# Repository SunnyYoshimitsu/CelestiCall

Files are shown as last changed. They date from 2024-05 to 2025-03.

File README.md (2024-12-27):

# CelestiCall
 An attempt at making a somewhat modern smartphone with many functions. 

CelestiCall is a phone with a somewhat outdated concept that I've come up with for the Summer of 2024. The purpose of the phone? to allow me to learn and get experience on many computer subjects all at once. 
And what are those "experience" and "subjects" I'm talking about? They're power system design, FPGA design, 3D printing, communication, Linux, web design and many more.

Let me tell about what I see this phone will have as I want this to be unique and with quite a large amount of personal touch up. 
1) This phone will be running on an FPGA, specifically Zynq FPGAs. This is because I want to learn about how to create a whole SoC from scratch (with a hardcore A9 of course), as this will teach me about the SoC design and more. 
2) It will serve as both a phone and as a portable small Linux computer with HDMI. This is one reason why I said the concept is a little outdated as many modern phone can just screen share to TV and call it a day. However since my phone won't be in any of the TV's ecosystem, I will "cheat" and have it "screen-share" via HDMI. My inspiration is the ChromeBit and the Motorola Atrix HD.
3) I also will have a web "program" very much similar to what ChromeOS offer but obviously way more bootleg as it will be made by one person. This is a way that I will be able to artificially extend the power of the little device by having many computing heavy problems or storage be on the cloud. 

Here I'll go into a personal requirement for what I think the smartphone should be and have. I'll describe the software and the hardware along with the type of apps I would like to have running on it.

Requirement: 
* Interaction : All modern smartphone have touchscreens and really that's one of the reason that started the smartphone trend. I might add some physical buttons but that's up for considerations.
* 
* Communication : A phone is not a phone if one can't call from it. I'll make the phone being able to use 4G and possibly 5G as 3G and below at least in the US is defunct. Also this hopefully will allow the phone to access the internet.
* 
* Usage Time : The target is the battery lasting up to a whole day on a single charge on heavy use. I will go into what "heavy use" entails later.
* 
* Operating System : Linux is a must and also more like an existing distro. If possible and if the system is powerful enough I might use Android(possibly 2.0) since I don't have the manpower to make my own softwares.
There wil be this much requirement for now, it might be changed later.

Hardware: 
Physical dimesion: Similar to that of Iphone I or the various Window phones. 
                   Small and comact as to be able to reach from bottom of the screen to the top. 
                   
Computer Hardware: Runs off dual Cortex A9 on an FPGA and hopefully give up to 2GB of RAM. 
                   ARM A9 is a relative strong chips that could run many lightweight Linux distro without much problem. 

Software: 
Onboard-based: Android 2.0 would be preferrable
               It's a widely used distro with a lot of available softwares
               
Web-based: Something like a personal/homebrew Google Drive and the ability to use a home server as extra computing extension and a NAS as online hard-drive. 
           This would allow the device to be more than it can be

Here's the architecture of the SoC would look like: 
Note: if there's an asterisk, it means that that specific part will be custom. 
CelestiSoC

Roadmap

*Software to make calls, use WiFi, send/receive SMS, GPS and take photos in any GNU/linux:
    Estimated Time: ~5 months
    
    With hardware:
                  A7670G with ESP32: https://github.com/Xinyuan-LilyGO/LilyGO-T-A76XX
                  Quectel: https://www.aliexpress.us/item/3256806123411827.html?src=google&gatewayAdapt=glo2usa
    With software: 
                  Android 5 for Zedboard: https://github.com/noritsuna/zedroid_system_core?tab=readme-ov-file
                  Android 4 for Pynq Z2: https://xilinx-wiki.atlassian.net/wiki/spaces/A/pages/18842042/Android+4.2.2+On+Zynq+Getting+Started+Guide
                  AT commands for the GPRS 
                  Arduino C codes for ESP32 wiFi and BLE

*Touchscreen, buttons and audio I/Os:
    Estimated Time: ~2 months

    Note: as of 5/23/2024, I'm still deciding whether to pursue a phone with large or small screens. They could be as large as a modern Iphone Pro Max with screen going up to near 7inch or older phones with screen as small as 3-inch diagnally. 

    With hardware: 
                 Small 3.1 in screen: https://tailorpixels.com/product/3-1-inch-ips-tft-high-resolution-mipi/
                 Medium sized 5 in screen: https://tailorpixels.com/product/5-inch-tn-tft-lcd-rgb-800x480-landscape/
                 Large sized 7 in screen: https://tailorpixels.com/product/7-inch-tn-tft-lcd-rgb-800x480/
    With software: 
                 -For starter: a framebuffer in RAM
                 -End goal: running on a custom GPU (HyperNova)

The above two steps will be prototyped via COTS development boards and easy to use breadboard.

*Make a prototype PCB with components:

    Estimated Time: ~2 months 
    Estimated cost: ~$400

    1) Start with a simple FPGA board
    2) Add peripherals like the WiFI, GPRS and camera
    3) Add touchscreen and physical input (buttons)

 *Design and manufacture outer shell:
    Estimated Time: ~2 months
    Estimated cost: ~$50

    Design concept: The shell of the phone will be somewhat similar looking to any modern smartphone, however it will be thicker than the norm. This is to be able to accomodate at least two full size USB and HDMI ports along with possibly 2 PMODs interface. 

    With hardware: 
                 Bambu Lab 3D printer
    With software: 
                 Krita for concept art
                 Solidwork for the end product

 *End Step: 
    This step will involve the creation of the "bootleg Google Drive" that I've detailed in the beginning along with making a case for the phone.
     
Rough Project Timeline/Plans:
Rough Project Timeline

To do list/learn/plan(6/17):

Start making prototypes of the GPU and the Audio mixer
Then integrate them to a HDMI output

GPU: Learn about "CUDA" cores, make a RGB framebuffer of 800 x 600 size for the touchscreen output. Make variable screen resolution for HDMI out. 
Audio: extend upon school filter projects and DMA sound replay. 
       If too complicated, then make a simple PCM passthrough and FIFO for sound replay from memory. 

Integrate both GPU and Audio though the HyperNova top module to output to HDMI, display and audio jack. Add controls to allow versatile displaying. 
Possibly add possible VGA output for second display via the PMOD (max 64 colors only). 

I know this sounds ambitious as going to the moon by oneself. HOWEVER, with the way technology is evolving, I believe it's possible....Please let a student dream.....

Email: huynguyenwork123@gmail.com

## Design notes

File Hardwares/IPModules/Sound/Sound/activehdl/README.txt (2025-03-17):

################################################################################
# Vivado (TM) v2023.2 (64-bit)
#
# README.txt: Please read the sections below to understand the steps required to
#             run the exported script and how to fetch design source file details
#             from the file_info.txt file.
#
# Generated by export_simulation on Thu Jan 09 14:43:12 -0800 2025
#
################################################################################

1. Steps to run the generated simulation script

From the shell prompt in the current directory, issue the following command:-

./I2S_Mic_Wrapper.sh

This command will launch the 'compile', 'elaborate' and 'simulate' functions
implemented in the script file for the 3-step flow. These functions are called
from the main 'run' function in the script file.

The 'run' function first calls the 'check_args' function, the purpose of which
is to verify the generated script arguments and print error if incorrect switch
is specified. The 'run' function then calls the 'setup' function, the purpose of
which is to specify custom or initialization commands. The function also executes
following sub-functions:-
'reset_run' if -reset_run switch is specified.
'reset_log' if -reset_log switch is specified.

The purpose of 'reset_run' function' is to delete the simulator generated design
data from the previous run and the purpose of 'reset_log' function' is to delete
the simulator generated log files.

The 'run' function then calls the 'init_lib' function, the purpose of which is to
create design library mappings and directories. This function is called before the
'compile' step. By default, if '-step' switch is specified with the script then the
script will execute that specfic step, else it will execute all steps applicable
for the target simulator.

For more information on the script, please type './I2S_Mic_Wrapper.sh -help'

2. Design source file information

export_simulation generates a 'file_info.txt' file that contains design file information
based on the compile order when export_simulation was executed from Vivado. The file
contains information about the file name, type, library it is compiled into, whether
it is part of the IP, associated library, file path information in a comma separated
format. This file can be parsed to extract the required information for generating a
custom script or can be read from verification test infra.

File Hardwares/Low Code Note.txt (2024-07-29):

This folder will be for lower-level codes and developments like VHDL and Embedded C for smaller MCUs. Anything that is conventionally regarded as "hardware" or "Embedded programming" will be here. 

*Use LOLIN C3 Mini when programming the ESP32C3 SuperMini

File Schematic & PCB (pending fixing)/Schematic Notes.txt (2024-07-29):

7/16/2024:
The schematic and PCB have been updated and will be kept up to date in this folder. 

Changes for schematic involve removals of all former peripheral chips due to space constraints, low energy budget, and generally low utilities. 

Changes for PCB include 10% smaller sizes, more efficient/shorter traces, and new chip placements. 

7/28/2024:
Changed the SIM socket to a smaller one and fixed its direction

Add another PMOD plug and change both to SMD instead of through hole to allow for more space on the bottom side of PCB

Add more connection to the external MCU to allow usage of more types of MCU like ESP32s3 XIAO. 

Note: I've tried to explore some more external interfaces like a Mini PCIE on the side and M.2 slots. There are chances that I might try these ideas in the future. 
By the look of the direction of the project, I'm expecting the phone to be at least somewhat similar in performance to an iPhone 4G. The reason for this expectation
is due to both running the same CPU except the slower speed on my device.

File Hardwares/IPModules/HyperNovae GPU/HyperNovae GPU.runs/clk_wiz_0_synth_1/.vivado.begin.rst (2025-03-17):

<?xml version="1.0"?>
<ProcessHandle Version="1" Minor="0">
    <Process Command="vivado.bat" Owner="Hatsu" Host="DESKTOP-I4589KT" Pid="33956" HostCore="12" HostMemory="034246979584">
    </Process>
</ProcessHandle>

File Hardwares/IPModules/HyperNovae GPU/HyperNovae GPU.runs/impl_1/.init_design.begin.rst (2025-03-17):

<?xml version="1.0"?>
<ProcessHandle Version="1" Minor="0">
    <Process Command=".planAhead." Owner="Hatsu" Host="DESKTOP-I4589KT" Pid="7728">
    </Process>
</ProcessHandle>

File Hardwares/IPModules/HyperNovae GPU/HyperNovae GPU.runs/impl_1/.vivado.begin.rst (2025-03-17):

<?xml version="1.0"?>
<ProcessHandle Version="1" Minor="0">
    <Process Command="vivado.bat" Owner="Hatsu" Host="DESKTOP-I4589KT" Pid="32244" HostCore="12" HostMemory="034246979584">
    </Process>
</ProcessHandle>
<?xml version="1.0"?>
<ProcessHandle Version="1" Minor="0">
    <Process Command="vivado.bat" Owner="Hatsu" Host="DESKTOP-I4589KT" Pid="8500" HostCore="12" HostMemory="034246979584">
    </Process>
</ProcessHandle>
<?xml version="1.0"?>
<ProcessHandle Version="1" Minor="0">
    <Process Command="vivado.bat" Owner="Hatsu" Host="DESKTOP-I4589KT" Pid="32320" HostCore="12" HostMemory="034246979584">
    </Process>
</ProcessHandle>
<?xml version="1.0"?>
<ProcessHandle Version="1" Minor="0">
    <Process Command="vivado.bat" Owner="Hatsu" Host="DESKTOP-I4589KT" Pid="15256" HostCore="12" HostMemory="034246979584">
    </Process>
</ProcessHandle>
<?xml version="1.0"?>
<ProcessHandle Version="1" Minor="0">
    <Process Command="vivado.bat" Owner="Hatsu" Host="DESKTOP-I4589KT" Pid="34104" HostCore="12" HostMemory="034246979584">
    </Process>
</ProcessHandle>
<?xml version="1.0"?>
<ProcessHandle Version="1" Minor="0">
    <Process Command="vivado.bat" Owner="Hatsu" Host="DESKTOP-I4589KT" Pid="35856" HostCore="12" HostMemory="034246979584">
    </Process>
</ProcessHandle>
<?xml version="1.0"?>
<ProcessHandle Version="1" Minor="0">
    <Process Command="vivado.bat" Owner="Hatsu" Host="DESKTOP-I4589KT" Pid="35372" HostCore="12" HostMemory="034246979584">
    </Process>
</ProcessHandle>
<?xml version="1.0"?>
<ProcessHandle Version="1" Minor="0">
    <Process Command="vivado.bat" Owner="Hatsu" Host="DESKTOP-I4589KT" Pid="36468" HostCore="12" HostMemory="034246979584">
    </Process>
</ProcessHandle>
<?xml version="1.0"?>
<ProcessHandle Version="1" Minor="0">
    <Process Command="vivado.bat" Owner="Hatsu" Host="DESKTOP-I4589KT" Pid="15448" HostCore="12" HostMemory="034246979584">
    </Process>
</ProcessHandle>
<?xml version="1.0"?>
<ProcessHandle Version="1" Minor="0">
    <Process Command="vivado.bat" Owner="Hatsu" Host="DESKTOP-I4589KT" Pid="36788" HostCore="12" HostMemory="034246979584">
    </Process>
</ProcessHandle>
<?xml version="1.0"?>
<ProcessHandle Version="1" Minor="0">
    <Process Command="vivado.bat" Owner="Hatsu" Host="DESKTOP-I4589KT" Pid="36724" HostCore="12" HostMemory="034246979584">
    </Process>
</ProcessHandle>
<?xml version="1.0"?>
<ProcessHandle Version="1" Minor="0">
    <Process Command="vivado.bat" Owner="Hatsu" Host="DESKTOP-I4589KT" Pid="10980" HostCore="12" HostMemory="034246979584">
    </Process>
</ProcessHandle>
<?xml version="1.0"?>
<ProcessHandle Version="1" Minor="0">
    <Process Command="vivado.bat" Owner="Hatsu" Host="DESKTOP-I4589KT" Pid="36556" HostCore="12" HostMemory="034246979584">
    </Process>
</ProcessHandle>
<?xml version="1.0"?>
<ProcessHandle Version="1" Minor="0">
    <Process Command="vivado.bat" Owner="Hatsu" Host="DESKTOP-I4589KT" Pid="18424" HostCore="12" HostMemory="034246979584">
    </Process>
</ProcessHandle>
<?xml version="1.0"?>
<ProcessHandle Version="1" Minor="0">
    <Process Command="vivado.bat" Owner="Hatsu" Host="DESKTOP-I4589KT" Pid="25948" HostCore="12" HostMemory="034246979584">
    </Process>
</ProcessHandle>
<?xml version="1.0"?>
<ProcessHandle Version="1" Minor="0">
    <Process Command="vivado.bat" Owner="Hatsu" Host="DESKTOP-I4589KT" Pid="34744" HostCore="12" HostMemory="034246979584">
    </Process>
</ProcessHandle>
<?xml version="1.0"?>
<ProcessHandle Version="1" Minor="0">
    <Process Command="vivado.bat" Owner="Hatsu" Host="DESKTOP-I4589KT" Pid="36200" HostCore="12" HostMemory="034246979584">
    </Process>
</ProcessHandle>
<?xml version="1.0"?>
<ProcessHandle Version="1" Minor="0">
    <Process Command="vivado.bat" Owner="Hatsu" Host="DESKTOP-I4589KT" Pid="35748" HostCore="12" HostMemory="034246979584">
    </Process>
</ProcessHandle>
<?xml version="1.0"?>
<ProcessHandle Version="1" Minor="0">
    <Process Command="vivado.bat" Owner="Hatsu" Host="DESKTOP-I4589KT" Pid="12492" HostCore="12" HostMemory="034246979584">
    </Process>
</ProcessHandle>
<?xml version="1.0"?>
<ProcessHandle Version="1" Minor="0">
    <Process Command="vivado.bat" Owner="Hatsu" Host="DESKTOP-I4589KT" Pid="33684" HostCore="12" HostMemory="034246979584">
    </Process>
</ProcessHandle>
<?xml version="1.0"?>
<ProcessHandle Version="1" Minor="0">
    <Process Command="vivado.bat" Owner="Hatsu" Host="DESKTOP-I4589KT" Pid="17684" HostCore="12" HostMemory="034246979584">
    </Process>
</ProcessHandle>
<?xml version="1.0"?>
<ProcessHandle Version="1" Minor="0">
    <Process Command="vivado.bat" Owner="Hatsu" Host="DESKTOP-I4589KT" Pid="3300" HostCore="12" HostMemory="034246979584">
    </Process>
</ProcessHandle>
<?xml version="1.0"?>
<ProcessHandle Version="1" Minor="0">
    <Process Command="vivado.bat" Owner="Hatsu" Host="DESKTOP-I4589KT" Pid="35892" HostCore="12" HostMemory="034246979584">
    </Process>
</ProcessHandle>
<?xml version="1.0"?>
<ProcessHandle Version="1" Minor="0">
    <Process Command="vivado.bat" Owner="Hatsu" Host="DESKTOP-I4589KT" Pid="36440" HostCore="12" HostMemory="034246979584">
    </Process>
</ProcessHandle>
<?xml version="1.0"?>
<ProcessHandle Version="1" Minor="0">
    <Process Command="vivado.bat" Owner="Hatsu" Host="DESKTOP-I4589KT" Pid="16936" HostCore="12" HostMemory="034246979584">
    </Process>
</ProcessHandle>
<?xml version="1.0"?>
<ProcessHandle Version="1" Minor="0">
    <Process Command="vivado.bat" Owner="Hatsu" Host="DESKTOP-I4589KT" Pid="34304" HostCore="12" HostMemory="034246979584">
    </Process>
</ProcessHandle>
<?xml version="1.0"?>
<ProcessHandle Version="1" Minor="0">
    <Process Command="vivado.bat" Owner="Hatsu" Host="DESKTOP-I4589KT" Pid="1524" HostCore="12" HostMemory="034246979584">
    </Process>
</ProcessHandle>
<?xml version="1.0"?>
<ProcessHandle Version="1" Minor="0">
    <Process Command="vivado.bat" Owner="Hatsu" Host="DESKTOP-I4589KT" Pid="35532" HostCore="12" HostMemory="034246979584">
    </Process>
</ProcessHandle>
<?xml version="1.0"?>
<ProcessHandle Version="1" Minor="0">
    <Process Command="vivado.bat" Owner="Hatsu" Host="DESKTOP-I4589KT" Pid="22812" HostCore="12" HostMemory="034246979584">
    </Process>
</ProcessHandle>
<?xml version="1.0"?>
<ProcessHandle Version="1" Minor="0">
    <Process Command="vivado.bat" Owner="Hatsu" Host="DESKTOP-I4589KT" Pid="17148" HostCore="12" HostMemory="034246979584">
    </Process>
</ProcessHandle>
<?xml version="1.0"?>
<ProcessHandle Version="1" Minor="0">
    <Process Command="vivado.bat" Owner="Hatsu" Host="DESKTOP-I4589KT" Pid="26016" HostCore="12" HostMemory="034246979584">
    </Process>
</ProcessHandle>
<?xml version="1.0"?>
<ProcessHandle Version="1" Minor="0">
    <Process Command="vivado.bat" Owner="Hatsu" Host="DESKTOP-I4589KT" Pid="14236" HostCore="12" HostMemory="034246979584">
    </Process>
</ProcessHandle>
<?xml version="1.0"?>
<ProcessHandle Version="1" Minor="0">
    <Process Command="vivado.bat" Owner="Hatsu" Host="DESKTOP-I4589KT" Pid="7360" HostCore="12" HostMemory="034246979584">
    </Process>
</ProcessHandle>
<?xml version="1.0"?>
<ProcessHandle Version="1" Minor="0">
    <Process Command="vivado.bat" Owner="Hatsu" Host="DESKTOP-I4589KT" Pid="7356" HostCore="12" HostMemory="034246979584">
    </Process>
</ProcessHandle>
<?xml version="1.0"?>
<ProcessHandle Version="1" Minor="0">
    <Process Command="vivado.bat" Owner="Hatsu" Host="DESKTOP-I4589KT" Pid="34080" HostCore="12" HostMemory="034246979584">
    </Process>
</ProcessHandle>
<?xml version="1.0"?>
<ProcessHandle Version="1" Minor="0">
    <Process Command="vivado.bat" Owner="Hatsu" Host="DESKTOP-I4589KT" Pid="35532" HostCore="12" HostMemory="034246979584">
    </Process>
</ProcessHandle>
<?xml version="1.0"?>
<ProcessHandle Version="1" Minor="0">
    <Process Command="vivado.bat" Owner="Hatsu" Host="DESKTOP-I4589KT" Pid="34820" HostCore="12" HostMemory="034246979584">
    </Process>
</ProcessHandle>
<?xml version="1.0"?>
<ProcessHandle Version="1" Minor="0">
    <Process Command="vivado.bat" Owner="Hatsu" Host="DESKTOP-I4589KT" Pid="8448" HostCore="12" HostMemory="034246979584">
    </Process>
</ProcessHandle>
<?xml version="1.0"?>
<ProcessHandle Version="1" Minor="0">
    <Process Command="vivado.bat" Owner="Hatsu" Host="DESKTOP-I4589KT" Pid="26908" HostCore="12" HostMemory="034246979584">
    </Process>
</ProcessHandle>
<?xml version="1.0"?>
<ProcessHandle Version="1" Minor="0">
    <Process Command="vivado.bat" Owner="Hatsu" Host="DESKTOP-I4589KT" Pid="17220" HostCore="12" HostMemory="034246979584">
    </Process>
</ProcessHandle>
<?xml version="1.0"?>
<ProcessHandle Version="1" Minor="0">
    <Process Command="vivado.bat" Owner="Hatsu" Host="DESKTOP-I4589KT" Pid="16024" HostCore="12" HostMemory="034246979584">
    </Process>
</ProcessHandle>
<?xml version="1.0"?>
<ProcessHandle Version="1" Minor="0">
    <Process Command="vivado.bat" Owner="Hatsu" Host="DESKTOP-I4589KT" Pid="7060" HostCore="12" HostMemory="034246979584">
    </Process>
</ProcessHandle>
<?xml version="1.0"?>
<ProcessHandle Version="1" Minor="0">
    <Process Command="vivado.bat" Owner="Hatsu" Host="DESKTOP-I4589KT" Pid="5208" HostCore="12" HostMemory="034246979584">
    </Process>
</ProcessHandle>
<?xml version="1.0"?>
<ProcessHandle Version="1" Minor="0">
    <Process Command="vivado.bat" Owner="Hatsu" Host="DESKTOP-I4589KT" Pid="6940" HostCore="12" HostMemory="034246979584">
    </Process>
</ProcessHandle>
<?xml version="1.0"?>
<ProcessHandle Version="1" Minor="0">
    <Process Command="vivado.bat" Owner="Hatsu" Host="DESKTOP-I4589KT" Pid="6084" HostCore="12" HostMemory="034246979584">
    </Process>
</ProcessHandle>
<?xml version="1.0"?>
<ProcessHandle Version="1" Minor="0">
    <Process Command="vivado.bat" Owner="Hatsu" Host="DESKTOP-I4589KT" Pid="2804" HostCore="12" HostMemory="034246979584">
    </Process>
</ProcessHandle>
<?xml version="1.0"?>
<ProcessHandle Version="1" Minor="0">
    <Process Command="vivado.bat" Owner="Hatsu" Host="DESKTOP-I4589KT" Pid="37344" HostCore="12" HostMemory="034246979584">
    </Process>
</ProcessHandle>
<?xml version="1.0"?>
<ProcessHandle Version="1" Minor="0">
    <Process Command="vivado.bat" Owner="Hatsu" Host="DESKTOP-I4589KT" Pid="22904" HostCore="12" HostMemory="034246979584">
    </Process>
</ProcessHandle>
<?xml version="1.0"?>
<ProcessHandle Version="1" Minor="0">
    <Process Command="vivado.bat" Owner="Hatsu" Host="DESKTOP-I4589KT" Pid="5032" HostCore="12" HostMemory="034246979584">
    </Process>
</ProcessHandle>
<?xml version="1.0"?>
<ProcessHandle Version="1" Minor="0">
    <Process Command="vivado.bat" Owner="Hatsu" Host="DESKTOP-I4589KT" Pid="35320" HostCore="12" HostMemory="034246979584">
    </Process>
</ProcessHandle>
<?xml version="1.0"?>
<ProcessHandle Version="1" Minor="0">
    <Process Command="vivado.bat" Owner="Hatsu" Host="DESKTOP-I4589KT" Pid="7100" HostCore="12" HostMemory="034246979584">
    </Process>
</ProcessHandle>
<?xml version="1.0"?>
<ProcessHandle Version="1" Minor="0">
    <Process Command="vivado.bat" Owner="Hatsu" Host="DESKTOP-I4589KT" Pid="9372" HostCore="12" HostMemory="034246979584">
    </Process>
</ProcessHandle>
<?xml version="1.0"?>
<ProcessHandle Version="1" Minor="0">
    <Process Command="vivado.bat" Owner="Hatsu" Host="DESKTOP-I4589KT" Pid="2136" HostCore="12" HostMemory="034246979584">
    </Process>
</ProcessHandle>
<?xml version="1.0"?>
<ProcessHandle Version="1" Minor="0">
    <Process Command="vivado.bat" Owner="Hatsu" Host="DESKTOP-I4589KT" Pid="30524" HostCore="12" HostMemory="034246979584">
    </Process>
</ProcessHandle>
<?xml version="1.0"?>
<ProcessHandle Version="1" Minor="0">
    <Process Command="vivado.bat" Owner="Hatsu" Host="DESKTOP-I4589KT" Pid="3408" HostCore="12" HostMemory="034246979584">
    </Process>
</ProcessHandle>
<?xml version="1.0"?>
<ProcessHandle Version="1" Minor="0">
    <Process Command="vivado.bat" Owner="Hatsu" Host="DESKTOP-I4589KT" Pid="17192" HostCore="12" HostMemory="034246979584">
    </Process>
</ProcessHandle>

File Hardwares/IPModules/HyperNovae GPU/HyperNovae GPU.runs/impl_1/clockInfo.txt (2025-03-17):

-------------------------------------
| Tool Version : Vivado v.2023.2
| Date         : Thu Jan  9 13:47:08 2025
| Host         : DESKTOP-I4589KT
| Design       : design_1
| Device       : xc7a100t-csg324-1--
-------------------------------------

For more information on clockInfo.txt clock routing debug file see https://support.xilinx.com/s/article/000035660?language=en_US

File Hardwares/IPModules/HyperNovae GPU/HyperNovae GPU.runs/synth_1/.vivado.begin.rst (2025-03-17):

<?xml version="1.0"?>
<ProcessHandle Version="1" Minor="0">
    <Process Command="vivado.bat" Owner="Hatsu" Host="DESKTOP-I4589KT" Pid="31948" HostCore="12" HostMemory="034246979584">
    </Process>
</ProcessHandle>

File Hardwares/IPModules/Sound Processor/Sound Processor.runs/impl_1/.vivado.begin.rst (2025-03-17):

<?xml version="1.0"?>
<ProcessHandle Version="1" Minor="0">
    <Process Command="vivado.bat" Owner="Hatsu" Host="DESKTOP-I4589KT" Pid="37040" HostCore="12" HostMemory="034246979584">
    </Process>
</ProcessHandle>
<?xml version="1.0"?>
<ProcessHandle Version="1" Minor="0">
    <Process Command="vivado.bat" Owner="Hatsu" Host="DESKTOP-I4589KT" Pid="37724" HostCore="12" HostMemory="034246979584">
    </Process>
</ProcessHandle>

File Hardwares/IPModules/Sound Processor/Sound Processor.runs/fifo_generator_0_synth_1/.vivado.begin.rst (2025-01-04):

<?xml version="1.0"?>
<ProcessHandle Version="1" Minor="0">
    <Process Command="vivado.bat" Owner="Hatsu" Host="DESKTOP-I4589KT" Pid="11940" HostCore="12" HostMemory="034246979584">
    </Process>
</ProcessHandle>

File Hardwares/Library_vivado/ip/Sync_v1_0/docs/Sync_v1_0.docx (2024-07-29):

# 1 Introduction

IP quick facts
Supported device families | Zynq®-7000, 7 series
Supported user interfaces | N/A

Provided with core
Design files | VHDL
Simulation model | VHDL Behavioral
Constraints file | XDC
Software driver | N/A

Tested design flows
Design entry | Vivado™ Design Suite 2015.3
Synthesis | Vivado Synthesis 2015.3

This user guide describes the Digilent Sync Intellectual Property. This IP provides clock domain crossing for signals where variable crossing latency does not affect functionality.

# 2 Features

- Brings global reset into a local clock domain where reset has to be synchronously de-asserted
- Brings asynchronous signal into a synchronous domain

# 3 Performance

No clock constraints are defined in this IP. Maximum frequency depends on the switching performance of flip-flops and the IP should not be the limiting factor in timing closure.

The IP properly defines false path constraints between source and destination clock domains.

# 4 Use cases

Figure 1. Sync internal diagram

The IP instantiates flip-flops and forms a chain that passes the input signal (iIn) towards the output (oOut). The first flip-flop is optional and works on the input (source) clock domain. It re-registers the input to make sure the downstream synchronizer chain has a glitch-free input. All the other flip-flops work on the output (destination) clock domain and each lowers the chance of failure due to metastability by increasing the time available for these events to settle. The number of synchronizer stages can be customized in the IP configuration wizard.

## Local reset

Consider a global reset signal that is asynchronous to a local clock domain you wish to reset. Depending on the application it might be important to de-assert the reset synchronous to the local clock, so that it can be guaranteed that all circuits come out of reset simultaneously. Reset assertion remains asynchronous, which is useful in cases where the local clock can be stopped.

Specify the correct polarity for the input reset signal in IP configuration and tie it to the aRst or aRst_n pin. Configure the output reset value to 0 or 1, depending on the desired polarity of the output reset signal. The input pin iIn should be tied to the constant inactive value of the output reset. Re-registering iIn is not required in this use case.

## Asynchronous input

Any input signal asynchronous to circuits it is connected to has the chance to become metastable. Using synchronizers lowers the chance of failure significantly. If the source clock of the input is known (synchronous to a known clock domain), tick “Re-register input on its source domain” and connect the source clock to InClk. If the source clock is not available, disable this option. Connecting a reset is optional and can be left unconnected.

# 5 Port Descriptions

Signal Name | Interface | Signal Type | Init State | Description
aRst(_n) | - | I | N/A | Asynchronous reset of configurable polarity. Optional
InClk | - | I | N/A | Source clock for iIn. Optional
OutClk | - | I | N/A | Destination clock for oOut.
iIn | - | I | N/A | Input signal to be synchronized.
oOut | - | O | configurable | Input iIn synchronized to OutClk.

Table 1. Port descriptions.

# 6 Designing with the core

## Customization

The IP provides four customizable parameters: the polarity of reset signal, the reset value of oOut, option to re-register iIn, and the number of synchronizer stages to use.

Copyright Digilent, Inc. All rights reserved. Other product and company names mentioned may be trademarks of their respective owners. Page 2 of 3

DOC#: 516-003 Copyright Digilent, Inc. All rights reserved. Other product and company names mentioned may be trademarks of their respective owners. Page 1 of 3

Sync 1.0 IP Core User Guide

1300 Henley Court Pullman, WA 99163 509.334.6306 www.digilentinc.com Sync 1.0 IP Core User Guide Revised October 7, 2016; Author Elod Gyorgy

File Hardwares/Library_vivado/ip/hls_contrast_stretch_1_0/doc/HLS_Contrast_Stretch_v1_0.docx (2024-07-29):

# 1 Introduction

IP quick facts
Supported device families | Zynq®-7000, 7 series
Supported user interfaces | Axi-Lite Axi-Stream

Provided with core
Design files | C++
Simulation model | HLS Simulation
Constraints file | XDC
Software driver | Automatically generated

Tested design flows
Design entry | Vivado™ Design Suite 2017.4
Synthesis | Vivado Synthesis 2017.4

This user guide describes the Digilent Contrast Enhancement Intellectual Property. This IP interfaces to both the Axi-Lite and Axi-Stream in order to process a video stream and control the resolution and the contrast factor.

# 2 Features

- Axi- Stream 24-bit video input and output
- Axi-Lite interface for contrast and resolution control
- Resolution supported: up to 1920x1080/60Hz (clock: 148.5 MHz)
- Contrast adjustment based on programable minimum and maximum thresholds

# 3 Performance

The IP has been written in HLS with a target clock frequency of 150 MHz (6.67 ns) for a maximum resolution of 1920x1080. The maximum latency is at 2101693 ns with an initiation interval of 2101682 ns which is approximately one frame. The latency and initiation interval are scaled with the input resolution, meaning that a lower resolution the latency will also be lower.

# 4 Usage

The IP has been initially designed for a xc7z020clg400-1 target device, the resource usage for this FPGA are illustrated in

Name | BRAM-18K | DSP48E | FF | LUT
DSP | - | - | - | -
Expression | - | - | 0 | 8
FIFO | 0 | - | 125 | 572
Instance | 0 | 9 | 2969 | 4003
Memory | - | - | - | -
Multiplexer | - | - | - | -
Register | - | - | - | -
Total | 0 | 9 | 3094 | 4583
Utilization(%) | 0 | 4 | 2 | 8

Table 1 FPGA usage

# 5 Overview

The IP core has been written entirely in Vivado HLS by using the HLS Video Library provided by Xilinx and a custom contrast enhancement function written by the author. The enhancement is done by contrast stretching based on the minimum and maximum thresholds in absolute value. Thresholds and resolution are programable using AXI-Lite.

## Processing

The input format for the image/video stream is the Axi-stream interface which can accept 24 bits of RGB data (8 bit/color) respecting the Xilinx video format. Before the actual contrast enhancement, the input stream is converted in to a matrix format with de height and width corresponding to the resolution of the input image, this is done using the HLS Video Library function AXIvideo2cvMat. The obtained matrix is the RGB color space, to be able to change the contrast value without effecting the other components of the image a different color space hade to be chosen; based on the functions of the HLS Video Library the YCbCr color space has been chosen. Conversion from RGB to YCbCr is done using the CvtColor provided by the video library.

Once the contrast processing has been finished the image must be converted back to RGB color space and outputted to the Axi-Stream interface. The output Axi-Stream interface has the same format as the input Axi-Stream interface.

## Contrast stretch

This IP core performs contrast enhancement by using a simple linear contrast stretching algorithm which will set the every below the chosen minimum threshold to 0 and everything above the maximum threshold to 255, thus the histogram of the image is stretched. For a graphic representation of the algorithm please refer to the following figure.

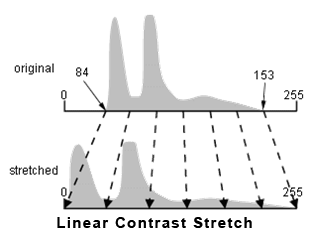
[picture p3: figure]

Figure 1. Contrast enhancement

Mathematically the function can be express by the following equation.

f(x)={, 0, &src.cont<min, ((src.cont-min))/((max-min))*255, &src.cont ∈[min;max], 255, &src.cont>max

## HLS directives

The used directives for this IP core have been added to the source files, for further information on how they work and how to use them please refer to UG902: High-Level Synthesis by Xilinx.

## Axi-Lite

The Axi-Lite interface is defined using HLS and controls three input variables of the main contrast stretching function. Using this interface, the user can change the resolution of both the input and the output image to a maximum of 1920x1080 and the desired contrast thresholds. Access to these parameters is provided via the automatically generated software driver, which respects the format of software drivers provided by Xilinx.

To change the minimum and the maximum thresholds, the function XHls_contrast_stretch_Set_min and XHls_contrast_stretch_CSet_max must be called.

# 6 Port Descriptions

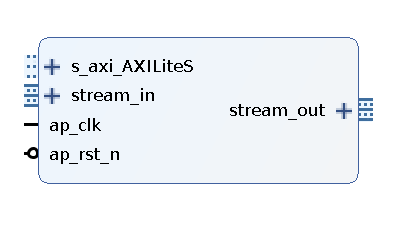
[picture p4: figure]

Figure 2 HLS Contrast Stretch IP core

Signal Name | Interface | Signal Type | Init State | Description
Ap_rst_n | - | I | N/A | Asynchronous reset for the core
ap_clk | - | I | N/A | Clock for the IP core, used for Stream in/output and Axi-Lite
s_axi_AXILiteS* | Axi-Lite | I | N/A | Axi-Lite interface used to configure height, width and contrast thresholds
stream_in | Axi-Stream | I | N/A | Input video stream on 24 bits, using Xilinx video format
stream_out | Axi-Stream | O | N/A | Output video stream on 24 bits, using Xilinx video format

Table 2. Port descriptions.

# 7 Designing with the core

## Customization

The currently IP core has been packaged for a maximum frequency of 150 MHz and a maximum resolution of 1920x1080 designed for a Zynq xc7z020clg400-1 device. Fur customization and further changes please create a HLS project and import all the files provided in the hls_src folder of the IP.

# 8 References

The following document provides additional information on the subjects discussed:

1. Xilinx Inc., UG902: High-Level Synthesis, v2017.4, February 2, 2018.

Copyright Digilent, Inc. All rights reserved. Other product and company names mentioned may be trademarks of their respective owners. Page 2 of 3

DOC#: 516-003 Copyright Digilent, Inc. All rights reserved. Other product and company names mentioned may be trademarks of their respective owners. Page 1 of 3

Sync 1.0 IP Core User Guide

1300 Henley Court Pullman, WA 99163 509.334.6306 www.digilentinc.com HLS Contrast Stretch 1.0 IP Core User Guide Revised June 21, 2018; Author Ciprian Hegbeli

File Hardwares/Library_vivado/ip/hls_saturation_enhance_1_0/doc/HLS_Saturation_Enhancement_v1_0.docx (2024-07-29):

# 1 Introduction

IP quick facts
Supported device families | Zynq®-7000, 7 series
Supported user interfaces | Axi-Lite Axi-Stream

Provided with core
Design files | C++
Simulation model | HLS Simulation
Constraints file | XDC
Software driver | Automatically generated

Tested design flows
Design entry | Vivado™ Design Suite 2017.4
Synthesis | Vivado Synthesis 2017.4

This user guide describes the Digilent Saturation Enhancement Intellectual Property. This IP interfaces to both the Axi-Lite and Axi-Stream in order to process a video stream and control the resolution and the saturation factor.

# 2 Features

- Axi- Stream 24-bit video input and output
- Axi-Lite interface for saturation and resolution control
- Resolution supported: up to 1920x1080/60Hz (clock: 148.5 MHz)
- Saturation adjustment: -0.2, 0.2, 0.4, 0.6, 0.8, 1.0, 1.2

# 3 Performance

The IP has been written in HLS with a target clock frequency of 150 MHz (6.67 ns) for a maximum resolution of 1920x1080. The maximum latency is at 2111405 ns with an initiation interval of 2111402 ns which is approximately one frame. The latency and initiation interval are scaled with the input resolution, meaning that a lower resolution the latency will also be lower.

# 4 Usage

The IP has been initially designed for a xc7z020clg400-1 target device, the resource usage for this FPGA are illustrated in

Name | BRAM-18K | DSP48E | FF | LUT
DSP | - | - | - | -
Expression | - | - | 0 | 8
FIFO | 0 | - | 115 | 532
Instance | 7 | 8 | 7850 | 6809
Memory | - | - | - | -
Multiplexer | - | - | - | -
Register | - | - | - | -
Total | 7 | 8 | 7965 | 7349
Utilization(%) | 2 | 3 | 7 | 13

Table 1 FPGA usage

# 5 Overview

The IP core has been written entirely in Vivado HLS by using the HLS Video Library provided by Xilinx and a custom saturation enhancement function written by the author. In order to minimize the resource cost of the IP core, the value of the saturation have been precompiled and stored in to lookup tables. The selection of the desired saturation is done using a simple case structure which multiplexes the LUTs which will be implemented.

## Processing

The input format for the image/video stream is the Axi-stream interface which can accept 24 bits of RGB data (8 bit/color) respecting the Xilinx video format. Before the actual saturation enhancement, the input stream is converted in to a matrix format with de height and width corresponding to the resolution of the input image, this is done using the HLS Video Library function AXIvideo2cvMat. The obtained matrix is the RGB color space, to be able to change the saturation value without effecting the other components of the image a different color space hade to be chosen; based on the functions of the HLS Video Library the HLS (hue, light saturation, aka HSL) color space has been chosen. Conversion from RGB to HLS is done using the CvtColor provided by the video library.

Once the saturation processing has been finished the image must be converted back to RGB color space and outputted to the Axi-Stream interface. The output Axi-Stream interface has the same format as the input Axi-Stream interface.

## Saturation Enhancement

The simplest way to enhance the saturation is to multiply it by a factor, unfortunately this leads to false colors and over saturation which should be avoided if the goal is to improve a undersaturated image.

In order to avoid this a couple of additional factor have been added to the equation for saturation enhancement.

The first thing that we must take in to account is that the saturation may not overflow, therefor the maximum variable interval for a saturation component must respect the following equation:

var_(interval) =(MaxSaturation-src.sat)

Equation 1 Max interval for each pixel

The second thing which must be taken in to account is that pixels with low saturation should not be over saturated. To avoid this another variable has been added to the above equation which ensures that undersaturated value will be proportionally saturated.

gray_(factor) =(src.sat)/255

Equation 2 Gray factor condition

When choosing to desaturate the input image these additional variables don’t have to be taken in to account, resulting in the following overall formula for the saturation enhancement.

dts.sat={, src.sat+fact*var_(interval) *gray_(interval) , &fact≥0, src.sat+fact*src.sat, &fact<0

Equation 3 Saturartion enhancement equation

Like previously mentioned the IP contain predefined LUT’s for some fact variable which have been calculated using this function which has been implemented in to the Test Bench of the HLS project. For a visual representation of the function with the chosen fact values of the LUTs please refer to the following chart

Figure 1 In/Out characteristic of saturation enhancement

## HLS directives

The used directives for this IP core have been added to the source files, for further information on how they work and how to use them please refer to UG902: High-Level Synthesis by Xilinx.

## Axi-Lite

The Axi-Lite interface is defined using HLS and controls three input variables of the main Saturation enhancement function. Using this interface, the user can change the resolution of both the input and the output image to a maximum of 1920x1080 and the desired saturation factor. Access to these parameters is provided via the automatically generated software driver, which respects the format of software drivers provided by Xilinx.

To change the saturation factor, the function XHls_saturation_enhance_Set_sat must be called. Saturation will change respecting the following rule:

Sat | Factor
0 | 0
1 | -0.2
2 | 0.2
3 | 0.4
4 | 0.6
5 | 0.8
6 | 1.0
7 | 1.2

Table 2 Saturation selection

# 6 Port Descriptions


Figure 2 HLS Saturation Enhancement IP core

Signal Name | Interface | Signal Type | Init State | Description
Ap_rst_n | - | I | N/A | Asynchronous reset for the core
ap_clk | - | I | N/A | Clock for the IP core, used for Stream in/output and Axi-Lite
s_axi_AXILiteS* | Axi-Lite | I | N/A | Axi-Lite interface used to configure height, width and saturation
stream_in | Axi-Stream | I | N/A | Input video stream on 24 bits, using Xilinx video format
stream_out | Axi-Stream | O | N/A | Output video stream on 24 bits, using Xilinx video format

Table 3. Port descriptions.

# 7 Designing with the core

## Customization

The currently IP core has been packaged for a maximum frequency of 150 MHz and a maximum resolution of 1920x1080 designed for a Zynq xc7z020clg400-1 device. Fur customization and further changes please create a HLS project and import all the files provided in the hls_src folder of the IP.

# 8 References

The following document provides additional information on the subjects discussed:

1. Xilinx Inc., UG902: High-Level Synthesis, v2017.4, February 2, 2018.

Copyright Digilent, Inc. All rights reserved. Other product and company names mentioned may be trademarks of their respective owners. Page 2 of 3

DOC#: 516-003 Copyright Digilent, Inc. All rights reserved. Other product and company names mentioned may be trademarks of their respective owners. Page 1 of 3

Sync 1.0 IP Core User Guide

1300 Henley Court Pullman, WA 99163 509.334.6306 www.digilentinc.com HLS Saturation Enhancement 1.0 IP Core User Guide Revised June 20, 2018; Author Ciprian Hegbeli

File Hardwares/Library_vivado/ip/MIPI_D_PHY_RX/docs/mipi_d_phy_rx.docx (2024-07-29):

# 1 Introduction

IP quick facts
Supported device families | Zynq®-7000, 7 series
Supported user interfaces | Xilinx®: AXI4-Lite, rx_mipi_ppi

Provided with core
Design files | VHDL
Simulation model | VHDL Behavioral
Constraints file | XDC
Software driver | standalone

Tested design flows
Design entry | Vivado™ Design Suite 2017.4
Synthesis | Vivado Synthesis 2017.4

This user guide describes the Digilent MIPI D-PHY Receiver Intellectual Property. This IP is compatible with D-PHY 1.0 specifications and serves as the lowest layer of the high-speed source-synchronous interface defined by MIPI Alliance. It pairs up with a MIPI CSI-2 Receiver IP over the standard PHY Protocol Interface (PPI) to receive data from an image sensor and source a video subsystem. The physical interconnect for Xilinx 7-series FPGA relies on techniques outlined in XAPP894[1].

# 2 Features

- Single or dual lane support
- CIL-SFEN, CIL-SCNN lane implementation: unidirectional, Control and High-Speed modes
- Xilinx interfaces used: AXI4-Lite, rx_mipi_ppi_if_rtl:1.0
- Debug module

# 3 Performance

The IP has been tested in dual-lane configuration with 1344 Mbps total data rate, resulting in 84 MHz PPI high-speed byte clock (RxByteClkHS).

# 4 Resource Utilization

Device | Configuration | Resource
| | LUT | FF | BRAM | URAM | DSP
xc7z020clg400-1 | AXI-Lite Interface | 297 | 312 | 0 | 0 | 0

# 5 Overview

Figure 1. DVI to VGA converter block diagram.

The IP is built from multiple blocks: input buffers, clock buffers, de-serializer, control logic and optional debug modules.

# 6 Port Descriptions

Signal Name | Interface | Signal Type | Init State | Description
RefClk | - | I | N/A | 200 MHz reference clock.
aRst(_n) | - | I | N/A | Asynchronous reset of configurable polarity. Assert, if RefClk is not within spec.
rDlyCtrlLockedIn | - | I | N/A | Available when Shared Logic is not included in the IP. It is expected to have a single master instance of D-PHY IP in the design with Shared Logic included. The port rDlyCtrlLockedOut from the master block should drive all the rDlyCtrlLockedIn ports of the slave instances (see below).
rDlyCtrlLockedOut | - | O | 0 | Available when Shared Logic is included in the IP. An IDELAYCTRL block with proper reset circuitry will be instantiated, which will manage all the IDELAY components of all the D-PHY instances in the design. The port rDlyCtrlLockedOut from the master block should drive all the rDlyCtrlLockedIn ports of the slave instances (see above).

# 7 Designing with the core

The IP expects to be connected directly to top-level ports, since input buffers are instantiated internally. Since the D-PHY I/O standard is not supported directly by FPGA pins, it implements the techniques described in [1] that separate the D-PHY lane into a differential high-speed bus (LVDS_25) and two low-power control signals (HSUL_12). It was verified as working with either passive or active termination. This implementation allows 3.3V-supplied HR banks to interface with D-PHY transmitters using external on-board terminations and internal voltage reference.

## Constraints

See an example below on how to constrain the low-power (LP) and high-speed (HS) input pins. Banks hosting HSUL_12 pins need a 0.6V voltage reference, either internal or external. A primary clock with a frequency corresponding to the maximum expected data rate should be created on the clock input port.

set_property INTERNAL_VREF 0.6 [get_iobanks 35]

set_property -dict {PACKAGE_PIN J19 IOSTANDARD HSUL_12} [get_ports dphy_clk_lp_n]

set_property -dict {PACKAGE_PIN H20 IOSTANDARD HSUL_12} [get_ports dphy_clk_lp_p]

set_property -dict {PACKAGE_PIN M18 IOSTANDARD HSUL_12} [get_ports {dphy_data_lp_n[0]}]

set_property -dict {PACKAGE_PIN L19 IOSTANDARD HSUL_12} [get_ports {dphy_data_lp_p[0]}]

set_property -dict {PACKAGE_PIN L20 IOSTANDARD HSUL_12} [get_ports {dphy_data_lp_n[1]}]

set_property -dict {PACKAGE_PIN J20 IOSTANDARD HSUL_12} [get_ports {dphy_data_lp_p[1]}]

set_property -dict {PACKAGE_PIN H18 IOSTANDARD LVDS_25} [get_ports dphy_hs_clock_clk_n]

set_property -dict {PACKAGE_PIN J18 IOSTANDARD LVDS_25} [get_ports dphy_hs_clock_clk_p]

# 672Mbps/lane = 336 MHz HS_Clk

create_clock -period 2.976 -name dphy_hs_clock_p -waveform {0.000 1.488} [get_ports dphy_hs_clock_clk_p]

set_property -dict {PACKAGE_PIN M20 IOSTANDARD LVDS_25} [get_ports {dphy_data_hs_n[0]}]

set_property -dict {PACKAGE_PIN M19 IOSTANDARD LVDS_25} [get_ports {dphy_data_hs_p[0]}]

set_property -dict {PACKAGE_PIN L17 IOSTANDARD LVDS_25} [get_ports {dphy_data_hs_n[1]}]

set_property -dict {PACKAGE_PIN L16 IOSTANDARD LVDS_25} [get_ports {dphy_data_hs_p[1]}]

## Customization

# 8 Debugging

# 9 References

1. Xilinx Inc., XAPP894: D-PHY Solutions, v1.0, August 25, 2014.

Copyright Digilent, Inc. All rights reserved. Other product and company names mentioned may be trademarks of their respective owners. Page 2 of 3

DOC#: 516-000 Copyright Digilent, Inc. All rights reserved. Other product and company names mentioned may be trademarks of their respective owners. Page 1 of 3

MIPI D-PHY Receiver 1.0 IP Core User Guide

1300 Henley Court Pullman, WA 99163 509.334.6306 www.digilentinc.com MIPI D-PHY Receiver 1.3 IP Core User Guide Revised December 5, 2018; Author Elod Gyorgy

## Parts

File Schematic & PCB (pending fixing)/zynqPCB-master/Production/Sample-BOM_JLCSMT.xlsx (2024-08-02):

Comment | Designator | Footprint | JLCPCB Part #（optional）
gsm | AE1 | Y!:IPEX
.47uF | C1, C4, C8, C14, C15, C17, C23, C29, C30, C31, C34, C46, C47, C50, C55, C65, C92, C101, C102, C103, C104, C107, C108, C116, C117, C119, C121 | Capacitor_SMD:C_0402_1005Metric
10uF | C2, C3, C10, C11, C13, C21, C26, C33, C41, C51, C54, C58, C60, C90, C91, C125, C126, C128, C129, C130 | Capacitor_SMD:C_0603_1608Metric
4.7uF | C5, C9, C19, C20, C24, C27, C42, C57, C59, C66, C100, C114, C115, C122, C124, C127 | Capacitor_SMD:C_0402_1005Metric
100uF | C6, C12, C25, C28, C43, C67, C69, C73, C74, C99, C123 | Capacitor_SMD:C_1210_3225Metric
47uF | C7, C32, C61 | Capacitor_SMD:C_0805_2012Metric
100nF | C16, C64 | Capacitor_SMD:C_0805_2012Metric
330uF | C22, C132 | Capacitor_SMD:C_1206_3216Metric
2.2uF | C35 | Capacitor_SMD:C_0402_1005Metric
.1uF | C36, C37, C39, C52, C53, C56, C62, C68, C70, C71, C72, C94, C95, C96, C97, C131 | Capacitor_SMD:C_0402_1005Metric
1uF | C38, C45 | Capacitor_SMD:C_0402_1005Metric
100uF | C40, C44 | Capacitor_Tantalum_SMD:CP_EIA-6032-15_Kemet-U
220uF Tant. | C48, C49 | Capacitor_Tantalum_SMD:CP_EIA-3528-12_Kemet-T
10uF | C63 | Capacitor_SMD:C_0805_2012Metric
33pF | C88 | Capacitor_SMD:C_0805_2012Metric
10pF | C89 | Capacitor_SMD:C_0805_2012Metric
.01uF | C93, C98, C105, C106, C109, C110, C120 | Capacitor_SMD:C_0402_1005Metric
47uF | C113 | Capacitor_SMD:C_1210_3225Metric
22pF | C133, C134, C135 | Resistor_SMD:R_0805_2012Metric
AVR-JTAG-10 | CON1 | DFTcustom:XilinxJTAG
5.1V | D2 | Diode_SMD:D_SOD-123
BLUE LED | D3, D7 | Capacitor_SMD:C_0603_1608Metric
ESD9B5.0ST5G | D8, D9 | Diode_SMD:D_SOD-923
120R, 100 MHz, size 0603 | FB1 | Capacitor_SMD:C_0603_1608Metric
GNDTIE | GT1 | DFTcustom:gndtie
SIM7100-6-1-15-00-A_REVC | J1 | Y!:nanoSIM
USB_A | J2, J6 | DFTcustom:USB-A-Receptacle-FCI_87583
Conn_02x20_Top_Bottom | J3 | Connector_FFC-FPC:TE_4-1734839-0_1x40-1MP_P0.5mm_Horizontal
Conn_01x06_Female | J4 | Connector_FFC-FPC:Hirose_FH12-6S-0.5SH_1x06-1MP_P0.50mm_Horizontal
JACK_TRS_4PINS | J5 | DFTcustom:SJ-352X-SMT
Micro_SD_Card_Det | J8 | DFTcustom:AMPHENOL-114-00841-68
HDMI_A | J9 | DFTcustom:10029449-111RLF
2.2uH | L1, L2, L3, L4, L5 | Capacitor_SMD:C_1812_4532Metric
MEMSMIC | MIC1 | SPW2430HR5H-B:MIC_SPW2430HR5H-B
PMOD-Host-x2-GPIO | PMOD1, PMOD2 | Y!:SAMTEC-SMH-106-02-X-D
NDT452AP | Q1 | Package_TO_SOT_SMD:SOT-223-3_TabPin2
MMBTA14-7-F | Q2, Q4 | Package_TO_SOT_SMD:SOT-23-3
100k | R1, R2, R3, R4, R5, R23, R24, R28, R34, R81, R101 | Resistor_SMD:R_0402_1005Metric
10k | R6, R33 | Resistor_SMD:R_0402_1005Metric
240 1% | R7, R46, R49 | Resistor_SMD:R_0402_1005Metric
4.7k | R8, R9, R10, R12, R14, R27, R74, R82, R83, R98, R103, R104 | Resistor_SMD:R_0402_1005Metric
49.9k | R16, R17, R31 | Resistor_SMD:R_0402_1005Metric
22R | R18, R22, R30, R32, R42 | Resistor_SMD:R_0805_2012Metric
20k | R25, R29, R91, R92, R93, R94, R95, R96, R97, R106 | Resistor_SMD:R_0402_1005Metric
150 | R35, R102 | Resistor_SMD:R_0402_1005Metric
10k 1% | R47, R48 | Resistor_SMD:R_0402_1005Metric
80.6 1% | R50, R75, R76 | Resistor_SMD:R_0402_1005Metric
40.2 1% | R51, R52, R53, R54, R55, R56, R57, R58, R59, R60, R61, R62, R63, R64, R65, R66, R67, R68, R69, R70, R71, R72, R73 | Resistor_SMD:R_0402_1005Metric
0.05 | R88, R89, R90 | Resistor_SMD:R_2512_6332Metric
47k | R99 | Resistor_SMD:R_0402_1005Metric
24.9 1% | R100 | Resistor_SMD:R_0402_1005Metric
D | S8KC-13 | Diode_SMD:D_SMC
LM3880 | U1, U2 | Package_TO_SOT_SMD:SOT-23-6
SC189 - 1.0V | U3 | Package_TO_SOT_SMD:SOT-23-5
SC189 - 3.3V | U4 | Package_TO_SOT_SMD:SOT-23-5
TLV62080DSGx | U5 | Package_SON:WSON-8-1EP_2x2mm_P0.5mm_EP0.9x1.6mm
TPS62132 | U6 | Package_DFN_QFN:VQFN-16-1EP_3x3mm_P0.5mm_EP1.68x1.68mm_ThermalVias
SC189 - 1.8V | U7 | Package_TO_SOT_SMD:SOT-23-5
TPS51200DRCR | U8 | Package_SON:VSON-10-1EP_3x3mm_P0.5mm_EP1.65x2.4mm_ThermalVias
TLV320AIC3104 | U9 | Package_DFN_QFN:QFN-32-1EP_5x5mm_P0.5mm_EP3.65x3.65mm
MIC2025-1YMM | U11 | SOP65P490X110-8N:SOP65P490X110-8N
 | U12 | Y!:Micro Lipo
SIM_COM_A7670 | U13 | Y!:A7670C
ESP32-C3_SUPERMINI | U14 | Y!:MODULE_ESP32-C3_SUPERMINI
MT41K256M16HA-125_E | U15, U16 | DFTcustom:FBGA-96-DDR3-SDRAM
FTDITypeUART | U17 | DFTcustom:FTDI_CONN
ABRACON-ASDMB | U18 | XTAL_ASDMB-24.000MHZ-LC-T:XTAL_ASDMB-24.000MHZ-LC-T
S25FL256SAGNFI001 | U19 | footprints:Cypress-002-18827-0-0-0
xc7z020clg484 | U20 | DFTcustom:BGA-484_19.0x19.0mm_Layout22x22_P0.80mm_dia0.40mm
PCA9306 | U21 | Package_SO:SSOP-8_2.95x2.8mm_P0.65mm

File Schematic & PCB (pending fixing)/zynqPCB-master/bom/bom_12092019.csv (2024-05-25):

Refs | Value | Footprint | Quantity | MFR | MPN | SPR | SPN
Y1;Y2 | 24.000MHZ | ABM3-12.000MHZ-B2-T:XTAL500X320X130N | 2 | Abracon LLC | ABM3-24.000MHZ-D2Y-T | DigiKey | 535-10643-2-ND
C106;C105;C98;C93;C109;C110;C120;C111 | .01uF | Capacitor_SMD:C_0402_1005Metric | 8 | Murata | GRM155R71H103KA88J | Digikey | 490-6351-1-ND
C68;C70;C71;C77;C72;C79;C81;C82;C86;C131;C97;C96;C95;C94;C88;C16;C107;C36;C64;C63;C52;C56;C53;C62;C39 | .1uF | Capacitor_SMD:C_0402_1005Metric | 25 | Murata | GRM188R71C104KA01D | Digikey | 490-1532-1-ND
C65;C78;C87;C34;C18;C17;C15;C14;C29;C30;C31;C23;C8;C4;C1;C108;C116;C117;C118;C119;C104;C103;C102;C101;C121;C55;C50;C47;C46 | .47uF | Capacitor_SMD:C_0402_1005Metric | 29 | Murata | GRM188R71C474KA88D | Digikey | 490-3295-1-ND
C76;C75;C85;C84 | 18pF | Capacitor_SMD:C_0402_1005Metric | 4 | Murata | GCM1555C1H180JA16D | Digikey | 490-12650-1-ND
C91;C92;C37;C40;C38;C45;C43;C44 | 1uF | Capacitor_SMD:C_0402_1005Metric | 8 | Murata | GRM188R71C105KE15D | Digikey | 490-10734-1-ND
C69;C80;C35 | 2.2uF | Capacitor_SMD:C_0402_1005Metric | 3 | Murata | GRM155R61A225KE95D | Digikey | 490-10451-1-ND
C66;C83;C20;C19;C24;C27;C9;C5;C114;C115;C100;C127;C122;C89;C21;C42;C59;C57 | 4.7uF | Capacitor_SMD:C_0402_1005Metric | 18 | Murata | GRM21BR61A475KA73L | Digikey | 490-9750-1-ND
C3;C13;C2;C10;C11;C26;C33;C126;C125;C130;C129;C128;C90;C54;C58;C51;C41;C60 | 10uF | Capacitor_SMD:C_0603_1608Metric | 18 | Murata | GRM21BR61A106KE19L | Digikey | 490-1709-1-ND
FB1 | 120R, 100 MHz, size 0603 | Capacitor_SMD:C_0603_1608Metric | 1 | Murata Electronics | BLM18AG121SN1D | Digikey | 490-1011-1-ND
D3;D5;D4;D6;D7 | BLUE LED | Capacitor_SMD:C_0603_1608Metric | 5 | Vishay Semiconductors | VLMB1300-GS08 | Digikey | VLMB1300-GS08CT-ND
C32;C7;C61 | 47uF | Capacitor_SMD:C_0805_2012Metric | 3 | Murata Manufacturing Co Ltd | GRM32ER70J476ME20L | Digikey | 490-6542-1-ND
C22 | 330uF | Capacitor_SMD:C_1206_3216Metric | 1 | AVX Corporation | F950G337MAAAQ2 | Digikey | 478-8378-1-ND
C67;C73;C74;C28;C25;C12;C6;C99;C123 | 100uF | Capacitor_SMD:C_1210_3225Metric | 9 | TAIYO YUDEN | JMK325ABJ107MM-P | Digikey | 587-4313-1-ND
C113 | 47uF | Capacitor_SMD:C_1210_3225Metric | 1 | Murata Manufacturing Co Ltd | GRM32ER70J476ME20L | Digikey | 490-6542-1-ND
L2;L3;L4;L1 | 2.2uH | Capacitor_SMD:C_1812_4532Metric | 4 | Murata | LQH43PN2R2M26L | Digikey | 490-12049-1-ND
C49;C48 | 220uF Tant. | Capacitor_Tantalum_SMD:CP_EIA-3528-12_Kemet-T | 2 | AVX Corporation | F930G227KBA | Digikey | 478-8139-1-ND
J7 | USB_B | Connector_USB:USB_B_OST_USB-B1HSxx_Horizontal | 1 | On Shore Technology | USB-B1HSW6 | Digikey | ED2982-ND
J9 | HDMI_A | DFTcustom:10029449-111RLF | 1 | Amphenol ICC | 10029449-111RLF | Digikey | 609-4614-1-ND
J8 | Micro_SD_Card_Det | DFTcustom:AMPHENOL-114-00841-68 | 1 | Amphenol ICC | 114-00841-68 | Digikey | 114-00841-68-1-ND
U14 | APDS-9960 | DFTcustom:APDS_9960 | 1 | Broadcom Limited | APDS-9960 | Digikey | 516-3480-1-ND
XA1 | Arduino_Uno_Shield_Simplified | DFTcustom:Arduino_Uno_Shield_Simplified | 1 | DNS | - | - | -
U20 | xc7z020clg484 | DFTcustom:BGA-484_19.0x19.0mm_Layout22x22_P0.80mm_dia0.40mm | 1 | Xilinx | XC7Z020-1CLG484C | Digikey | 122-1850-ND
U15;U16 | MT41K256M16HA-125_E | DFTcustom:FBGA-96-DDR3-SDRAM | 2 | Micron | MT41K256M16TW-107 | Digikey | 557-2006-6-ND
U17 | FTDITypeUART | DFTcustom:FTDI_CONN | 1 | DNS | - | - | -
U22 | TSOP344 | DFTcustom:JUMPER_3PIN | 1 | Vishay Semiconductor | TSOP34438 | Digikey | TSOP34438-ND
U13 | VL53L1CXV0FY/1 | DFTcustom:Optical_LGA12 | 1 | STMicroelectronics | VL53L1CXV0FY/1 | Digikey | 497-17764-2-ND
D1;D2 | LED_RGB | DFTcustom:PLCC6-SM-RGB-LED | 2 | Cree, Inc. | CLP6C-FKB-CM1Q1H1BB7R3R3 | Digikey | CLP6C-FKB-CM1Q1H1BB7R3R3CT-ND
J4;J3;J2 | AUDIO JACK | DFTcustom:RA49C14B | 3 | Switchcraft Conxall | RA49C12B | Digikey | SC2083-ND
J5 | JACK_TRS_4PINS | DFTcustom:SJ-352X-SMT | 1 | CUI Inc. | SJ-3524-SMT-TR | Digikey | CP-3524SJCT-ND
J6 | USB_A | DFTcustom:USB-A-Receptacle-FCI_87583 | 1 | Amphenol ICC | 87583-2010RLF | Digikey | 609-5390-1-ND
MIC1 | MEMSMIC | DFTcustom:WM7121PE | 1 | Cirrus Logic | WM7121PIMSE/RV | Digikey | WM7121PIMSE/RVCT-ND
U19 | S25FL256SAGNFI001 | DFTcustom:WSON-8 | 1 | Cypress | S25FL256SAGNFI001 | Digikey | 1274-1005-ND
CON1 | AVR-JTAG-10 | DFTcustom:XilinxJTAG | 1 | DNS
GT1 | GNDTIE | DFTcustom:gndtie | 1 | DNS | - | - | -
SW1 | TL6215RF200BDT | DFTcustom:tl6215_right_angle | 1 | E-Switch Inc | TL6215RF200BDT | Digikey | EG5162-ND
U10;U12 | USB3320 | Package_DFN_QFN:QFN-32-1EP_5x5mm_P0.5mm_EP3.1x3.1mm | 2 | Microchip Technology | USB3320C-EZK-TR | Digikey | USB3320C-EZK-CT-NDs
U9 | TLV320AIC3104 | Package_DFN_QFN:QFN-32-1EP_5x5mm_P0.5mm_EP3.65x3.65mm | 1 | Texas Instruments | TLV320AIC3104IRHBR | Digikey | 296-26818-1-ND
U6 | LIS2HH12 | Package_LGA:LGA-12_2x2mm_P0.5mm | 1 | STMicroelectronics | LIS2HH12TR | Digikey | 497-15069-1-ND
U23 | LSM6DS3 | Package_LGA:LGA-14_3x2.5mm_P0.5mm_LayoutBorder3x4y | 1 | STMicroelectronics | LSM6DS3TR | Digikey | 497-15383-1-ND
U21 | PCA9306 | Package_SO:SSOP-8_2.95x2.8mm_P0.65mm | 1 | Texas Instruments | PCA9306DCTR | Digikey | 296-18509-2-ND
U8 | TPS51200DRCR | Package_SON:VSON-10-1EP_3x3mm_P0.5mm_EP1.65x2.4mm_ThermalVias | 1 | Texas Instruments | TPS51200DRCR | Digikey | 296-26978-1-ND
U5 | TLV62080DSGx | Package_SON:WSON-8-1EP_2x2mm_P0.5mm_EP0.9x1.6mm | 1 | Texas Instruments | TLV62080DSGR | Digikey | 296-39270-6-ND
Q9;Q8;Q10;Q7;Q5;Q3;Q1;Q6;Q4;Q2 | IRLML2502 | Package_TO_SOT_SMD:SOT-23 | 10 | Infineon Technologies AG | IRLML2502TRPBF | Digikey | IRLML2502PBFCT-ND
U3 | SC189 - 1.0V | Package_TO_SOT_SMD:SOT-23-5 | 1 | Semtech Corporation | SC189ASKTRT | Digikey | SC189ASKCT-ND
U7 | SC189 - 1.8V | Package_TO_SOT_SMD:SOT-23-5 | 1 | Semtech Corporation | SC189LSKTRT | Digikey | SC189LSKCT-ND
U4 | SC189 - 3.3V | Package_TO_SOT_SMD:SOT-23-5 | 1 | Semtech Corporation | SC189ZSKTRT | Digikey | SC189ZSKCT-ND
U1;U2 | LM3880 | Package_TO_SOT_SMD:SOT-23-6 | 2 | Texas Instruments | LM3880MF-1AE/NOPB | Digikey | LM3880MF-1AE/NOPBDKR-ND
R19;R20;R15;R13;R11;R22;R23;R16;R14;R12 | 100 | Resistor_SMD:R_0402_1005Metric | 10 | Yageo | RC0402FR-07100RL | Digikey | 311-100LRCT-ND
R1;R2;R3;R4;R5;R34;R81;R101;R27;R29;R17;R28 | 100k | Resistor_SMD:R_0402_1005Metric | 12 | Yageo | RC0402FR-07100KL | Digikey | 311-100KLRTR-ND
R36;R39;R33;R6;R42;R43;R44 | 10k | Resistor_SMD:R_0402_1005Metric | 7 | Yageo | RC0402FR-0710KL | Digikey | 311-10.0KLRTR-ND
R48;R47 | 10k 1% | Resistor_SMD:R_0402_1005Metric | 2 | Yageo | RC0402FR-0710KL | Digikey | 311-10.0KLRCT-ND
R35;R80;R78;R86;R102;R45;R21;R24 | 150 | Resistor_SMD:R_0402_1005Metric | 8 | Yageo | RC0402FR-07150RL | Digikey | 311-150LRTR-ND
R37;R40 | 1M | Resistor_SMD:R_0402_1005Metric | 2 | Yageo | RC0402FR-071ML | Digikey | 311-1.00MLRCT-ND
R79;R77;R85;R105 | 1k | Resistor_SMD:R_0402_1005Metric | 4 | Yageo | RC0402FR-071KL | Digikey | 311-1.00KLRCT-ND
R25;R96;R97;R95;R91;R92;R93;R94;R106 | 20k | Resistor_SMD:R_0402_1005Metric | 9 | Yageo | RT0402BRD0720KL | Digikey | YAG1388CT-ND
R100 | 24.9 1% | Resistor_SMD:R_0402_1005Metric | 1 | Yageo | RC0402FR-0724K9L | Digikey | 311-24.9KLRTR-ND
R7;R49;R46 | 240 1% | Resistor_SMD:R_0402_1005Metric | 3 | Yageo | RC0402FR-07240RL | Digikey | 311-240LRTR-ND
R9;R10;R8;R82;R83;R74;R98;R103;R104 | 4.7k | Resistor_SMD:R_0402_1005Metric | 9 | Yageo | RC0402JR-074K7L | Digikey | 311-4.7KJRCT-ND
R52;R51;R54;R53;R56;R55;R58;R57;R60;R59;R62;R61;R64;R63;R66;R65;R67;R68;R69;R70;R71;R72;R73 | 40.2 1% | Resistor_SMD:R_0402_1005Metric | 23 | Yageo | RC0402FR-0740R2L | Digikey | 311-40.2LRTR-ND
R26;R84;R87 | 47 | Resistor_SMD:R_0402_1005Metric | 3 | Yageo | RC0402JR-0747RL | Digikey | 311-47JRTR-ND
R99 | 47k | Resistor_SMD:R_0402_1005Metric | 1 | Yageo | RC0402FR-0747KL | Digikey | 311-47.0KLRTR-ND
R32;R30;R18;R31 | 49.9k | Resistor_SMD:R_0402_1005Metric | 4 | Yageo | RC0402FR-0749K9L | Digikey | 311-49.9KLRCT-ND
R38;R41 | 8.06k 1% | Resistor_SMD:R_0402_1005Metric | 2 | Yageo | RC0402FR-078K06L | Digikey | 311-8.06KLRTR-ND
R50;R75;R76 | 80.6 1% | Resistor_SMD:R_0402_1005Metric | 3 | Yageo | RC0402FR-0780R6L | Digikey | 311-80.6LRTR-ND
R90;R88;R89 | .05 | Resistor_SMD:R_2512_6332Metric | 3 | Bourns Inc | CRA2512-FZ-R050ELF | Digikey | CRA2512-FZ-R050ELFCT-ND
U11 | MIC2025-1YMM | SOP65P490X110-8N:SOP65P490X110-8N | 1 | Microchip | MIC2025-1YMM-TR | Digikey | MIC2025-1YMM-CT-ND
U18 | ABRACON-ASDMB | XTAL_ASDMB-24.000MHZ-LC-T:XTAL_ASDMB-24.000MHZ-LC-T | 1 | Abracon LLC | ASDMB-24.000MHZ-LC-T | Digikey | 535-11728-1-ND

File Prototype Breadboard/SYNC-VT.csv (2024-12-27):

Comment | Designator | Footprint
3225-4P 12MHz | Y1 | Crystal:Crystal_SMD_3225-4Pin_3.2x2.5mm
SIT8008BI-73-XXS-33.333333 | X1 | Oscillator:Oscillator_SMD_SeikoEpson_SG210-4Pin_2.5x2.0mm
USB_C_1 | USB_C_ESP1 | Connector_USB:USB_C_Receptacle_GCT_USB4105-xx-A_16P_TopMnt_Horizontal
SC189ZULTRT-3v3 | U11 | Package_TO_SOT_SMD:SOT-23-5
RP2040 | U9 | Package_DFN_QFN:QFN-56-1EP_7x7mm_P0.4mm_EP3.2x3.2mm
ZL6201A33S3 | U8 | Package_TO_SOT_SMD:SOT-23
S80KS5123GABHA020 | U7 | Sync_VT extras:PG-BGA-24-801
473092651 | U6 | Sync_VT extras:CONN12_47309-2651_MOL
W25Q128JVS | U5 | Package_SO:SOIC-8_5.23x5.23mm_P1.27mm
TPS3106K33DBVR | U4 | Sync_VT extras:DBV6-L
XC7Z010-1CLG225I | U3 | Sync_VT extras:225-LFBGA
MPM3834CGPA-Z | U1,U2 | Sync_VT extras:ECLGA-14_MPM3834C_MNP
TestPoint | TP6,TP7,TP8,TP9 | TestPoint:TestPoint_Pad_D1.5mm
TP | TP1,TP2,TP3,TP4,TP5,TP10,TP11 | TestPoint:TestPoint_Pad_1.0x1.0mm
DNP | R41,R42 | Capacitor_SMD:C_0402_1005Metric
10k | R4,R5,R6,R7,R9,R11,R12,R13,R15,R16,R17,R18,R19,R21,R22,R23,R24,R25,R26,R27,R28,R32,R33,R34,R35,R37,R38,R40 | Capacitor_SMD:C_0402_1005Metric
30k | R2 | Capacitor_SMD:C_0402_1005Metric
20k | R1,R3,R8,R10,R14,R20,R36 | Capacitor_SMD:C_0402_1005Metric
2.2uH | L1 | Capacitor_SMD:C_1812_4532Metric
Conn_01x04_MountingPin | J6 | Connector_PinSocket_2.54mm:PinSocket_2x02_P2.54mm_Vertical
Conn_01x23_MountingPin | J4,J5 | Connector_PinHeader_2.54mm:PinHeader_1x23_P2.54mm_Vertical
Conn_02x06_Odd_Even_MountingPin | J3 | Connector_PinSocket_2.54mm:PinSocket_2x06_P2.54mm_Vertical
Button | J1,J2 | Button_Switch_SMD:SW_SPST_PTS810
W25Q16JVUXIQ | FLASH1 | Package_SON:SON-8-1EP_3x2mm_P0.5mm_EP1.4x1.6mm
MPZ0603S121HT000 | FB1,FB2,FB3 | Capacitor_SMD:C_0201_0603Metric
SOD-523 General | D3,D4 | Diode_SMD:D_SOD-523
SML-P11UTT86 | D1,D2 | LED_SMD:LED_0402_1005Metric
4.7uF | C4,C6,C7,C14,C15,C16,C17,C18,C20,C21,C22,C23,C24,C25,C26,C27,C28,C29,C30,C31,C32,C33,C34,C35,C36,C37,C38 | Capacitor_SMD:C_0402_1005Metric
22pF | C2,C3 | Capacitor_SMD:C_0402_1005Metric
22uF | C1,C5,C8,C9,C10,C11,C12 | Capacitor_SMD:C_0402_1005Metric

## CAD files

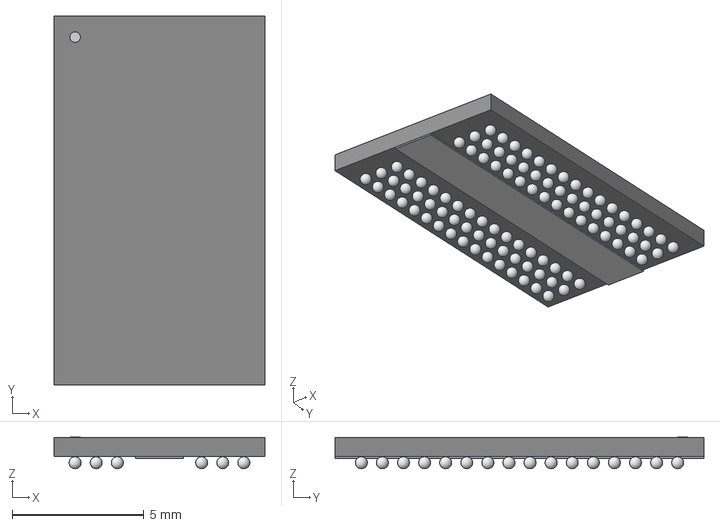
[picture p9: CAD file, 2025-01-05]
DDR3 test/DDR3 test/STEP/FBGA96_8X14_MRN.step
8.00 x 14.0 x 1.20 mm

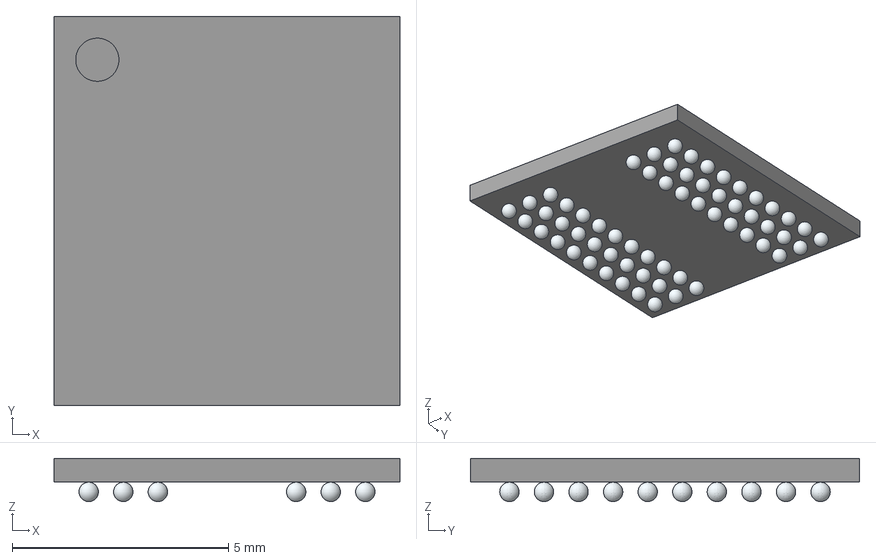
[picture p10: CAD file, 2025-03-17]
DDR3 test/V3 LPDDR/LIB_MT46H128M16LFDD-48_IT_C_TR/MT46H128M16LFDD-48_IT_C_TR/3D/MT46H128M16LFDD-48_IT_C_TR.stp
8.00 x 9.00 x 1.00 mm
A1
A2
A3
A7
A8
A9
B1
B2
B3
B7
B8
B9
C1
C2
C3
C7
C8
C9
D1
D2
D3
D7
D8
D9
E1
E2
E3
E7
E8
E9
F1
F2
F3
F7
F8
F9
G1
G2
G3
G7
G8
G9
H1
H2
H3
H7
H8
H9
J1
J2
J3
J7
J8
J9
K1
K2
K3
K7
K8
K9

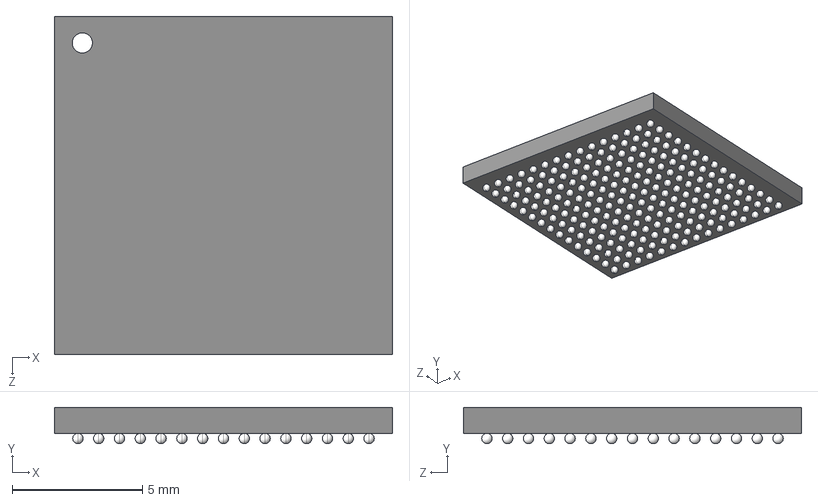
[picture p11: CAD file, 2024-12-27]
DDR3 test/V3 LPDDR/STEP/XC7Z010-1CLG225I.step
13.0 x 1.40 x 13.0 mm

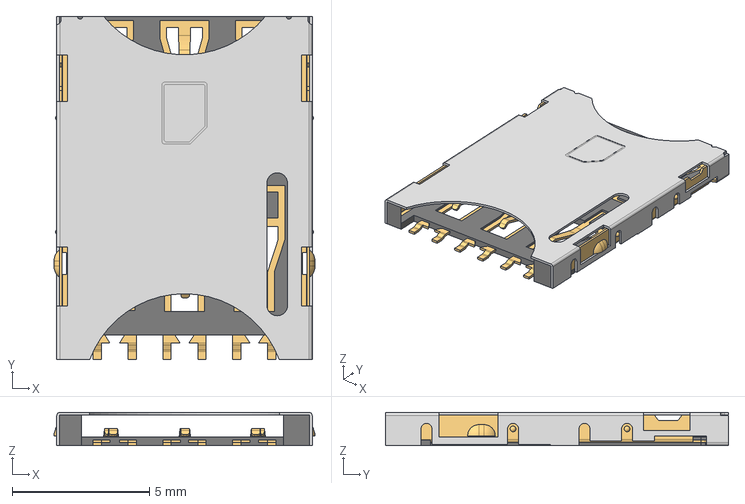
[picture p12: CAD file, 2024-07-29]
Schematic & PCB (pending fixing)/zynqPCB-master/footprints/Download_STP_693043020611_rev1.stp
9.50 x 12.5 x 1.21 mm
693043020611_SHIELDING

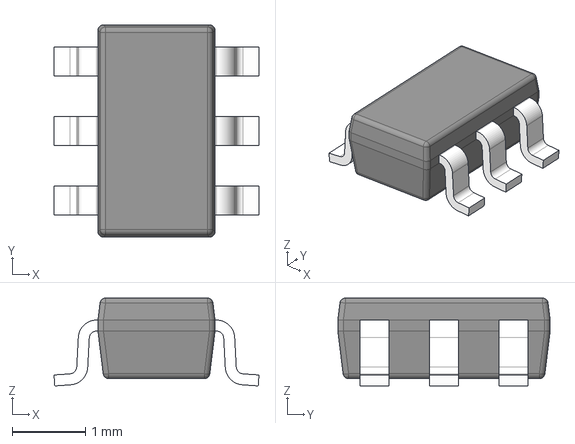
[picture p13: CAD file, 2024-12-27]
DDR3 test/V3 Proto with RF/STEP/DBV0006A.stp
2.80 x 2.90 x 1.20 mm
BODY-SOT
LEAD-SOT x 6

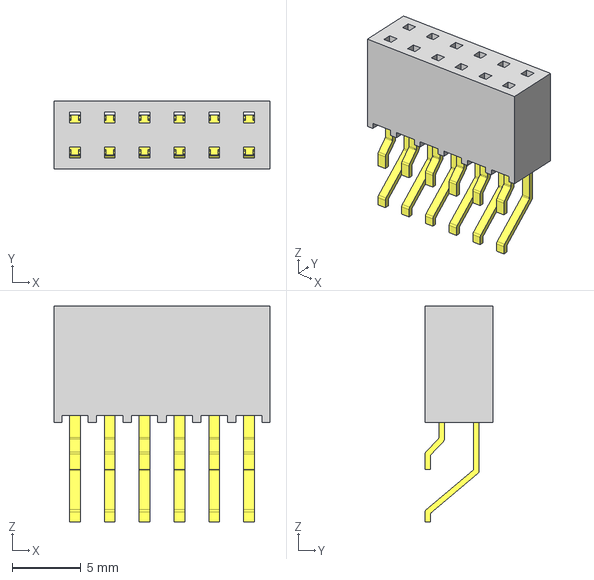
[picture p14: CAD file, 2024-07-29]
Schematic & PCB (pending fixing)/zynqPCB-master/footprints/SAMTEC-SMH-106-02-X-D.step
15.7 x 4.95 x 15.7 mm
SMH-106-D_socket
C-08-03-06-D_SMH

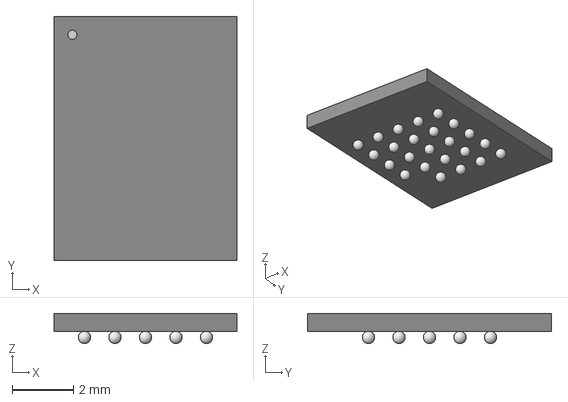
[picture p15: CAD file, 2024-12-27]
DDR3 test/V3 LPDDR/STEP/PG-BGA-24-801.step
5.99 x 8.00 x 0.993 mm

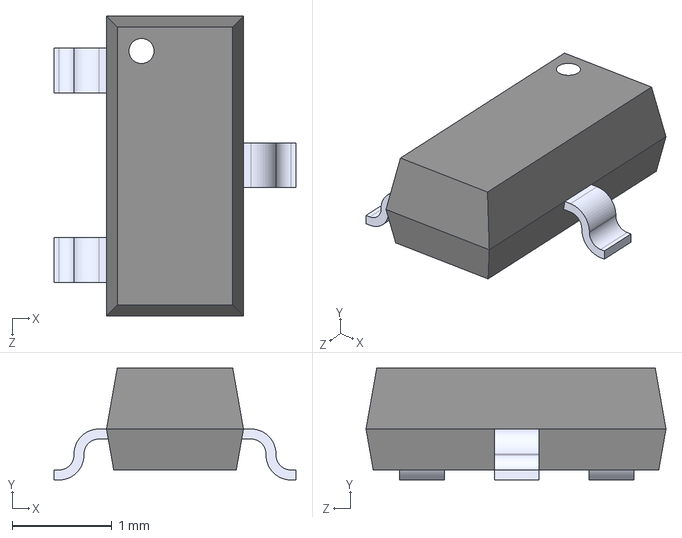
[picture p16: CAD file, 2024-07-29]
Schematic & PCB (pending fixing)/zynqPCB-master/footprints/MMBTA14-7-F.step
2.42 x 1.12 x 3.00 mm

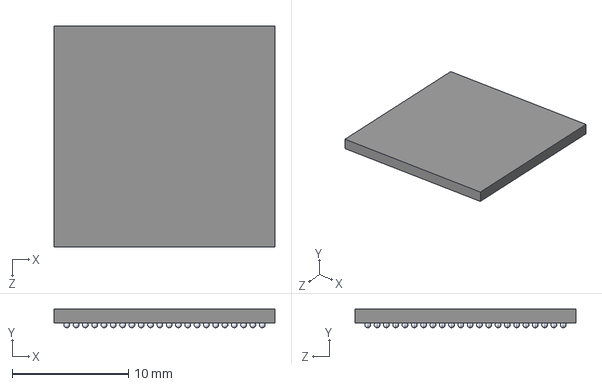
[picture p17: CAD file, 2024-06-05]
Schematic & PCB (pending fixing)/zynqPCB-master/footprints/XC7Z020-1CLG484C.STEP
19.0 x 1.60 x 19.0 mm

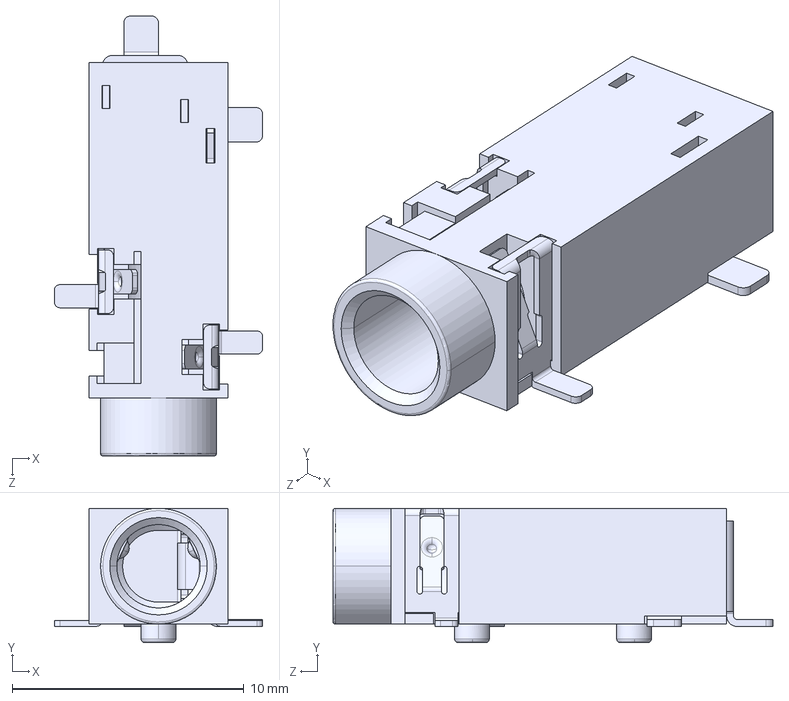
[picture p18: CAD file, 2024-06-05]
Schematic & PCB (pending fixing)/zynqPCB-master/footprints/CUI_DEVICES_SJ-3524-SMT-TR.step
9.00 x 5.80 x 19.0 mm

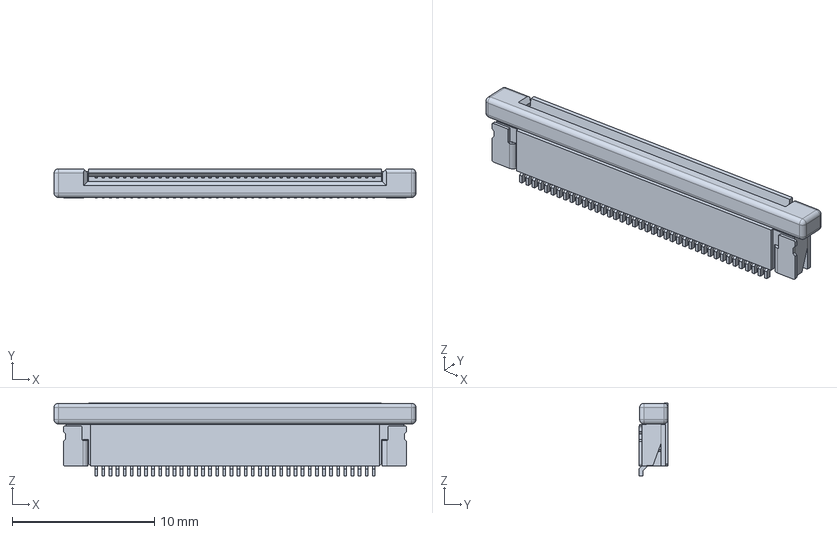
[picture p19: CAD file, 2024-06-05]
Schematic & PCB (pending fixing)/zynqPCB-master/footprints/4-1734839-0.stp
25.4 x 2.05 x 5.11 mm

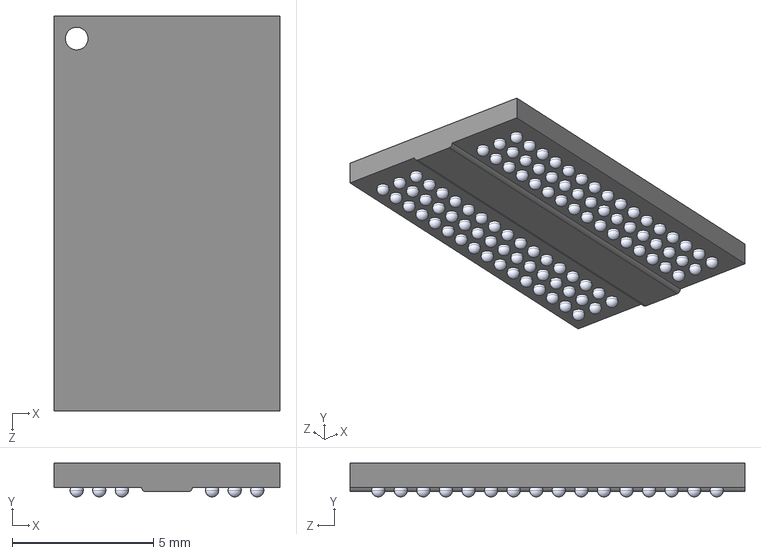
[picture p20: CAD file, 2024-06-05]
Schematic & PCB (pending fixing)/zynqPCB-master/footprints/MT41K256M16TW-107-P--3DModel-STEP-56544.STEP
8.00 x 1.20 x 14.0 mm

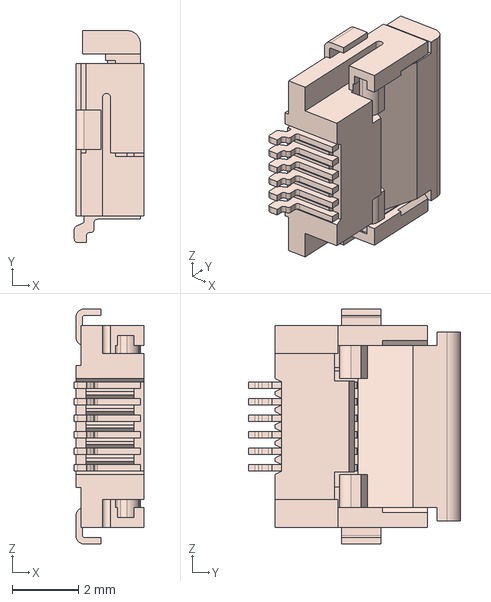
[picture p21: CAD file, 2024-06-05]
Schematic & PCB (pending fixing)/zynqPCB-master/footprints/FH12-6S-0.5SH--3DModel-STEP-1.STEP
2.10 x 6.40 x 7.10 mm

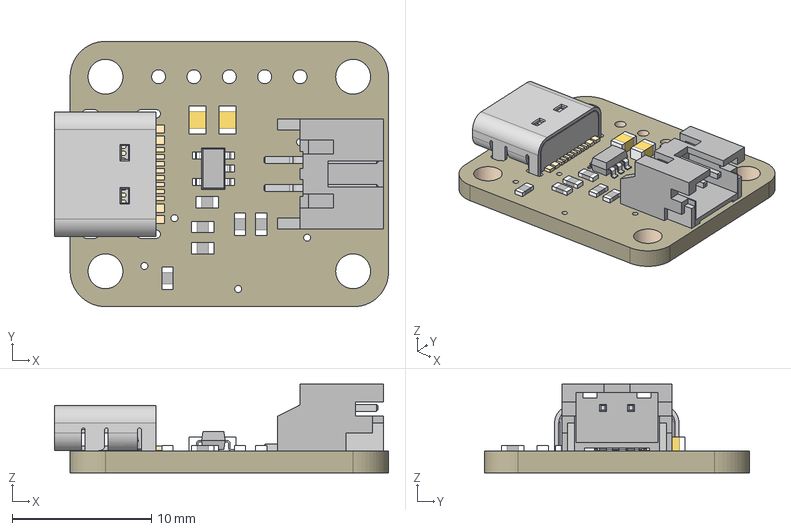
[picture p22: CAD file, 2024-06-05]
Schematic & PCB (pending fixing)/zynqPCB-master/footprints/4410 Micro Lipo USBC.step
24.0 x 19.1 x 6.37 mm
Board
MCP73831T-2ACI/OT
5.1K x 6
JSTPH
10µF x 2
USB_C_CUSB31-CFM2AX-01-X

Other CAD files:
Schematic & PCB (pending fixing)/zynqPCB-master/footprints/ESP32-C3 supermini v5.step
Archived concepts/Prototype Breadboard/STEP/473092651.stp
Archived concepts/Schematic & PCB (version 2) (outdated)/zynqPCB-master/footprints/10029449-111RLF.step
Archived concepts/Schematic & PCB (version 2) (outdated)/zynqPCB-master/footprints/1140084168.step
Archived concepts/Schematic & PCB (version 2) (outdated)/zynqPCB-master/footprints/87583-2010RLF.step
Archived concepts/Schematic & PCB (version 2) (outdated)/zynqPCB-master/footprints/ESP32-C3 supermini v5.step
Archived concepts/Schematic & PCB (version 2) (outdated)/zynqPCB-master/footprints/SIM7100-6-1-15-00-A_REVC.step
DDR3 test/V3 LPDDR/LIB_MT46H128M16LFDD-48_IT_C_TR/MT46H128M16LFDD-48_IT_C_TR/Allegro/bga60c80p9x10_800x900x100.psm
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

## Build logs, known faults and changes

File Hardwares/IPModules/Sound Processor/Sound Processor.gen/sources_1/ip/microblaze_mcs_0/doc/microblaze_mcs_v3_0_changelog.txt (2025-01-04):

2023.2:
 * Version 3.0 (Rev. 22)
 * General: Rebrand to AMD copyright information
 * General: Change default memory size to 16KB
 * Revision change in one or more subcores

2023.1.2:
 * Version 3.0 (Rev. 21)
 * No changes

2023.1.1:
 * Version 3.0 (Rev. 21)
 * No changes

2023.1:
 * Version 3.0 (Rev. 21)
 * Revision change in one or more subcores

2022.2.2:
 * Version 3.0 (Rev. 20)
 * No changes

2022.2.1:
 * Version 3.0 (Rev. 20)
 * No changes

2022.2:
 * Version 3.0 (Rev. 20)
 * Revision change in one or more subcores

2022.1.2:
 * Version 3.0 (Rev. 19)
 * No changes

2022.1.1:
 * Version 3.0 (Rev. 19)
 * No changes

2022.1:
 * Version 3.0 (Rev. 19)
 * Revision change in one or more subcores

2021.2.2:
 * Version 3.0 (Rev. 18)
 * No changes

2021.2.1:
 * Version 3.0 (Rev. 18)
 * No changes

2021.2:
 * Version 3.0 (Rev. 18)
 * Revision change in one or more subcores

2021.1.1:
 * Version 3.0 (Rev. 17)
 * Revision change in one or more subcores

2021.1:
 * Version 3.0 (Rev. 16)
 * Feature Enhancement: Added optimization that excludes hardware multiplier
 * Other: Improve upgrade to ensure that interfaces are not disabled
 * Revision change in one or more subcores

2020.3:
 * Version 3.0 (Rev. 15)
 * Revision change in one or more subcores

2020.2.2:
 * Version 3.0 (Rev. 14)
 * No changes

2020.2.1:
 * Version 3.0 (Rev. 14)
 * No changes

2020.2:
 * Version 3.0 (Rev. 14)
 * Feature Enhancement: Support automatic connection of external BSCAN in Versal
 * Other: Added support for UltraRAM in Versal ACAP
 * Revision change in one or more subcores

2020.1.1:
 * Version 3.0 (Rev. 13)
 * No changes

2020.1:
 * Version 3.0 (Rev. 13)
 * General: Avoid subcore dependency warning for Versal ACAP
 * Revision change in one or more subcores

2019.2.2:
 * Version 3.0 (Rev. 12)
 * No changes

2019.2.1:
 * Version 3.0 (Rev. 12)
 * No changes

2019.2:
 * Version 3.0 (Rev. 12)
 * Feature Enhancement: Added support for external BSCAN
 * Feature Enhancement: Added support for AXI parallel debug
 * Revision change in one or more subcores

2019.1.3:
 * Version 3.0 (Rev. 11)
 * No changes

2019.1.2:
 * Version 3.0 (Rev. 11)
 * No changes

2019.1.1:
 * Version 3.0 (Rev. 11)
 * No changes

2019.1:
 * Version 3.0 (Rev. 11)
 * General: Supported devices and production status are now determined automatically, to simplify support for future devices
 * Revision change in one or more subcores

2018.3.1:
 * Version 3.0 (Rev. 10)
 * No changes

2018.3:
 * Version 3.0 (Rev. 10)
 * General: Updated with latest subcores
 * Revision change in one or more subcores

2018.2:
 * Version 3.0 (Rev. 9)
 * General: Added support for Virtex UltraScale+ 58g devices
 * Revision change in one or more subcores

2018.1:
 * Version 3.0 (Rev. 8)
 * Revision change in one or more subcores

2017.4:
 * Version 3.0 (Rev. 7)
 * Bug Fix: Propagate clock, reset and external interrupt properties from ports in IP Integrator block designs, and remove corresponding settings from the IP configuration dialog
 * Other: Added support for XA Zynq UltraScale+ and XA Spartan-7 devices
 * Revision change in one or more subcores

2017.3:
 * Version 3.0 (Rev. 6)
 * Feature Enhancement: Added support for XPM memory
 * Revision change in one or more subcores

2017.2:
 * Version 3.0 (Rev. 5)
 * Revision change in one or more subcores

2017.1:
 * Version 3.0 (Rev. 4)
 * General: Updated with latest subcore versions
 * General: Added logotype
 * Revision change in one or more subcores

2016.4:
 * Version 3.0 (Rev. 3)
 * Revision change in one or more subcores

2016.3:
 * Version 3.0 (Rev. 2)
 * General: Updated with latest subcores
 * General: Added support for Spartan 7 devices
 * Revision change in one or more subcores

2016.2:
 * Version 3.0 (Rev. 1)
 * Revision change in one or more subcores

2016.1:
 * Version 3.0
 * Repackaged as a hierarchical IP, no functional changes
 * Export hardware to SDK using Vivado instead of IP specific export. Due to this change software may need to be updated to modify IP parameter names.
 * Added option to enable Error Correction Codes (ECC) on the internal Block RAM
 * Added option to set MicroBlaze optimization (area or performance)
 * Support for Virtex UltraScale devices at Production status
 * Added parameter enablement expressions for user parameters
 * Revision change in one or more subcores

2015.4.2:
 * Version 2.3 (Rev. 3)
 * No changes

2015.4.1:
 * Version 2.3 (Rev. 3)
 * No changes

2015.4:
 * Version 2.3 (Rev. 3)
 * Updated documentation links
 * Revision change in one or more subcores

2015.3:
 * Version 2.3 (Rev. 2)
 * Updated family names for additional Ultrascale devices
 * Updated with latest subcore versions
 * IP revision number added to HDL module, library, and include file names, to support designs with both locked and upgraded IP instances
 * Revision change in one or more subcores

2015.2.1:
 * Version 2.3 (Rev. 1)
 * No changes

2015.2:
 * Version 2.3 (Rev. 1)
 * Added constraints for BSCAN output signals

2015.1:
 * Version 2.3
 * Added support for additional Ultrascale devices
 * Updated with latest subcore versions
 * Updated IP to get Bus Width from common utilities for Board
 * Enabled out-of-context clock frequency setting by adding FREQ_HZ parameter to clock interface

2014.4.1:
 * Version 2.2 (Rev. 3)
 * No changes

2014.4:
 * Version 2.2 (Rev. 3)
 * Updated generated BMM files for dual memory ranges

2014.3:
 * Version 2.2 (Rev. 2)
 * Repackaged parameters for internal automation, no functional changes
 * Updated hardware description template to avoid locale issues, no functional changes
 * Updating core to use utils.tcl needed for board flow from common location
 * Added support for clock and reset board level constraints

2014.2:
 * Version 2.2 (Rev. 1)
 * Removed revision control tags from source code comments, no functional changes

2014.1:
 * Version 2.2
 * Increased available memory sizes
 * Added option to use MicroBlaze Debug Module (MDM) UART for serial I/O via JTAG
 * Updated with latest subcore versions
 * Added XDC constraints for internal debug clocks
 * Internal device family name change, no functional changes

2013.4:
 * Version 2.1
 * Updated with latest subcore versions

2013.3:
 * Version 2.0 (Rev. 2)
 * Added support for board level constraints
 * Support for Automotive Artix-7, Automotive Zynq, Defense Grade Artix-7, and Defense Grade Zynq devices at Production status

2013.2:
 * Version 2.0 (Rev. 1)
 * Repackaged to improve internal automation, no functional changes

2013.1:
 * Version 2.0
 * Vivado-only core, with no functional changes from ISE version 1.4
 * Updated with latest subcore versions
 * GPI Interrupt can be triggered on either both edges, rising edge or falling edge

2012.4:
 * Version 1.3
 * Updated with latest subcore versions
 * Enable debugging of up to four MicroBlaze MCS instances, by adding a parameter to select JTAG user-register

2012.3:
 * Version 1.2
 * No changes

2012.2:
 * Version 1.2
 * Native Vivado release
 * Support for sleep mode introduced in MicroBlaze v8.40.a
 * Support for GPI interrupt introduced in IO Module v1.01.a
 * Support for programmable UART baud rate introduced in IO Module v1.01.a

(c) Copyright 2014 - 2023 Advanced Micro Devices, Inc. All rights reserved.

This file contains confidential and proprietary information
of AMD and is protected under U.S. and international copyright
and other intellectual property laws.

DISCLAIMER
This disclaimer is not a license and does not grant any
rights to the materials distributed herewith. Except as
otherwise provided in a valid license issued to you by
AMD, and to the maximum extent permitted by applicable
law: (1) THESE MATERIALS ARE MADE AVAILABLE "AS IS" AND
WITH ALL FAULTS, AND AMD HEREBY DISCLAIMS ALL WARRANTIES
AND CONDITIONS, EXPRESS, IMPLIED, OR STATUTORY, INCLUDING
BUT NOT LIMITED TO WARRANTIES OF MERCHANTABILITY, NON-
INFRINGEMENT, OR FITNESS FOR ANY PARTICULAR PURPOSE; and
(2) AMD shall not be liable (whether in contract or tort,
including negligence, or under any other theory of
liability) for any loss or damage of any kind or nature
related to, arising under or in connection with these
materials, including for any direct, or any indirect,
special, incidental, or consequential loss or damage
(including loss of data, profits, goodwill, or any type of
loss or damage suffered as a result of any action brought
by a third party) even if such damage or loss was
reasonably foreseeable or AMD had been advised of the
possibility of the same.

CRITICAL APPLICATIONS
AMD products are not designed or intended to be fail-
safe, or for use in any application requiring fail-safe
performance, such as life-support or safety devices or
systems, Class III medical devices, nuclear facilities,
applications related to the deployment of airbags, or any
other applications that could lead to death, personal
injury, or severe property or environmental damage
(individually and collectively, "Critical
Applications"). Customer assumes the sole risk and
liability of any use of AMD products in Critical
Applications, subject only to applicable laws and
regulations governing limitations on product liability.

THIS COPYRIGHT NOTICE AND DISCLAIMER MUST BE RETAINED AS
PART OF THIS FILE AT ALL TIMES.

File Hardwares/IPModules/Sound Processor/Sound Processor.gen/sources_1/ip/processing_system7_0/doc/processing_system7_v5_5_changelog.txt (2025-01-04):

2023.2:
 * Version 5.5 (Rev. 6)
 * No changes

2023.1.2:
 * Version 5.5 (Rev. 6)
 * No changes

2023.1.1:
 * Version 5.5 (Rev. 6)
 * No changes

2023.1:
 * Version 5.5 (Rev. 6)
 * No changes

2022.2.2:
 * Version 5.5 (Rev. 6)
 * No changes

2022.2.1:
 * Version 5.5 (Rev. 6)
 * No changes

2022.2:
 * Version 5.5 (Rev. 6)
 * No changes

2022.1.2:
 * Version 5.5 (Rev. 6)
 * No changes

2022.1.1:
 * Version 5.5 (Rev. 6)
 * No changes

2022.1:
 * Version 5.5 (Rev. 6)
 * No changes

2021.2.2:
 * Version 5.5 (Rev. 6)
 * No changes

2021.2.1:
 * Version 5.5 (Rev. 6)
 * No changes

2021.2:
 * Version 5.5 (Rev. 6)
 * No changes

2021.1.1:
 * Version 5.5 (Rev. 6)
 * No changes

2021.1:
 * Version 5.5 (Rev. 6)
 * No changes

2020.3:
 * Version 5.5 (Rev. 6)
 * No changes

2020.2.2:
 * Version 5.5 (Rev. 6)
 * No changes

2020.2.1:
 * Version 5.5 (Rev. 6)
 * No changes

2020.2:
 * Version 5.5 (Rev. 6)
 * No changes

2020.1.1:
 * Version 5.5 (Rev. 6)
 * No changes

2020.1:
 * Version 5.5 (Rev. 6)
 * No changes

2019.2.2:
 * Version 5.5 (Rev. 6)
 * No changes

2019.2.1:
 * Version 5.5 (Rev. 6)
 * No changes

2019.2:
 * Version 5.5 (Rev. 6)
 * No changes

2019.1.3:
 * Version 5.5 (Rev. 6)
 * No changes

2019.1.2:
 * Version 5.5 (Rev. 6)
 * No changes

2019.1.1:
 * Version 5.5 (Rev. 6)
 * No changes

2019.1:
 * Version 5.5 (Rev. 6)
 * No changes

2018.3.1:
 * Version 5.5 (Rev. 6)
 * No changes

2018.3:
 * Version 5.5 (Rev. 6)
 * No changes

2018.2:
 * Version 5.5 (Rev. 6)
 * No changes

2018.1:
 * Version 5.5 (Rev. 6)
 * No changes

2017.4:
 * Version 5.5 (Rev. 6)
 * No changes

2017.3:
 * Version 5.5 (Rev. 6)
 * DDR Pin Info support for following devices fixed.
 * xc7z007sclg400,xc7z014sclg400,xc7z014sclg484,xc7z012sclg485

2017.2:
 * Version 5.5 (Rev. 5)
 * No changes

2017.1:
 * Version 5.5 (Rev. 5)
 * Zynq BFM is replaced by Zynq VIP

2016.4:
 * Version 5.5 (Rev. 4)
 * No changes

2016.3:
 * Version 5.5 (Rev. 4)
 * Added support for Zynq-7000 single core devices
 * Fixed XDC file generation for CLG225 devices.
 * Added TCL parameters to force AxCACHE[1] = 1 for M_GPx AXI PL interfaces. Parameter names are "PCW_GP0_EN_MODIFIABLE_TXN" and "PCW_GP1_EN_MODIFIABLE_TXN".
 * Performance improvement for DDR initialization when ECC is enabled.

2016.2:
 * Version 5.5 (Rev. 3)
 * No changes

2016.1:
 * Version 5.5 (Rev. 3)
 * No changes

2015.4.2:
 * Version 5.5 (Rev. 3)
 * No changes

2015.4.1:
 * Version 5.5 (Rev. 3)
 * No changes

2015.4:
 * Version 5.5 (Rev. 3)
 * No changes

2015.3:
 * Version 5.5 (Rev. 3)
 * Added unit (cycles) to Precharge Time column for DDR Controller
 * PS internal connectivity updated with EMIO_GPIO signals
 * PCW output code updates - Added volatile keyword for register access
 * Clock correction for S_AXI_HP3 interface
 * Parameters are added for ps7_ddr_0, ps7_ram_0 and ps7_ddr_ram_1 peripherals
 * memory ranges depending on its interface name
 * Following is the list of parameter which will get populated based on its interface HP/GP or ACP
 * C_HP0_AXI_BASENAME, C_HP0_AXI_HIGHNAME 
 * C_HP1_AXI_BASENAME, C_HP1_AXI_HIGHNAME 
 * C_HP2_AXI_BASENAME, C_HP2_AXI_HIGHNAME 
 * C_HP3_AXI_BASENAME, C_HP3_AXI_HIGHNAME 
 * C_GP0_AXI_BASENAME, C_GP0_AXI_HIGHNAME 
 * C_GP1_AXI_BASENAME, C_GP1_AXI_HIGHNAME 
 * C_ACP_AXI_BASENAME, C_ACP_AXI_HIGHNAME 
 * Updated description for Tie off AxUSER under PS - PL Configuration -> ACP Slave AXI Interface
 * SDIO CD & WP are routed to EMIO when not used.
 * New parameter PCW_PLL_BYPASSMODE_ENABLE introduced to put PLLs in bypass mode
 * New attributes as MASTERBUSINTERFACE  and SLAVEBUSINTERFACE  added to Processing System 
 * internal slave/master memory ranges
 * Fixed SMC timing calculations
 * Fixed reg_ddrc_pre_cke_x1024 calculation while DRAM RST is still asserted
 * Fix for WSTROBE (NIC301) for SDIO in PS7 wrapper

2015.2.1:
 * Version 5.5 (Rev. 2)
 * No changes

2015.2:
 * Version 5.5 (Rev. 2)
 * No changes

2015.1:
 * Version 5.5 (Rev. 2)
 * Secure/Non-Secure Access configuration Enablement added in general settings
 * DDR training board details were updated with revised scale and correct values
 * Writing to register tpiu Curentsize (0xF8803004) register is removed if trace is disabled
 * Enchancements for easier DS_5 integration. These Include Dynamic Trace pipeline width configuration based on user chioce and Adding keep option for Trace Control and Data registers
 * Added support and functionality for secure and Non-secure
 * Removed wire ENET0_GMII_TX_EN_i
 * Wire ENET0_GMII_TX_ER_i; and the signals were tied low
 * Added functionality for Trace_CTL_PIPE
 * If JTAG OBUF is disabled; the PJTAG_TDO is set to 0

2014.4.1:
 * Version 5.5 (Rev. 1)
 * No changes

2014.4:
 * Version 5.5 (Rev. 1)
 * DDR training board details were updated with revised scale
 * Other bug fixes
 * Reserved bit for DRAM_param_reg3(0xF8006020) updated to '0'

2014.3:
 * Version 5.5
 * The custom time stamp unit(PTP) signals will be exposed to the Programmable Logic(PL), even when the Ethernet is routed through the MIO. For more details, please refer Zynq Technical Reference Manual (UG 585) CH No. 16.4 IEEE 1588 Time Stamping. This change enables additional optional functionality for designs with Ethernet on MIO. No changes are required for existing designs
 * Updated Trace data port width dependency to be based on Trace parameters Port width will display based on user selection
 * Updated the JTAG interface from master to slave mode. Based on Zynq Technical Reference Manual, PS boot mode supports 4 master boot mode and 2 Slave JTAG Boot mode. Prior versions of Zynq PS7 IP had PL JTAG in master mode incorrectly. The JTAG port TDO will have a buffer (OBUFT) instantiated as part of the Processing System7 IP. This change only affects designs which use PL JTAG through EMIO interface. For More details, refer chapter no.6 of Zynq Technical Reference Manual (UG 585) - Boot and Configuration
 * Added range validation for SMC cycle parameters
 * Prior versions of PS7 IP had writes to certain reserved bits of DDR IOB Buffer Control (DDRIOB_DDR_CTRL). These have been fixed to 0x0.
 * Save and Apply Configuration options are added to preset
 * Training board details were updated and computed for revised scale
 * ENET separate pins for reset introduced
 * Asserted in Self Refresh for register dram_param_reg3
 * DRAM_ODT_reg(0xF8006048) is updated with reserved bits of '1'
 * DDRIOB_DDR_CTRL(0xF8000B6C) is updated with VRP/VRN enabled
 * Added Configuration for tpiu Curentsize (0xF8803004) register to ps7_init and ps7_post_config
 * DBG_CLK_CTRL(0xF8000164) register updates when Trace is enabled, Clock source as EMIO for TPIU

2014.2:
 * Version 5.4 (Rev. 1)
 * Add the polarity feature for reset (USB, I2C and Ethernet) pins
 * Add the IP type is processor
 * Fixed LPDDR2 hang Issue

2014.1:
 * Version 5.4
 * IRQ_F2P connections to be made directly in the silicon

2013.4:
 * Version 5.3 (Rev. 1)
 * DDRIOB_SLEW registers added in ps7_init
 * Removed toggling of FPGA_RST_CTRL register from post_config
 * Trace enabled for different port size such as  2,4,8,16 and 32 bits

2013.3:
 * Version 5.3
 * Added Microzed board preset In ps7 ip
 * xz0303 SBG package added
 * TCL based preset support  for Zynq
 * Zynq BFM subcore added for simulation support

2013.2:
 * Version 5.2
 * Zynq Power Estimation Support added
 * Extended addresing support for SMC memories, QSPI memory, PS registers and SLCR registers
 * Peripheral I/O pin page made more user interactive

2013.1:
 * Version 5.01
 * Added support for ps7 preset configurations
 * Multiple silicon version support
 * Ps7 gui enhanced to vivado standard

(c) Copyright 2002 - 2023 Xilinx, Inc. All rights reserved.

This file contains confidential and proprietary information
of AMD and is protected under U.S. and international copyright
and other intellectual property laws.

DISCLAIMER
This disclaimer is not a license and does not grant any
rights to the materials distributed herewith. Except as
otherwise provided in a valid license issued to you by
AMD, and to the maximum extent permitted by applicable
law: (1) THESE MATERIALS ARE MADE AVAILABLE "AS IS" AND
WITH ALL FAULTS, AND AMD HEREBY DISCLAIMS ALL WARRANTIES
AND CONDITIONS, EXPRESS, IMPLIED, OR STATUTORY, INCLUDING
BUT NOT LIMITED TO WARRANTIES OF MERCHANTABILITY, NON-
INFRINGEMENT, OR FITNESS FOR ANY PARTICULAR PURPOSE; and
(2) AMD shall not be liable (whether in contract or tort,
including negligence, or under any other theory of
liability) for any loss or damage of any kind or nature
related to, arising under or in connection with these
materials, including for any direct, or any indirect,
special, incidental, or consequential loss or damage
(including loss of data, profits, goodwill, or any type of
loss or damage suffered as a result of any action brought
by a third party) even if such damage or loss was
reasonably foreseeable or AMD had been advised of the
possibility of the same.

CRITICAL APPLICATIONS
AMD products are not designed or intended to be fail-
safe, or for use in any application requiring fail-safe
performance, such as life-support or safety devices or
systems, Class III medical devices, nuclear facilities,
applications related to the deployment of airbags, or any
other applications that could lead to death, personal
injury, or severe property or environmental damage
(individually and collectively, "Critical
Applications"). Customer assumes the sole risk and
liability of any use of AMD products in Critical
Applications, subject only to applicable laws and
regulations governing limitations on product liability.

THIS COPYRIGHT NOTICE AND DISCLAIMER MUST BE RETAINED AS
PART OF THIS FILE AT ALL TIMES.

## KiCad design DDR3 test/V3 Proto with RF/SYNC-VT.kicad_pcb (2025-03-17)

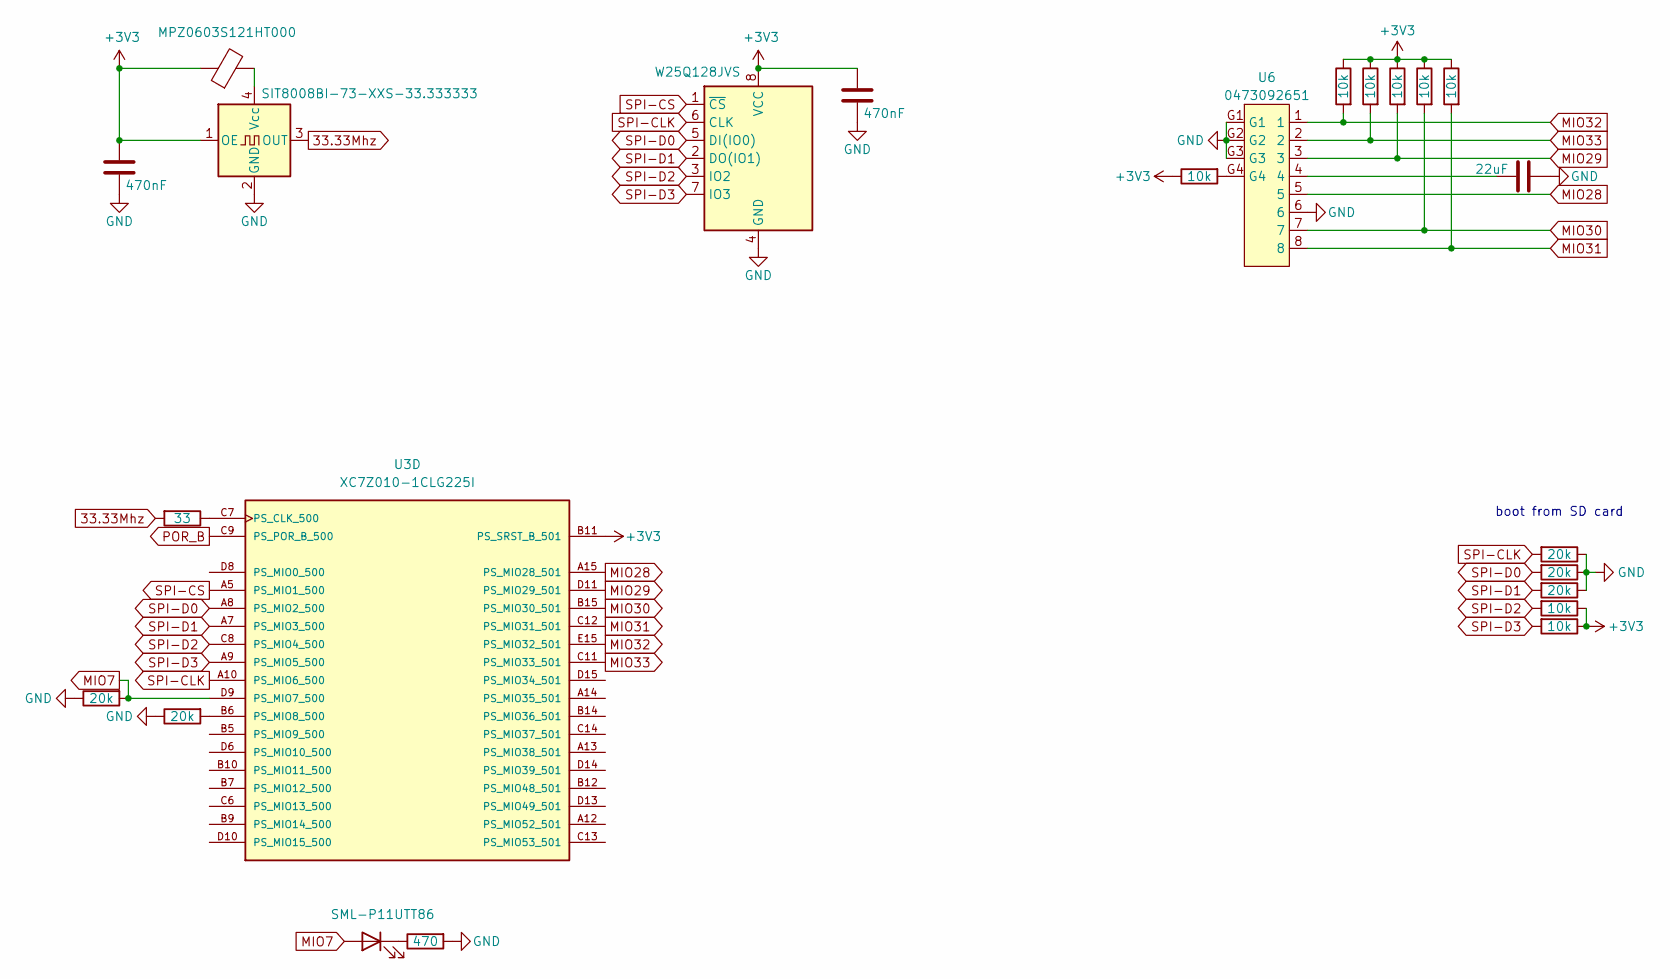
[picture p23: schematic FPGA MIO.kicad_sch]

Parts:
C1: 22uF; C_0402_1005Metric
C26, C27: 470nF; C_0201_0603Metric
D2: SML-P11UTT86; LED_0402_1005Metric
FB3: MPZ0603S121HT000; C_0201_0603Metric
R14, R15, R16, R17, R20: 20k; C_0201_0603Metric
R18, R19, R23, R24, R25, R26, R27, R28: 10k; C_0402_1005Metric
R21: 33; C_0201_0603Metric
R22: 470; C_0201_0603Metric
U3: XC7Z010-1CLG225I; 225-LFBGA; MPN XC7Z010-1CLG225I
U5: W25Q128JVS; SOIC-8_5.23x5.23mm_P1.27mm
U6: 0473092651; CONN12_47309-2651_MOL
X1: SIT8008BI-73-XXS-33.333333; Oscillator_SMD_SeikoEpson_SG210-4Pin_2.5x2.0mm

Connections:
33.33Mhz: R21.2, X1.3 (OUT)
+3V3: C26.1, C27.1, FB3.1, R18.1, R19.1, R23.1, R24.1, R25.1, R26.1, R27.1, R28.1, U3.B11 (PS_SRST_B_501), U5.8 (VCC), X1.1 (OE); also elsewhere on the board
GND: C1.2, C26.2, C27.2, R14.1, R15.1, R16.1, R17.1, R20.1, R22.2, U5.4 (GND), U6.6, U6.G1, U6.G2, U6.G3, X1.2 (GND); also elsewhere on the board
MIO7: D2.2 (A), R20.2, U3.D9 (PS_MIO7_500)
MIO28: U3.A15 (PS_MIO28_501), U6.5
MIO29: R26.2, U3.D11 (PS_MIO29_501), U6.3
MIO30: R27.2, U3.B15 (PS_MIO30_501), U6.7
MIO31: R28.2, U3.C12 (PS_MIO31_501), U6.8
MIO32: R24.2, U3.E15 (PS_MIO32_501), U6.1
MIO33: R25.2, U3.C11 (PS_MIO33_501), U6.2
unnamed: C1.1, U6.4
unnamed: D2.1 (K), R22.1
unnamed: R23.2, U6.G4
unnamed: R21.1, U3.C7 (PS_CLK_500)
unnamed: R14.2, U3.B6 (PS_MIO8_500)
unnamed: FB3.2, X1.4 (Vcc)
POR_B: U3.C9 (PS_POR_B_500); also elsewhere on the board
SPI-CLK: R15.2, U3.A10 (PS_MIO6_500), U5.6 (CLK)
SPI-CS: U3.A5 (PS_MIO1_500), U5.1 (~CS)
SPI-D0: R16.2, U3.A8 (PS_MIO2_500), U5.5 (DI(IO0))
SPI-D1: R17.2, U3.A7 (PS_MIO3_500), U5.2 (DO(IO1))
SPI-D2: R18.2, U3.C8 (PS_MIO4_500), U5.3 (IO2)
SPI-D3: R19.2, U3.A9 (PS_MIO5_500), U5.7 (IO3)

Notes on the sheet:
boot from SD card

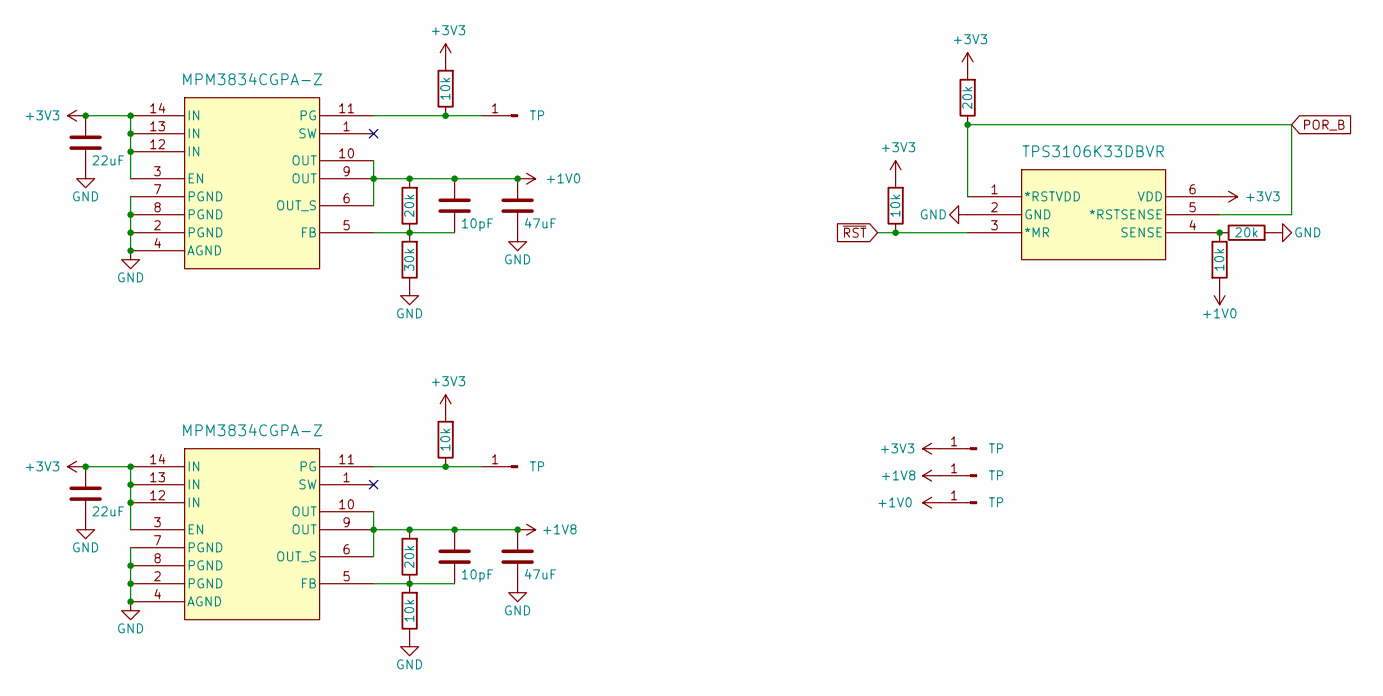
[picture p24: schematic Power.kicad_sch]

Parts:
C5, C11: 10pF; C_0201_0603Metric
C8, C10: 22uF; C_0402_1005Metric
C9, C12: 47uF; C_0805_2012Metric
R1, R3, R8, R10: 20k; C_0201_0603Metric
R2: 30k; C_0402_1005Metric
R4, R5, R6, R7, R9: 10k; C_0402_1005Metric
TP1, TP2, TP3, TP4, TP5: TP; TestPoint_Pad_1.0x1.0mm
U1, U2: MPM3834CGPA-Z; ECLGA-14_MPM3834C_MNP
U4: TPS3106K33DBVR; DBV6-L

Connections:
+1V0: C5.1, C9.1, R1.2, R9.2, TP5.1, U1.6 (OUT_S), U1.9 (OUT), U1.10 (OUT); also elsewhere on the board
+1V8: C11.1, C12.1, R3.2, TP4.1, U2.6 (OUT_S), U2.9 (OUT), U2.10 (OUT); also elsewhere on the board
+3V3: C8.1, C10.1, R4.2, R6.2, R7.2, R10.2, TP3.1, U1.3 (EN), U1.12 (IN), U1.13 (IN), U1.14 (IN), U2.3 (EN), U2.12 (IN), U2.13 (IN), U2.14 (IN), U4.6 (VDD); also elsewhere on the board
GND: C8.2, C9.2, C10.2, C12.2, R2.1, R5.1, R8.2, U1.2 (PGND), U1.4 (AGND), U1.7 (PGND), U1.8 (PGND), U2.2 (PGND), U2.4 (AGND), U2.7 (PGND), U2.8 (PGND), U4.2 (GND); also elsewhere on the board
unnamed: R6.1, TP1.1, U2.11 (PG)
unnamed: R4.1, TP2.1, U1.11 (PG)
unnamed: C5.2, R1.1, R2.2, U1.5 (FB)
unnamed: C11.2, R3.1, R5.2, U2.5 (FB)
unnamed: R8.1, R9.1, U4.4 (SENSE)
POR_B: R10.1, U4.1 (*RSTVDD), U4.5 (*RSTSENSE); also elsewhere on the board
~RST: R7.1, U4.3 (*MR)

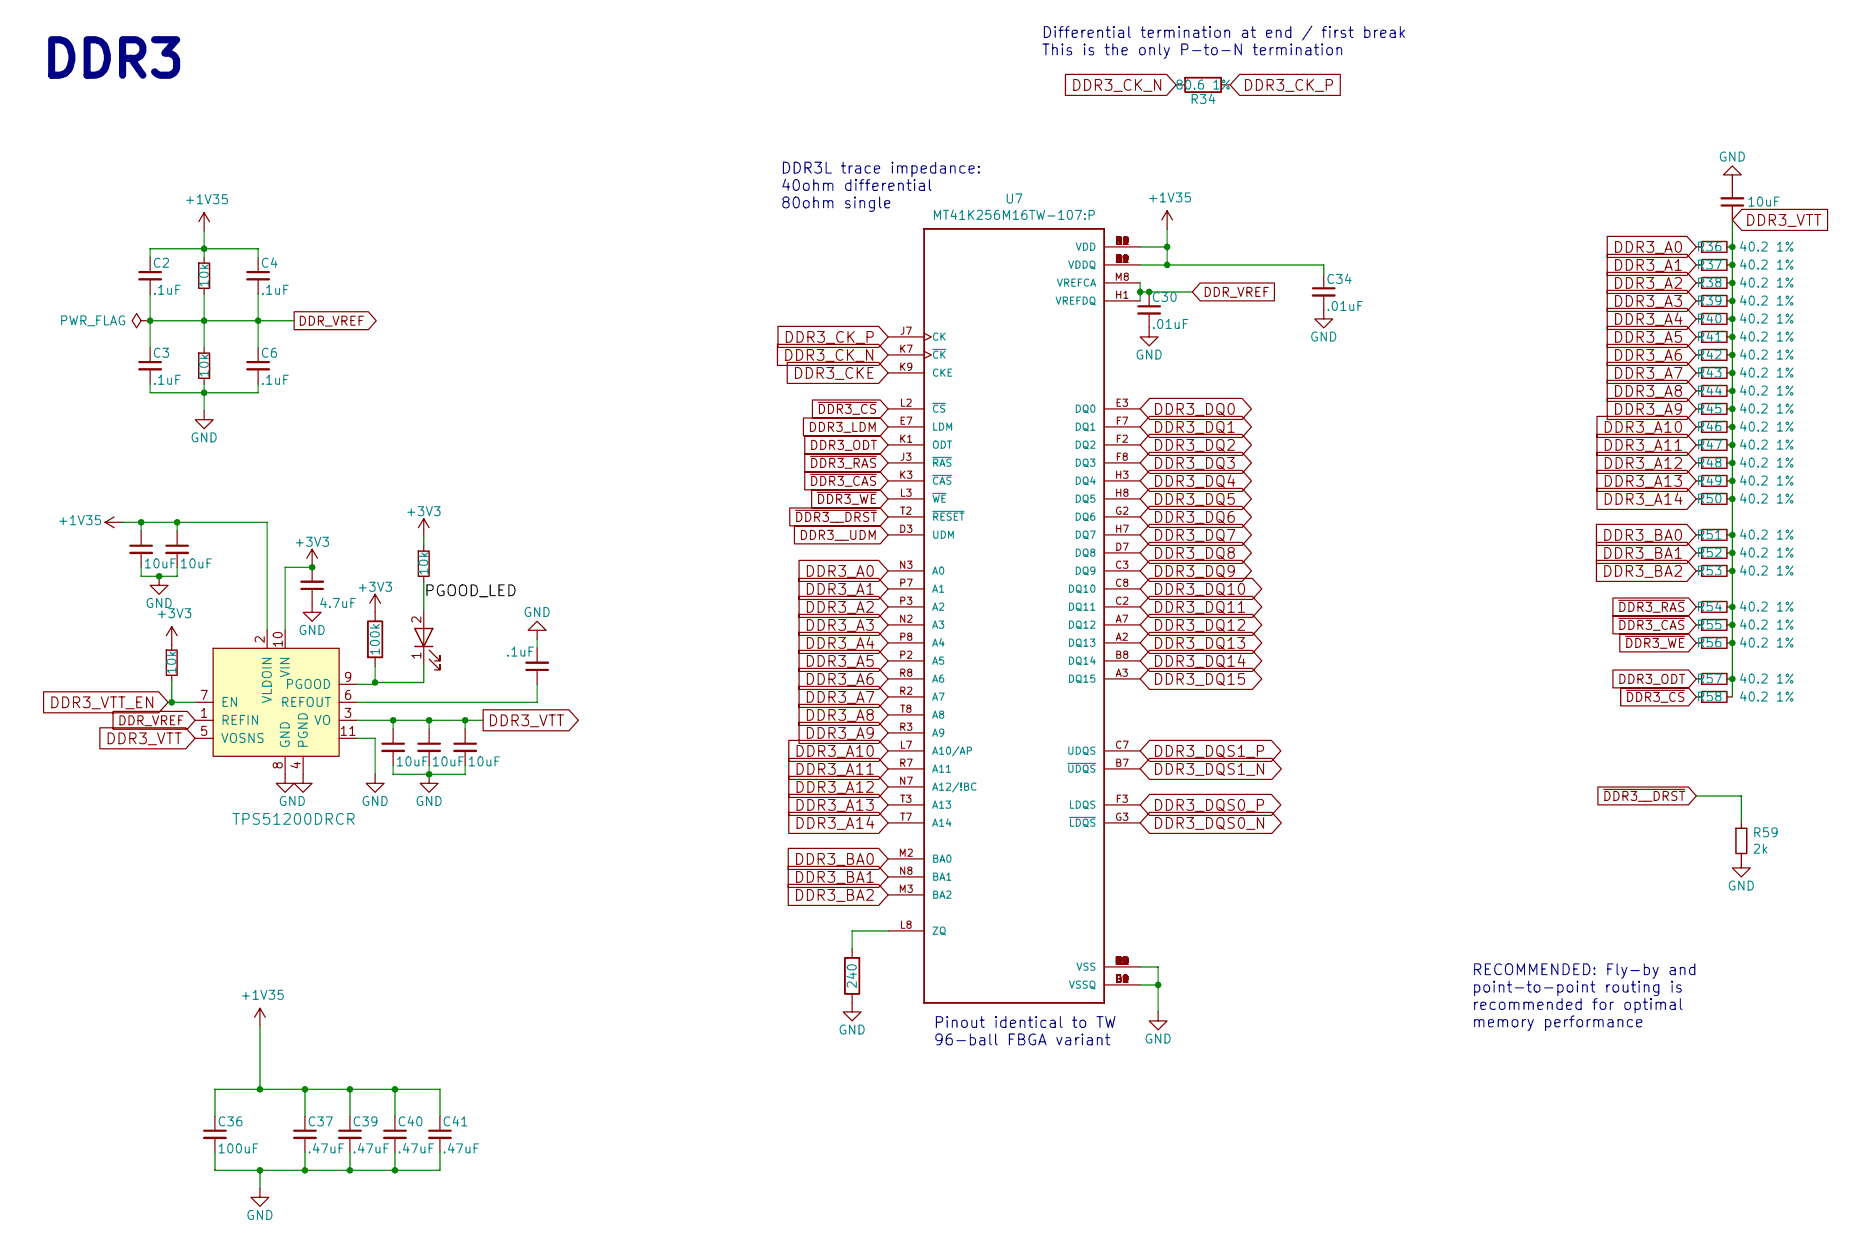
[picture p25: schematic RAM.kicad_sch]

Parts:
C2, C3, C4, C6, C35: .1uF; C_0402_1005Metric; MPN CC0402KRX7R6BB104
C7, C28, C31, C32, C33: 10uF; C_0402_1005Metric; MPN GRM188R61A106KE69J
C29: 4.7uF; C_0201_0603Metric; MPN GRM155R60G475ME47D
C30, C34: .01uF; C_0402_1005Metric; MPN GRM155R71H103KA88J
C36: 100uF; C_1206_3216Metric; MPN JMK325ABJ107MM-P
C37, C39, C40, C41: .47uF; C_1206_3216Metric; MPN CC0402KRX5R5BB474
C38: 10uF; C_0402_1005Metric
D3: BLUE LED; LED_0603_1608Metric; MPN VLMB1300-GS08
R29, R30, R32, R35: 10k; R_0805_2012Metric; MPN RC0402FR-0710KL
R31: 240; R_0603_1608Metric
R33: 100k; R_0402_1005Metric; MPN RC0402FR-07100KL
R34: 80.6 1%; R_0603_1608Metric; MPN RC0402FR-0780R6L
R36, R37, R38, R39, R40, R41, R42, R43, R44, R45, R46, R47, R48, R49, R50, R51, R52, R53, R54, R55, R56, R57, R58: 40.2 1%; R_0201_0603Metric; MPN RC0402FR-0740R2L
R59: 2k; R_0402_1005Metric; MPN RC0402JR-074K7L
U7: MT41K256M16TW-107:P; Micron_FBGA-96_9x14mm_Layout9x16_P0.8mm; MPN MT41K256M16TW-107
U8: TPS51200DRCR; VSON-10-1EP_3x3mm_P0.5mm_EP1.65x2.4mm_ThermalVias; MPN TPS51200DRCR; Digi-Key_PN 296-26978-1-ND

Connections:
+1V35: C2.1, C4.1, C7.1, C28.1, C34.1, C36.1, C37.1, C39.1, C40.1, C41.1, R29.1, U7.A1 (VDDQ), U7.A8 (VDDQ), U7.B2 (VDD), U7.C1 (VDDQ), U7.C9 (VDDQ), U7.D2 (VDDQ), U7.D9 (VDD), U7.E9 (VDDQ), U7.F1 (VDDQ), U7.G7 (VDD), U7.H2 (VDDQ), U7.H9 (VDDQ), U7.K2 (VDD), U7.K8 (VDD), U7.N1 (VDD), U7.N9 (VDD), U7.R1 (VDD), U7.R9 (VDD), U8.2 (VLDOIN)
+3V3: C29.2, R32.1, R33.1, R35.1, U8.10 (VIN); also elsewhere on the board
/RAM/PGOOD_LED: D3.2 (A), R35.2
DDR3_A0: R36.1, U7.N3 (A0); also elsewhere on the board
DDR3_A1: R37.1, U7.P7 (A1); also elsewhere on the board
DDR3_A2: R38.1, U7.P3 (A2); also elsewhere on the board
DDR3_A3: R39.1, U7.N2 (A3); also elsewhere on the board
DDR3_A4: R40.1, U7.P8 (A4); also elsewhere on the board
DDR3_A5: R41.1, U7.P2 (A5); also elsewhere on the board
DDR3_A6: R42.1, U7.R8 (A6); also elsewhere on the board
DDR3_A7: R43.1, U7.R2 (A7); also elsewhere on the board
DDR3_A8: R44.1, U7.T8 (A8); also elsewhere on the board
DDR3_A9: R45.1, U7.R3 (A9); also elsewhere on the board
DDR3_A10: R46.1, U7.L7 (A10/AP); also elsewhere on the board
DDR3_A11: R47.1, U7.R7 (A11); also elsewhere on the board
DDR3_A12: R48.1, U7.N7 (A12/!BC); also elsewhere on the board
DDR3_A13: R49.1, U7.T3 (A13); also elsewhere on the board
DDR3_A14: R50.1, U7.T7 (A14); also elsewhere on the board
DDR3_BA0: R51.1, U7.M2 (BA0); also elsewhere on the board
DDR3_BA1: R52.1, U7.N8 (BA1); also elsewhere on the board
DDR3_BA2: R53.1, U7.M3 (BA2); also elsewhere on the board
DDR3_CKE: U7.K9 (CKE); also elsewhere on the board
DDR3_CK_N: R34.2, U7.K7 (~CK); also elsewhere on the board
DDR3_CK_P: R34.1, U7.J7 (CK); also elsewhere on the board
DDR3_DQ0: U7.E3 (DQ0); also elsewhere on the board
DDR3_DQ1: U7.F7 (DQ1); also elsewhere on the board
DDR3_DQ2: U7.F2 (DQ2); also elsewhere on the board
DDR3_DQ3: U7.F8 (DQ3); also elsewhere on the board
DDR3_DQ4: U7.H3 (DQ4); also elsewhere on the board
DDR3_DQ5: U7.H8 (DQ5); also elsewhere on the board
DDR3_DQ6: U7.G2 (DQ6); also elsewhere on the board
DDR3_DQ7: U7.H7 (DQ7); also elsewhere on the board
DDR3_DQ8: U7.D7 (DQ8); also elsewhere on the board
DDR3_DQ9: U7.C3 (DQ9); also elsewhere on the board
DDR3_DQ10: U7.C8 (DQ10); also elsewhere on the board
DDR3_DQ11: U7.C2 (DQ11); also elsewhere on the board
DDR3_DQ12: U7.A7 (DQ12); also elsewhere on the board
DDR3_DQ13: U7.A2 (DQ13); also elsewhere on the board
DDR3_DQ14: U7.B8 (DQ14); also elsewhere on the board
DDR3_DQ15: U7.A3 (DQ15); also elsewhere on the board
DDR3_DQS0_N: U7.G3 (~LDQS); also elsewhere on the board
DDR3_DQS0_P: U7.F3 (LDQS); also elsewhere on the board
DDR3_DQS1_N: U7.B7 (~UDQS); also elsewhere on the board
DDR3_DQS1_P: U7.C7 (UDQS); also elsewhere on the board
DDR3_LDM: U7.E7 (LDM); also elsewhere on the board
DDR3_ODT: R57.1, U7.K1 (ODT); also elsewhere on the board
DDR3_VTT: C31.1, C32.1, C33.1, C38.1, R36.2, R37.2, R38.2, R39.2, R40.2, R41.2, R42.2, R43.2, R44.2, R45.2, R46.2, R47.2, R48.2, R49.2, R50.2, R51.2, R52.2, R53.2, R54.2, R55.2, R56.2, R57.2, R58.2, U8.3 (VO), U8.5 (VOSNS)
DDR3_VTT_EN: R32.2, U8.7 (EN)
DDR3__UDM: U7.D3 (UDM); also elsewhere on the board
DDR_VREF: C2.2, C3.1, C4.2, C6.1, C30.1, R29.2, R30.1, U7.H1 (VREFDQ), U7.M8 (VREFCA), U8.1 (REFIN)
GND: C3.2, C6.2, C7.2, C28.2, C29.1, C30.2, C31.2, C32.2, C33.2, C34.2, C35.2, C36.2, C37.2, C38.2, C39.2, C40.2, C41.2, R30.2, R31.1, R59.2, U7.A9 (VSS), U7.B1 (VSSQ), U7.B3 (VSS), U7.B9 (VSSQ), U7.D1 (VSSQ), U7.D8 (VSSQ), U7.E1 (VSS), U7.E2 (VSSQ), U7.E8 (VSSQ), U7.F9 (VSSQ), U7.G1 (VSSQ), U7.G8 (VSS), U7.G9 (VSSQ), U7.J2 (VSS), U7.J8 (VSS), U7.M1 (VSS), U7.M9 (VSS), U7.P1 (VSS), U7.P9 (VSS), U7.T1 (VSS), U7.T9 (VSS), U8.4 (PGND), U8.8 (GND), U8.11; also elsewhere on the board
unnamed: D3.1 (K), R33.2, U8.9 (PGOOD)
unnamed: R31.2, U7.L8 (ZQ)
unnamed: C35.1, U8.6 (REFOUT)
~DDR3_CAS: R55.1, U7.K3 (~CAS); also elsewhere on the board
~DDR3_CS: R58.1, U7.L2 (~CS); also elsewhere on the board
~DDR3_RAS: R54.1, U7.J3 (~RAS); also elsewhere on the board
~DDR3_WE: R56.1, U7.L3 (~WE); also elsewhere on the board
~DDR3__DRST: R59.1, U7.T2 (~RESET); also elsewhere on the board

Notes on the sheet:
Pinout identical to TW 96-ball FBGA variant
DDR3
RECOMMENDED: Fly-by and point-to-point routing is recommended for optimal memory performance
DDR3L trace impedance: 40ohm differential 80ohm single
Differential termination at end / first break This is the only P-to-N termination

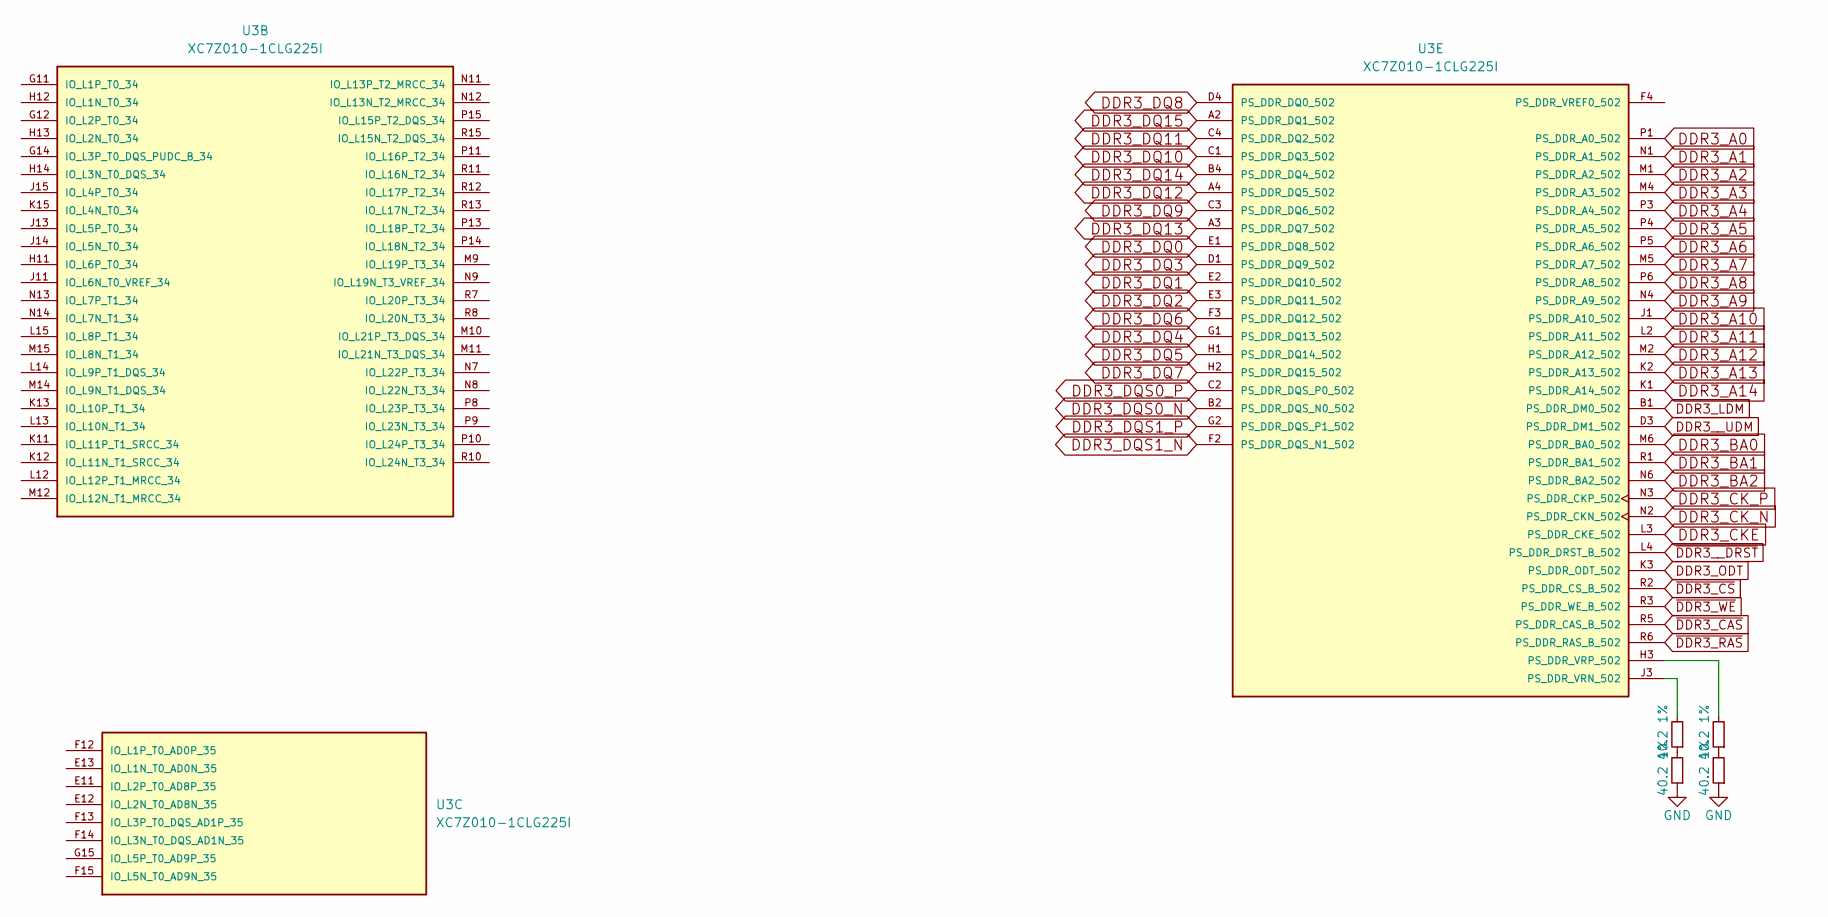
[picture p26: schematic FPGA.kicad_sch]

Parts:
R60, R61, R62, R63: 40.2 1%; R_0201_0603Metric; MPN RC0402FR-0740R2L
U3: XC7Z010-1CLG225I; 225-LFBGA; MPN XC7Z010-1CLG225I

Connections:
DDR3_A0: U3.P1 (PS_DDR_A0_502); also elsewhere on the board
DDR3_A1: U3.N1 (PS_DDR_A1_502); also elsewhere on the board
DDR3_A2: U3.M1 (PS_DDR_A2_502); also elsewhere on the board
DDR3_A3: U3.M4 (PS_DDR_A3_502); also elsewhere on the board
DDR3_A4: U3.P3 (PS_DDR_A4_502); also elsewhere on the board
DDR3_A5: U3.P4 (PS_DDR_A5_502); also elsewhere on the board
DDR3_A6: U3.P5 (PS_DDR_A6_502); also elsewhere on the board
DDR3_A7: U3.M5 (PS_DDR_A7_502); also elsewhere on the board
DDR3_A8: U3.P6 (PS_DDR_A8_502); also elsewhere on the board
DDR3_A9: U3.N4 (PS_DDR_A9_502); also elsewhere on the board
DDR3_A10: U3.J1 (PS_DDR_A10_502); also elsewhere on the board
DDR3_A11: U3.L2 (PS_DDR_A11_502); also elsewhere on the board
DDR3_A12: U3.M2 (PS_DDR_A12_502); also elsewhere on the board
DDR3_A13: U3.K2 (PS_DDR_A13_502); also elsewhere on the board
DDR3_A14: U3.K1 (PS_DDR_A14_502); also elsewhere on the board
DDR3_BA0: U3.M6 (PS_DDR_BA0_502); also elsewhere on the board
DDR3_BA1: U3.R1 (PS_DDR_BA1_502); also elsewhere on the board
DDR3_BA2: U3.N6 (PS_DDR_BA2_502); also elsewhere on the board
DDR3_CKE: U3.L3 (PS_DDR_CKE_502); also elsewhere on the board
DDR3_CK_N: U3.N2 (PS_DDR_CKN_502); also elsewhere on the board
DDR3_CK_P: U3.N3 (PS_DDR_CKP_502); also elsewhere on the board
DDR3_DQ0: U3.E1 (PS_DDR_DQ8_502); also elsewhere on the board
DDR3_DQ1: U3.E2 (PS_DDR_DQ10_502); also elsewhere on the board
DDR3_DQ2: U3.E3 (PS_DDR_DQ11_502); also elsewhere on the board
DDR3_DQ3: U3.D1 (PS_DDR_DQ9_502); also elsewhere on the board
DDR3_DQ4: U3.G1 (PS_DDR_DQ13_502); also elsewhere on the board
DDR3_DQ5: U3.H1 (PS_DDR_DQ14_502); also elsewhere on the board
DDR3_DQ6: U3.F3 (PS_DDR_DQ12_502); also elsewhere on the board
DDR3_DQ7: U3.H2 (PS_DDR_DQ15_502); also elsewhere on the board
DDR3_DQ8: U3.D4 (PS_DDR_DQ0_502); also elsewhere on the board
DDR3_DQ9: U3.C3 (PS_DDR_DQ6_502); also elsewhere on the board
DDR3_DQ10: U3.C1 (PS_DDR_DQ3_502); also elsewhere on the board
DDR3_DQ11: U3.C4 (PS_DDR_DQ2_502); also elsewhere on the board
DDR3_DQ12: U3.A4 (PS_DDR_DQ5_502); also elsewhere on the board
DDR3_DQ13: U3.A3 (PS_DDR_DQ7_502); also elsewhere on the board
DDR3_DQ14: U3.B4 (PS_DDR_DQ4_502); also elsewhere on the board
DDR3_DQ15: U3.A2 (PS_DDR_DQ1_502); also elsewhere on the board
DDR3_DQS0_N: U3.B2 (PS_DDR_DQS_N0_502); also elsewhere on the board
DDR3_DQS0_P: U3.C2 (PS_DDR_DQS_P0_502); also elsewhere on the board
DDR3_DQS1_N: U3.F2 (PS_DDR_DQS_N1_502); also elsewhere on the board
DDR3_DQS1_P: U3.G2 (PS_DDR_DQS_P1_502); also elsewhere on the board
DDR3_LDM: U3.B1 (PS_DDR_DM0_502); also elsewhere on the board
DDR3_ODT: U3.K3 (PS_DDR_ODT_502); also elsewhere on the board
DDR3__UDM: U3.D3 (PS_DDR_DM1_502); also elsewhere on the board
GND: R61.1, R63.1; also elsewhere on the board
unnamed: R60.1, R61.2
unnamed: R62.1, R63.2
unnamed: R60.2, U3.J3 (PS_DDR_VRN_502)
unnamed: R62.2, U3.H3 (PS_DDR_VRP_502)
~DDR3_CAS: U3.R5 (PS_DDR_CAS_B_502); also elsewhere on the board
~DDR3_CS: U3.R2 (PS_DDR_CS_B_502); also elsewhere on the board
~DDR3_RAS: U3.R6 (PS_DDR_RAS_B_502); also elsewhere on the board
~DDR3_WE: U3.R3 (PS_DDR_WE_B_502); also elsewhere on the board
~DDR3__DRST: U3.L4 (PS_DDR_DRST_B_502); also elsewhere on the board

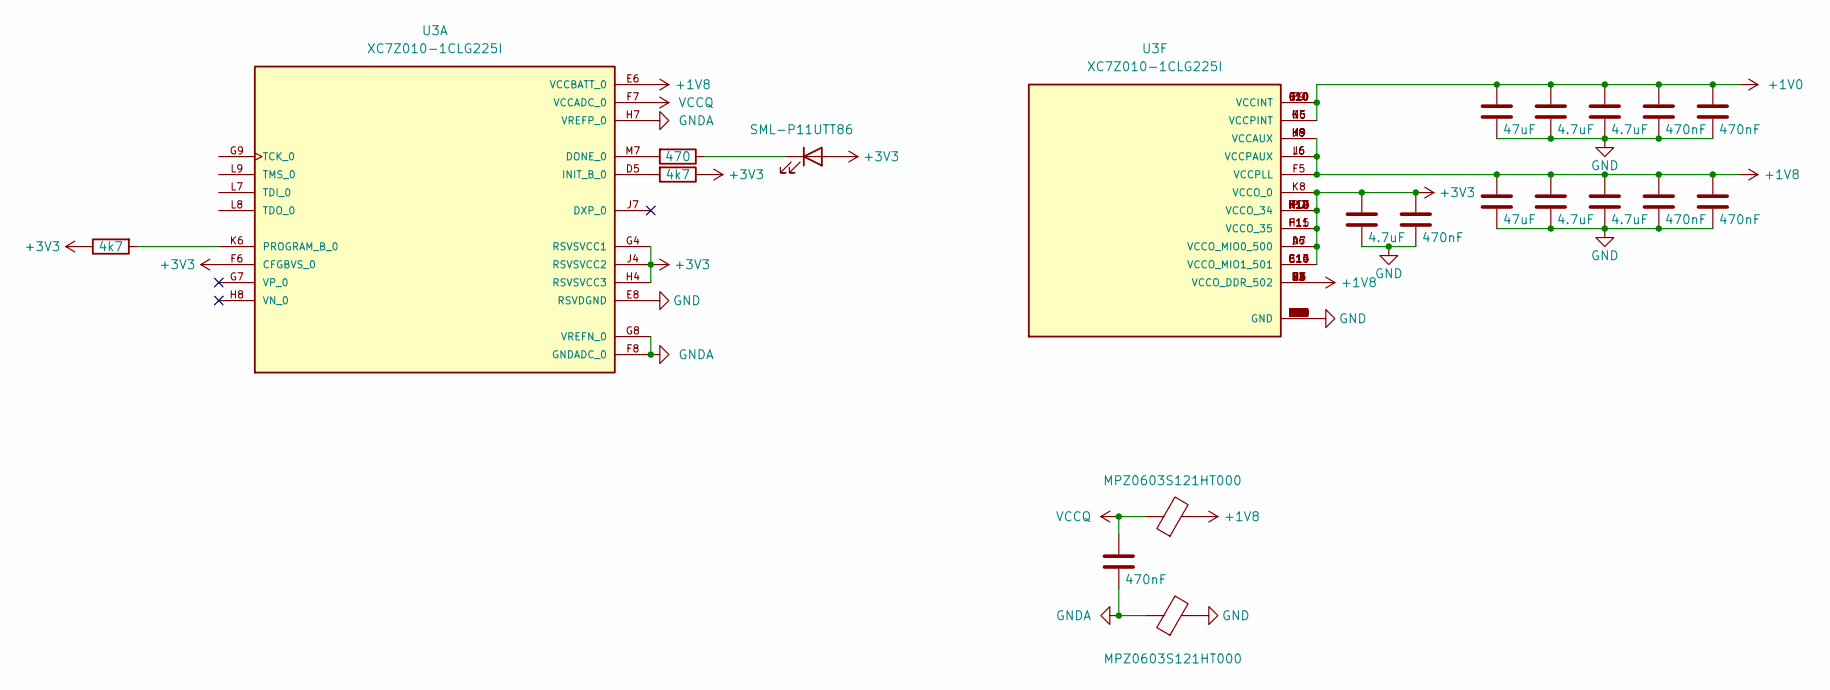
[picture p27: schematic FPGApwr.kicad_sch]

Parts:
C13, C19: 47uF; C_0805_2012Metric
C14, C16, C20, C21, C24: 4.7uF; C_0201_0603Metric
C15, C17, C18, C22, C23, C25: 470nF; C_0201_0603Metric
D1: SML-P11UTT86; LED_0402_1005Metric
FB1, FB2: MPZ0603S121HT000; C_0201_0603Metric
R11, R12: 4k7; C_0201_0603Metric
R13: 470; C_0201_0603Metric
U3: XC7Z010-1CLG225I; 225-LFBGA; MPN XC7Z010-1CLG225I

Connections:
+1V0: C19.1, C20.1, C21.1, C22.1, C23.1, U3.E10 (VCCINT), U3.F9 (VCCINT), U3.G6 (VCCPINT), U3.G10 (VCCINT), U3.H5 (VCCPINT), U3.J10 (VCCINT), U3.K5 (VCCPINT), U3.L10 (VCCINT); also elsewhere on the board
+1V8: C13.1, C14.1, C15.1, C16.1, C17.1, FB1.2, U3.B3 (VCCO_DDR_502), U3.E4 (VCCO_DDR_502), U3.E6 (VCCBATT_0), U3.F1 (VCCO_DDR_502), U3.F5 (VCCPLL), U3.H9 (VCCAUX), U3.J2 (VCCO_DDR_502), U3.J6 (VCCPAUX), U3.J8 (VCCAUX), U3.K9 (VCCAUX), U3.L6 (VCCPAUX), U3.M3 (VCCO_DDR_502), U3.R4 (VCCO_DDR_502); also elsewhere on the board
+3V3: C24.1, C25.1, D1.2 (A), R11.1, R12.1, U3.A6 (VCCO_MIO0_500), U3.B13 (VCCO_MIO1_501), U3.C10 (VCCO_MIO1_501), U3.D7 (VCCO_MIO0_500), U3.E14 (VCCO_MIO1_501), U3.F6 (CFGBVS_0), U3.F11 (VCCO_35), U3.G4 (RSVSVCC1), U3.H4 (RSVSVCC3), U3.H15 (VCCO_35), U3.J4 (RSVSVCC2), U3.J12 (VCCO_34), U3.K8 (VCCO_0), U3.M13 (VCCO_34), U3.N10 (VCCO_34), U3.P7 (VCCO_34), U3.R14 (VCCO_34); also elsewhere on the board
GND: C13.2, C14.2, C15.2, C16.2, C17.2, C19.2, C20.2, C21.2, C22.2, C23.2, C24.2, C25.2, FB2.2, U3.A1 (GND), U3.A11 (GND), U3.B8 (GND), U3.C5 (GND), U3.C15 (GND), U3.D2 (GND), U3.D12 (GND), U3.E5 (GND), U3.E7 (GND), U3.E8 (RSVDGND), U3.E9 (GND), U3.F10 (GND), U3.G3 (GND), U3.G5 (GND), U3.G13 (GND), U3.H6 (GND), U3.H10 (GND), U3.J5 (GND), U3.J9 (GND), U3.K4 (GND), U3.K7 (GND), U3.K10 (GND), U3.K14 (GND), U3.L1 (GND), U3.L5 (GND), U3.L11 (GND), U3.M8 (GND), U3.N5 (GND), U3.N15 (GND), U3.P2 (GND), U3.P12 (GND), U3.R9 (GND); also elsewhere on the board
GNDA: C18.2, FB2.1, U3.F8 (GNDADC_0), U3.G8 (VREFN_0), U3.H7 (VREFP_0)
unnamed: D1.1 (K), R13.1
unnamed: R13.2, U3.M7 (DONE_0)
unnamed: R11.2, U3.D5 (INIT_B_0)
unnamed: R12.2, U3.K6 (PROGRAM_B_0)
VCCQ: C18.1, FB1.1, U3.F7 (VCCADC_0)

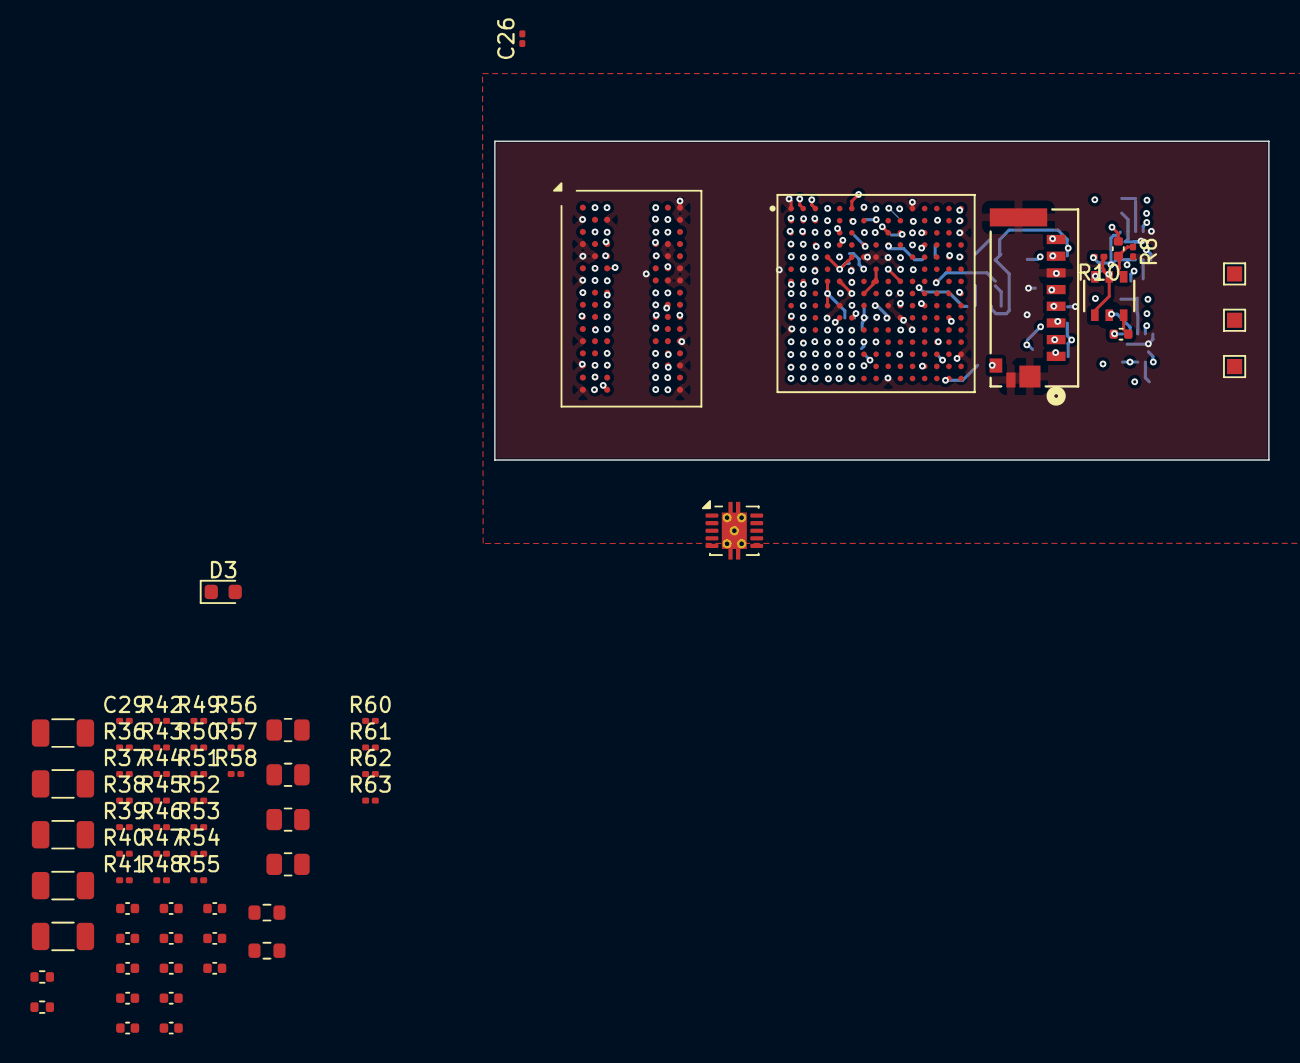
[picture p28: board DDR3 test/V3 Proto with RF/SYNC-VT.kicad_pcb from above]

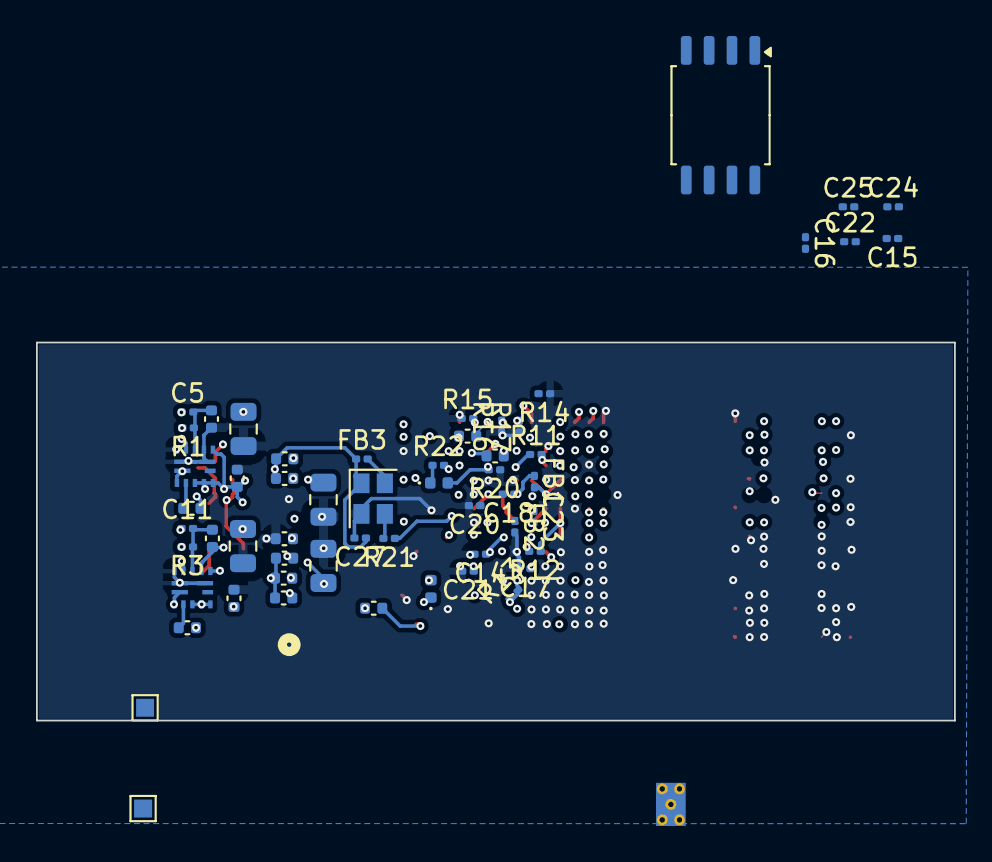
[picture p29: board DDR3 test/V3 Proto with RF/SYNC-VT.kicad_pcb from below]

Board: 6 copper layers, 51.0 x 21.0 mm, 124 parts (56 on the bottom side), 98 nets.

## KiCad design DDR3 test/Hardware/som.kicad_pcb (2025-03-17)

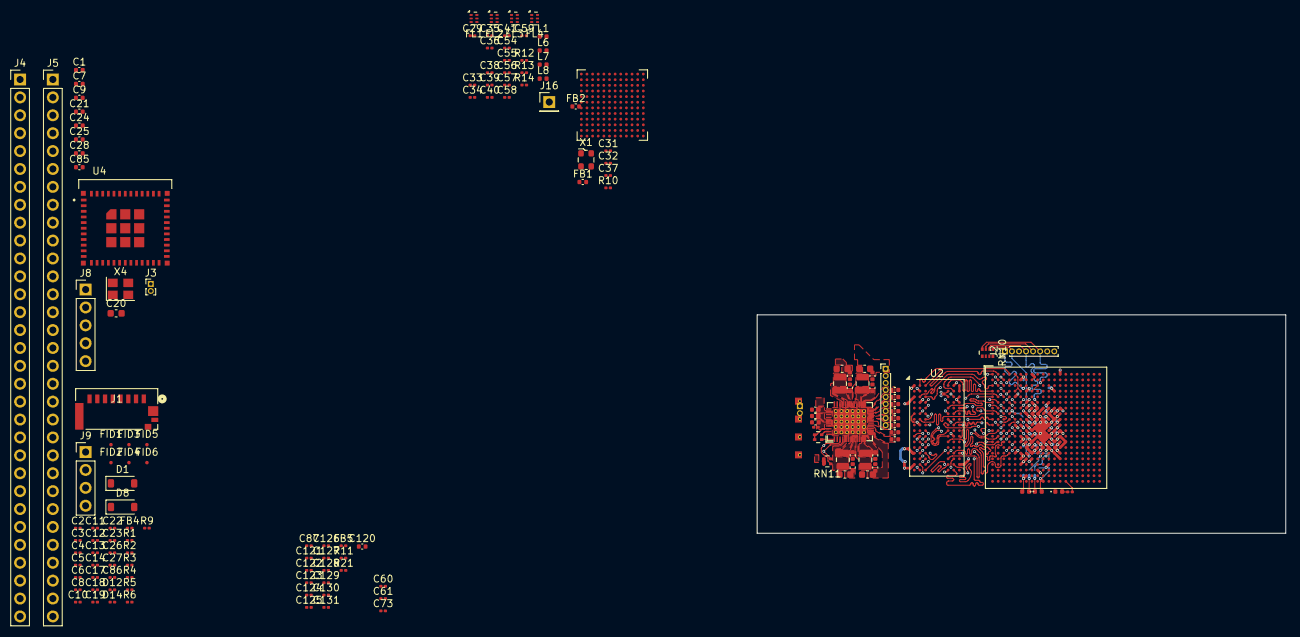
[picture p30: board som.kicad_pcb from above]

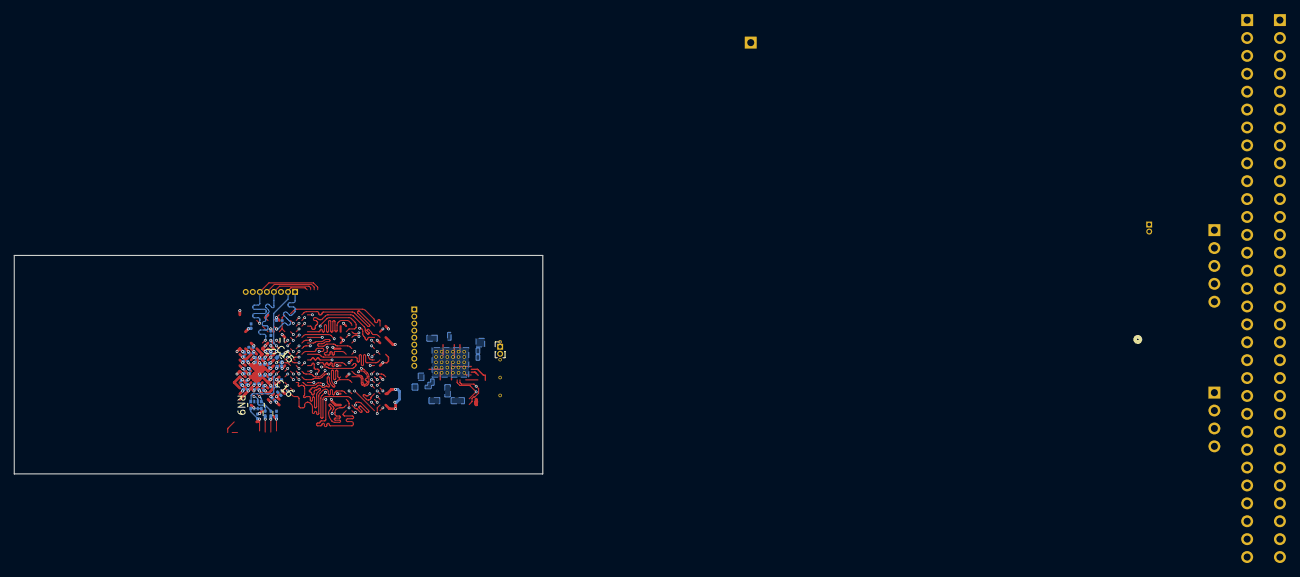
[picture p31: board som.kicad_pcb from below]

Board: 6 copper layers, 75.0 x 31.0 mm, 186 parts (37 on the bottom side), 206 nets.

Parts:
C1, C7, C9, C15, C24, C25, C28: 10uF; C_0402_1005Metric
C2, C3, C4, C5, C6, C8, C10, C11, C12, C13, C14, C16, C17, C18, C19, C23, C26, C27, C29, C31, C32, C33, C34, C35, C36, C38, C39, C40, C41, C54, C55, C57, C58, C59, C60, C61, C73: 0.1uF; C_0201_0603Metric
C20, C97, C100, C105, C107: 22uF; C_0603_1608Metric
C21, C85, C96, C98, C99, C101, C102, C103, C104, C106, C108, C109, C110, C111, C112, C113, C114, C115, C116, C117, C119, C120: 4u7F; C_0402_1005Metric
C22, C42, C43, C44, C45, C46, C47, C48, C49, C50, C51, C52, C62, C63, C64, C65, C66, C67, C68, C69, C70, C72, C86, C87, C88, C89, C90, C91, C92, C93, C118, C121, C122, C123, C124, C125, C126, C127, C128, C129, C130, C131: 100nF; C_0201_0603Metric
C37, C56: 18pF; C_0201_0603Metric
C53, C94: 100nF; C_0201_0603Metric_WideGap
C71: 4u7F; C_0201_0603Metric_WideGap
D1, D8: SUPK24; D_SOD-123
D2: DONE_LED; LED_0402_1005Metric
D3: INIT_LED; LED_0402_1005Metric
D7: LED3; LED_0402_1005Metric
D12, D14: TVS; R_0201_0603Metric
FB1, FB2: FerriteBead_Small; C_0402_1005Metric
FB3, FB4, FB5: 120Ω; L_0201_0603Metric
FID1, FID2, FID3, FID4, FID5, FID6: Fiducial; Fiducial_0.5mm_Mask1mm
FL1, FL2, FL3, FL4: 0850BM14E0016; Balun_Johanson_1.6x0.8mm
J1: TF; CONN12_47309-2651_MOL
J2: Conn_Debug; PinHeader_1x08_P1.00mm_Vertical
J3: Conn_MP; PinHeader_1x02_P1.00mm_Vertical
J4, J5: Conn_PB; PinHeader_1x31_P2.54mm_Vertical
J6: Conn_PWR; PinHeader_1x09_P1.00mm_Vertical
J7: Conn_IIC; PinHeader_1x02_P1.00mm_Vertical
J8: Conn_01x05_Pin; PinHeader_1x05_P2.54mm_Vertical
J9: Conn_01x04_Pin; PinHeader_1x04_P2.54mm_Vertical
J16: Conn_01x01; PinHeader_1x01_P2.54mm_Vertical
L1, L6, L7, L8: L; L_0402_1005Metric
L2, L3, L4, L5: 1uH; L_0806_2016Metric
R1, R4, R5: 80Ω; R_0201_0603Metric
R2: 4.7K; R_0201_0603Metric
R3: 4K7Ω; R_0201_0603Metric
R6: 240Ω; R_0201_0603Metric
R7, R8, R20: R; R_0201_0603Metric
R9, R21: 22Ω; R_0201_0603Metric
R10, R13: 0R; R_0201_0603Metric
R11: 40Ω; R_0201_0603Metric
R12: 14.3K; R_0201_0603Metric
R14: N/A; R_0201_0603Metric
RN9, RN10: 4K7Ω; R_Array_Convex_4x0402
RN11: 4K7Ω; R_Array_Convex_2x0402
RN12: 10KΩ; R_Array_Convex_2x0402
TP1: PMIC_PROG; TP_4pin_2.54mm
U1: XC7Z010CLG400; Xilinx_CLG400_NoPaste_JLC_Package_Delay
U2: DDR3; Micron_FBGA-96_7.5x13.5mm_Layout9x16_P0.8mm
U3: AD9361; bga-100_10_10_1p32_0p8
U4: ESP32-C6-MINI-1U-N4; XCVR_ESP32-C6-MINI-1U-N4
U7: STPMIC1; ST-WFQFN-44L_5x6mm_P0.4mm_ThermalVias
X1: SiT1602B; Oscillator_SMD_ECS_2520MV-xxx-xx-4Pin_2.5x2.0mm
X4: 33.3MHz; Crystal_SMD_3225-4Pin_3.2x2.5mm

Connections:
+1V0: C42.1, C43.1, C44.1, C45.1, C46.1, C47.1, C48.1, C49.1, C50.1, C51.1, C52.1, C53.1, C97.1, C98.1, L2.2, U1.G7 (VCCPINT[6]), U1.G11 (VCCBRAM[2]), U1.G13 (VCCINT[9]), U1.H10 (VCCBRAM[2]), U1.H12 (VCCINT[9]), U1.J7 (VCCPINT[6]), U1.J13 (VCCINT[9]), U1.K12 (VCCINT[9]), U1.L7 (VCCPINT[6]), U1.L13 (VCCINT[9]), U1.M12 (VCCINT[9]), U1.N7 (VCCPINT[6]), U1.N13 (VCCINT[9]), U1.P8 (VCCPINT[6]), U1.P12 (VCCINT[9]), U1.R7 (VCCPINT[6]), U1.R13 (VCCINT[9]), U7.5 (VOUT1)
+1V8: C29.1, C60.1, C61.1, C62.1, C63.1, C64.1, C65.1, C66.1, C67.1, C68.1, C69.1, C70.1, C73.1, C105.1, C106.1, FB3.2, J6.2, L4.2, U1.C19 (VCCO_35[6]), U1.F8 (VCCPAUX[5]), U1.F11 (VCCBATT_0), U1.F18 (VCCO_35[6]), U1.G9 (VCCPAUX[5]), U1.H8 (VCCPAUX[5]), U1.H14 (VCCO_35[6]), U1.J9 (VCCADC_0), U1.J11 (VCCAUX[6]), U1.J17 (VCCO_35[6]), U1.K8 (VCCPAUX[5]), U1.K20 (VCCO_35[6]), U1.L11 (VCCAUX[6]), U1.M8 (VCCPAUX[5]), U1.M16 (VCCO_35[6]), U1.N9 (VCCAUX[6]), U1.N11 (VCCAUX[6]), U1.P10 (VCCAUX[6]), U1.R9 (VCCAUX[6]), U7.31 (VOUT3), X1.4 (VDD)
+3.3VA: C116.1, J4.19, RN11.3 (R2.2), RN11.4 (R1.2), RN12.3 (R2.2), RN12.4 (R1.2), U7.39 (LDO4OUT), U7.42 (VIO)
+3V3: C20.1, C21.1, C22.1, C87.1, C88.1, C89.1, C90.1, C91.1, C92.1, C93.1, C94.1, C107.1, C108.1, C127.1, C128.1, C129.1, C130.1, C131.1, D2.2 (A), D3.2 (A), FB4.2, FB5.2, J1.4 (VDD), J2.8, J3.1, J5.2, J5.20, J6.1, L5.2, R3.1, RN9.1 (R1.1), RN9.2 (R2.1), RN9.3 (R3.1), RN9.4 (R4.1), RN10.5 (R4.2), RN10.6 (R3.2), RN10.7 (R2.2), RN10.8 (R1.2), U1.A6 (PS_MIO5_500), U1.A13 (VCCO_MIO1_501[4]), U1.B6 (VCCO_MIO0_500[2]), U1.B7 (PS_MIO4_500), U1.B16 (VCCO_MIO1_501[4]), U1.D7 (VCCO_MIO0_500[2]), U1.D12 (VCCO_MIO1_501[4]), U1.E15 (VCCO_MIO1_501[4]), U1.K6 (VCCO_0), U1.M6 (CFGBVS_0), U1.N6 (RSVDVCC3), U1.R6 (RSVDVCC2), U1.T6 (RSVDVCC1), U1.T8 (VCCO_13[4]), U1.U11 (VCCO_13[4]), U1.W7 (VCCO_13[4]), U1.Y10 (VCCO_13[4]), U4.3 (3V3), U7.27 (VOUT4)
+5V: C96.1, C99.1, C102.1, C104.1, C109.1, C112.1, C119.1, D1.1 (K), D8.1 (K), D12.1 (A1), D14.1 (A1), J4.9, J4.10, J6.5, J6.8, TP1.3, U7.8 (BUCK1IN), U7.12 (BUCK2IN), U7.19 (LDO25IN), U7.22 (LDO16IN), U7.24 (BUCK4IN), U7.28 (BUCK3IN), U7.36 (VIN)
/BUCK1OUT: L2.1, U7.7 (VLX1)
/BUCK2OUT: L3.1, U7.11 (VLX2)
/BUCK3OUT: L4.1, U7.29 (VLX3)
/BUCK4OUT: L5.1, U7.25 (VLX4)
/DDR_A0: U1.N2 (PS_DDR_A0_502), U2.N3 (A0)
/DDR_A1: U1.K2 (PS_DDR_A1_502), U2.P7 (A1)
/DDR_A2: U1.M3 (PS_DDR_A2_502), U2.P3 (A2)
/DDR_A3: U1.K3 (PS_DDR_A3_502), U2.N2 (A3)
/DDR_A4: U1.M4 (PS_DDR_A4_502), U2.P8 (A4)
/DDR_A5: U1.L1 (PS_DDR_A5_502), U2.P2 (A5)
/DDR_A6: U1.L4 (PS_DDR_A6_502), U2.R8 (A6)
/DDR_A7: U1.K4 (PS_DDR_A7_502), U2.R2 (A7)
/DDR_A8: U1.K1 (PS_DDR_A8_502), U2.T8 (A8)
/DDR_A9: U1.J4 (PS_DDR_A9_502), U2.R3 (A9)
/DDR_A10: U1.F5 (PS_DDR_A10_502), U2.L7 (A10/AP)
/DDR_A11: U1.G4 (PS_DDR_A11_502), U2.R7 (A11)
/DDR_A12: U1.E4 (PS_DDR_A12_502), U2.N7 (A12/~BC)
/DDR_A13: U1.D4 (PS_DDR_A13_502), U2.T3 (A13)
/DDR_A14: U1.F4 (PS_DDR_A14_502), U2.T7 (A14)
/DDR_BA0: U1.L5 (PS_DDR_BA0_502), U2.M2 (BA0)
/DDR_BA1: U1.R4 (PS_DDR_BA1_502), U2.N8 (BA1)
/DDR_BA2: U1.J5 (PS_DDR_BA2_502), U2.M3 (BA2)
/DDR_CKE: U1.N3 (PS_DDR_CKE_502), U2.K9 (CKE)
/DDR_DQ0: U1.E2 (PS_DDR_DQ8_502), U2.E3 (DQ0)
/DDR_DQ1: U1.E3 (PS_DDR_DQ9_502), U2.F7 (DQ1)
/DDR_DQ2: U1.H2 (PS_DDR_DQ13_502), U2.F2 (DQ2)
/DDR_DQ3: U1.G3 (PS_DDR_DQ10_502), U2.F8 (DQ3)
/DDR_DQ4: U1.J1 (PS_DDR_DQ15_502), U2.H3 (DQ4)
/DDR_DQ5: U1.J3 (PS_DDR_DQ12_502), U2.H8 (DQ5)
/DDR_DQ6: U1.H1 (PS_DDR_DQ14_502), U2.G2 (DQ6)
/DDR_DQ7: U1.H3 (PS_DDR_DQ11_502), U2.H7 (DQ7)
/DDR_DQ8: U1.C3 (PS_DDR_DQ0_502), U2.D7 (DQ8)
/DDR_DQ9: U1.B3 (PS_DDR_DQ1_502), U2.C3 (DQ9)
/DDR_DQ10: U1.E1 (PS_DDR_DQ7_502), U2.C8 (DQ10)
/DDR_DQ11: U1.C1 (PS_DDR_DQ6_502), U2.C2 (DQ11)
/DDR_DQ12: U1.D1 (PS_DDR_DQ5_502), U2.A7 (DQ12)
/DDR_DQ13: U1.A4 (PS_DDR_DQ3_502), U2.A2 (DQ13)
/DDR_DQ14: U1.D3 (PS_DDR_DQ4_502), U2.B8 (DQ14)
/DDR_DQ15: U1.A2 (PS_DDR_DQ2_502), U2.A3 (DQ15)
/DDR_DQM0: U1.F1 (PS_DDR_DM1_502), U2.E7 (LDM)
/DDR_DQM1: U1.A1 (PS_DDR_DM0_502), U2.D3 (UDM)
/DDR_DQS0+: U1.G2 (PS_DDR_DQS_P1_502), U2.F3 (LDQS)
/DDR_DQS0-: U1.F2 (PS_DDR_DQS_N1_502), U2.G3 (~LDQS)
/DDR_DQS1+: U1.C2 (PS_DDR_DQS_P0_502), U2.C7 (UDQS)
/DDR_DQS1-: U1.B2 (PS_DDR_DQS_N0_502), U2.B7 (~UDQS)
/DDR_ODT: U1.N5 (PS_DDR_ODT_502), U2.K1 (ODT)
/DDR_VRN: R4.1, U1.G5 (PS_DDR_VRN_502)
/DDR_VRP: R5.1, U1.H5 (PS_DDR_VRP_502)
/DDR_nCAS: U1.P5 (PS_DDR_CAS_B_502), U2.K3 (~CAS)
/DDR_nCS: U1.N1 (PS_DDR_CS_B_502), U2.L2 (~CS)
/DDR_nRAS: U1.P4 (PS_DDR_RAS_B_502), U2.J3 (~RAS)
/DDR_nWE: U1.M5 (PS_DDR_WE_B_502), U2.L3 (~WE)
/DONE_: D2.1 (K), R7.2
/EXT_SYNC: J16.1, R14.1
/INIT_: D3.1 (K), R8.2
/LED3_: D7.2 (A), R20.2
/PMIC_INTLDO: C117.1, C118.1, U7.40 (INTLDO)
/PS_CLK_: R9.1, X4.3 (OUT)
/SD0_CK_: R11.1, U1.D14 (PS_MIO40_501)
/TRANS_CMOS_FB_CLK: U1.K18 (IO_L12N_T1_MRCC_35), U3.F10 (FB_CLK+)
/TRANS_CMOS_RX_D0: U1.E17 (IO_L3P_T0_DQS_AD1P_35), U3.K11 (P1_D0/RX_D0-)
/TRANS_CMOS_RX_D1: U1.F16 (IO_L6P_T0_35), U3.J12 (P1_D1/RX_D0+)
/TRANS_CMOS_RX_D2: U1.J20 (IO_L17P_T2_AD5P_35), U3.K10 (P1_D2/RX_D1-)
/TRANS_CMOS_RX_D3: U1.F17 (IO_L6N_T0_VREF_35), U3.J11 (P1_D3/RX_D1+)
/TRANS_CMOS_RX_D4: U1.F20 (IO_L15N_T2_DQS_AD12N_35), U3.K9 (P1_D4/RX_D2-)
/TRANS_CMOS_RX_D5: U1.G15 (IO_L19N_T3_VREF_35), U3.J10 (P1_D5/RX_D2+)
/TRANS_CMOS_RX_D6: U1.G19 (IO_L18P_T2_AD13P_35), U3.K8 (P1_D6/RX_D3-)
/TRANS_CMOS_RX_D7: U1.G17 (IO_L16P_T2_35), U3.J9 (P1_D7/RX_D3+)
/TRANS_CMOS_RX_D8: U1.E18 (IO_L5P_T0_AD9P_35), U3.K7 (P1_D8/RX_D4-)
/TRANS_CMOS_RX_D9: U1.G18 (IO_L16N_T2_35), U3.J8 (P1_D9/RX_D4+)
/TRANS_CMOS_RX_D10: U1.E19 (IO_L5N_T0_AD9N_35), U3.J7 (P1_D10/RX_D5-)
/TRANS_CMOS_RX_D11: U1.H18 (IO_L14N_T2_AD4N_SRCC_35), U3.H8 (P1_D11/RX_D5+)
/TRANS_CMOS_RX_FRAME: U1.H17 (IO_L13N_T2_MRCC_35), U3.G8 (RX_FRAME+)
/TRANS_CMOS_TX_D0: U1.M18 (IO_L8N_T1_AD10N_35), U3.E12 (P0_D0/TX_D0-)
/TRANS_CMOS_TX_D1: U1.L17 (IO_L11N_T1_SRCC_35), U3.D11 (P0_D1/TX_D0+)
/TRANS_CMOS_TX_D2: U1.M19 (IO_L7P_T1_AD2P_35), U3.E11 (P0_D2/TX_D1-)
/TRANS_CMOS_TX_D3: U1.M15 (IO_L23N_T3_35), U3.D10 (P0_D3/TX_D1+)
/TRANS_CMOS_TX_D4: U1.K16 (IO_L24P_T3_AD15P_35), U3.E10 (P0_D4/TX_D2-)
/TRANS_CMOS_TX_D5: U1.M17 (IO_L8P_T1_AD10P_35), U3.D9 (P0_D5/TX_D2+)
/TRANS_CMOS_TX_D6: U1.J16 (IO_L24N_T3_AD15N_35), U3.E9 (P0_D6/TX_D3-)
/TRANS_CMOS_TX_D7: U1.N16 (IO_L21N_T3_DQS_AD14N_35), U3.D8 (P0_D7/TX_D3+)
/TRANS_CMOS_TX_D8: U1.L16 (IO_L11P_T1_SRCC_35), U3.E8 (P0_D8/TX_D4-)
/TRANS_CMOS_TX_D9: U1.M14 (IO_L23P_T3_35), U3.D7 (P0_D9/TX_D4+)
/TRANS_CMOS_TX_D10: U1.H15 (IO_L19P_T3_35), U3.F8 (P0_D10/TX_D5-)
/TRANS_CMOS_TX_D11: U1.K19 (IO_L10P_T1_AD11P_35), U3.E7 (P0_D11/TX_D5+)
/TRANS_CMOS_TX_FRAME: U1.J19 (IO_L10N_T1_AD11N_35), U3.G9 (TX_FRAME+)
/TRANS_CTRL_IN0: U1.L14 (IO_L22P_T3_AD7P_35), U3.C5 (CTRL_IN0)
/TRANS_CTRL_IN1: U1.L15 (IO_L22N_T3_AD7N_35), U3.C6 (CTRL_IN1)
/TRANS_CTRL_IN2: U1.J15 (IO_25_35), U3.D6 (CTRL_IN2)
/TRANS_CTRL_IN3: U1.K14 (IO_L20P_T3_AD6P_35), U3.D5 (CTRL_IN3)
/TRANS_CTRL_OUT0: U1.B20 (IO_L1N_T0_AD0N_35), U3.D4 (CTRL_OUT0)
/TRANS_CTRL_OUT1: U1.A20 (IO_L2N_T0_AD8N_35), U3.E4 (CTRL_OUT1)
/TRANS_CTRL_OUT2: U1.J14 (IO_L20N_T3_AD6N_35), U3.E5 (CTRL_OUT2)
/TRANS_CTRL_OUT3: U1.C20 (IO_L1P_T0_AD0P_35), U3.E6 (CTRL_OUT3)
/TRANS_CTRL_OUT4: U1.G20 (IO_L18N_T2_AD13N_35), U3.F6 (CTRL_OUT4)
/TRANS_CTRL_OUT5: U1.N15 (IO_L21P_T3_DQS_AD14P_35), U3.F5 (CTRL_OUT5)
/TRANS_CTRL_OUT6: U1.L20 (IO_L9N_T1_DQS_AD3N_35), U3.F4 (CTRL_OUT6)
/TRANS_CTRL_OUT7: U1.D19 (IO_L4P_T0_35), U3.G4 (CTRL_OUT7)
/TRANS_ENABLE: U1.D18 (IO_L3N_T0_DQS_AD1N_35), U3.G6 (ENABLE)
/TRANS_ENAGC: U1.J18 (IO_L14P_T2_AD4P_SRCC_35), U3.G5 (EN_AGC)
/TRANS_MRCC_CLKOUT: U1.H16 (IO_L13P_T2_MRCC_35), U3.J6 (CLK_OUT)
/TRANS_MRCC_DATA_CLK: U1.K17 (IO_L12P_T1_MRCC_35), U3.G11 (DATA_CLK+)
/TRANS_OSC_N: C37.1, X1.3 (OUT)
/TRANS_RBIAS: R12.1, U3.L4 (RBIAS)
/TRANS_RST: U1.B14 (PS_MIO47_501), U3.K5 (~RESET)
/TRANS_RXRF0_N: C39.1, FL3.3 (RF_N)
/TRANS_RXRF0_P: C38.1, FL3.4 (RF_P)
/TRANS_RXRF1_N: C54.1, FL4.3 (RF_N)
/TRANS_RXRF1_P: C41.1, FL4.4 (RF_P)
/TRANS_SPI_CLK: U1.A16 (PS_MIO24_501), U3.J5 (SPI_CLK)
/TRANS_SPI_MISO: U1.D11 (PS_MIO23_501), U3.L6 (SPI_MISO)
/TRANS_SPI_MOSI: U1.B17 (PS_MIO22_501), U3.J4 (SPI_MOSI)
/TRANS_SPI_SS: U1.F15 (PS_MIO25_501), U3.K6 (SPI_~EN)
/TRANS_SYNC: R13.1, U1.H20 (IO_L17N_T2_AD5N_35)
/TRANS_TXNRX: U1.D20 (IO_L4N_T0_35), U3.H4 (TX~RX)
/TRANS_TXRF0_N: C33.1, FL1.4 (RF_P)
/TRANS_TXRF0_P: C34.1, FL1.3 (RF_N)
/TRANS_TXRF1_N: C36.1, FL2.4 (RF_P)
/TRANS_TXRF1_P: C35.1, FL2.3 (RF_N)
/VCC_PLL: C71.1, C72.1, FB3.1, U1.G8 (VCCPLL)
/VCC_PL_CLK: C120.1, C121.1, FB5.1
/VCC_PS_CLK: C85.1, C86.1, FB4.1, X4.1 (EN), X4.4 (Vdd)
/VREF_DDR1: C18.1, C23.1, C24.1, U1.H6 (PS_DDR_VREF0_502), U1.P6 (PS_DDR_VREF1_502)
/VREF_DDR2: C26.1, U2.M8 (VREFCA)
/VREF_DDR3: C28.1, U2.H1 (VREFDQ)
DDR_CK+: R1.1, U1.L2 (PS_DDR_CKP_502), U2.J7 (CK)
DDR_CK-: R1.2, U1.M2 (PS_DDR_CKN_502), U2.K7 (~CK)
DDR_nRST: R2.1, U1.B4 (PS_DDR_DRST_B_502), U2.T2 (~RESET)
DONE: R7.1, RN9.6 (R3.2), U1.R11 (DONE_0)
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

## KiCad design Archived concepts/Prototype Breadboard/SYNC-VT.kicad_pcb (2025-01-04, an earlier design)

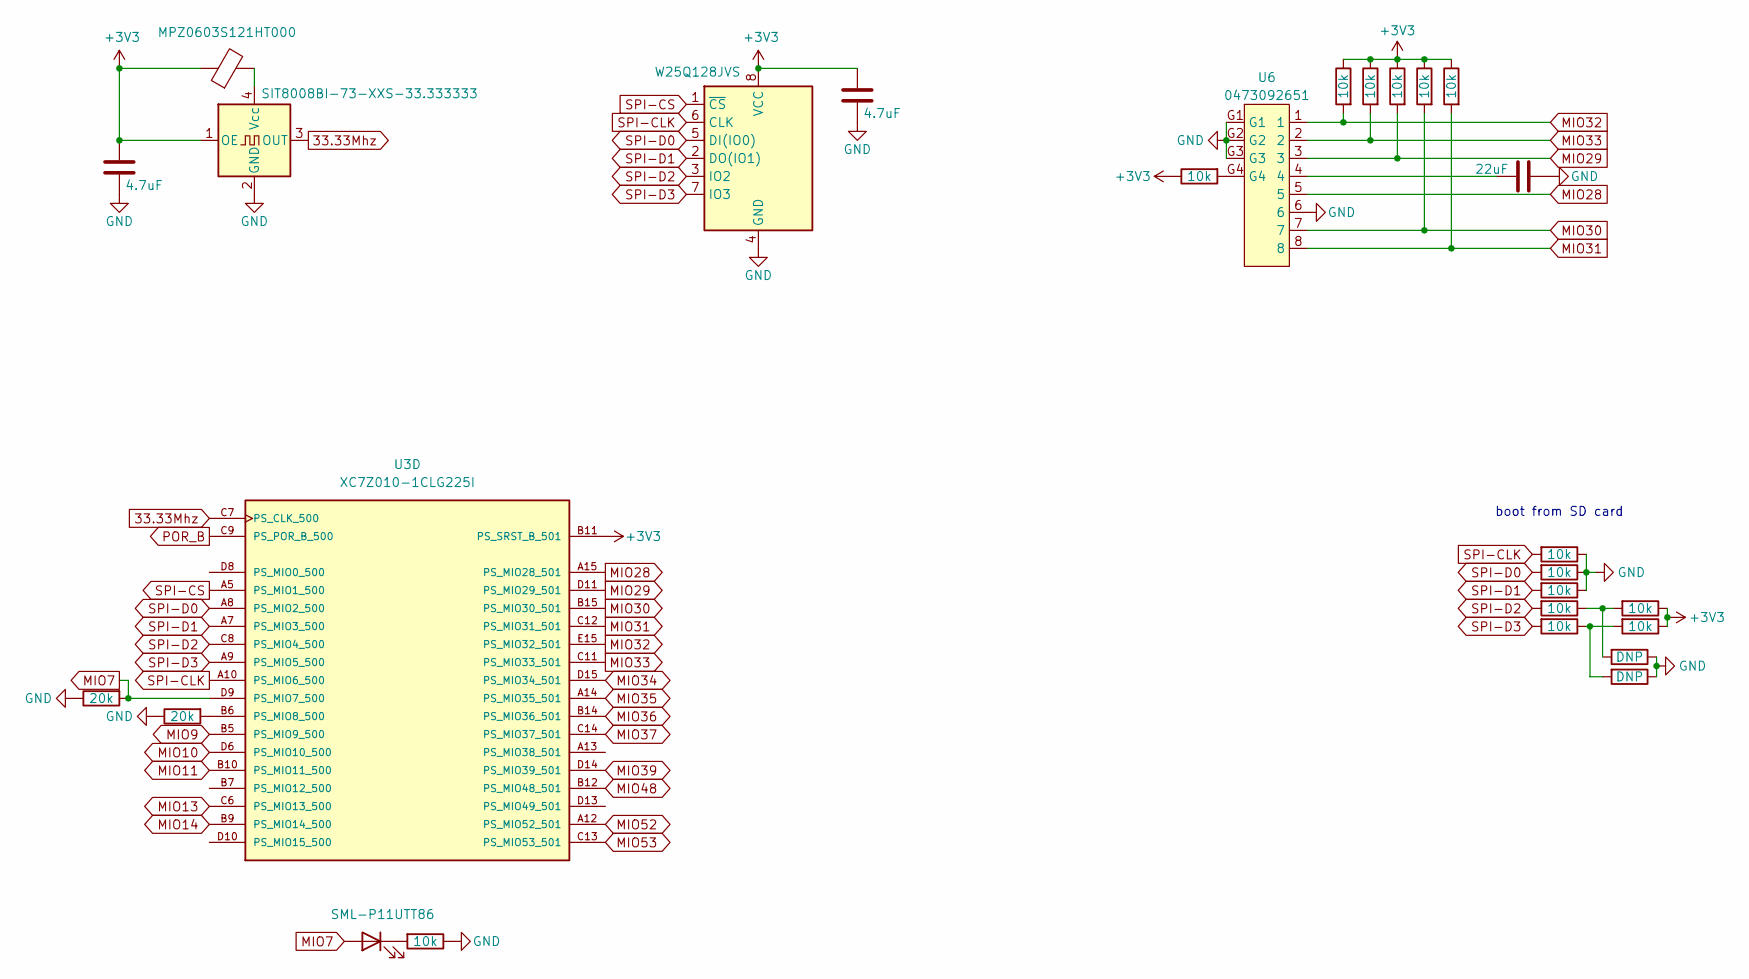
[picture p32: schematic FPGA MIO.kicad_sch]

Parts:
C1: 22uF; C_0402_1005Metric
C26, C27: 4.7uF; C_0402_1005Metric
D2: SML-P11UTT86; LED_0402_1005Metric
FB3: MPZ0603S121HT000; C_0201_0603Metric
R14, R20: 20k; C_0402_1005Metric
R15, R16, R17, R18, R19, R21, R22, R23, R24, R25, R26, R27, R28, R40: 10k; C_0402_1005Metric
R41, R42: DNP; C_0402_1005Metric
U3: XC7Z010-1CLG225I; 225-LFBGA; MPN XC7Z010-1CLG225I
U5: W25Q128JVS; SOIC-8_5.23x5.23mm_P1.27mm
U6: 0473092651; CONN12_47309-2651_MOL
X1: SIT8008BI-73-XXS-33.333333; Oscillator_SMD_SeikoEpson_SG210-4Pin_2.5x2.0mm

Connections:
33.33Mhz: U3.C7 (PS_CLK_500), X1.3 (OUT)
+3V3: C26.1, C27.1, FB3.1, R21.1, R23.1, R24.1, R25.1, R26.1, R27.1, R28.1, R40.1, U3.B11 (PS_SRST_B_501), U5.8 (VCC), X1.1 (OE); also elsewhere on the board
GND: C1.2, C26.2, C27.2, R14.1, R15.1, R16.1, R17.1, R20.1, R22.1, R41.1, R42.1, U5.4 (GND), U6.6, U6.G1, U6.G2, U6.G3, X1.2 (GND); also elsewhere on the board
MIO7: D2.2 (A), R20.2, U3.D9 (PS_MIO7_500)
MIO9: U3.B5 (PS_MIO9_500); also elsewhere on the board
MIO10: U3.D6 (PS_MIO10_500); also elsewhere on the board
MIO11: U3.B10 (PS_MIO11_500); also elsewhere on the board
MIO13: U3.C6 (PS_MIO13_500); also elsewhere on the board
MIO14: U3.B9 (PS_MIO14_500); also elsewhere on the board
MIO28: U3.A15 (PS_MIO28_501), U6.5
MIO29: R26.2, U3.D11 (PS_MIO29_501), U6.3
MIO30: R27.2, U3.B15 (PS_MIO30_501), U6.7
MIO31: R28.2, U3.C12 (PS_MIO31_501), U6.8
MIO32: R24.2, U3.E15 (PS_MIO32_501), U6.1
MIO33: R25.2, U3.C11 (PS_MIO33_501), U6.2
MIO34: U3.D15 (PS_MIO34_501)
MIO35: U3.A14 (PS_MIO35_501); also elsewhere on the board
MIO36: U3.B14 (PS_MIO36_501); also elsewhere on the board
MIO37: U3.C14 (PS_MIO37_501); also elsewhere on the board
MIO39: U3.D14 (PS_MIO39_501)
MIO48: U3.B12 (PS_MIO48_501); also elsewhere on the board
MIO52: U3.A12 (PS_MIO52_501); also elsewhere on the board
MIO53: U3.C13 (PS_MIO53_501); also elsewhere on the board
unnamed: C1.1, U6.4
unnamed: D2.1 (K), R22.2
unnamed: R18.1, R21.2, R41.2
unnamed: R19.1, R40.2, R42.2
unnamed: R23.2, U6.G4
unnamed: R14.2, U3.B6 (PS_MIO8_500)
unnamed: FB3.2, X1.4 (Vcc)
POR_B: U3.C9 (PS_POR_B_500); also elsewhere on the board
SPI-CLK: R15.2, U3.A10 (PS_MIO6_500), U5.6 (CLK)
SPI-CS: U3.A5 (PS_MIO1_500), U5.1 (~CS)
SPI-D0: R16.2, U3.A8 (PS_MIO2_500), U5.5 (DI(IO0))
SPI-D1: R17.2, U3.A7 (PS_MIO3_500), U5.2 (DO(IO1))
SPI-D2: R18.2, U3.C8 (PS_MIO4_500), U5.3 (IO2)
SPI-D3: R19.2, U3.A9 (PS_MIO5_500), U5.7 (IO3)

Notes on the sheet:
boot from SD card

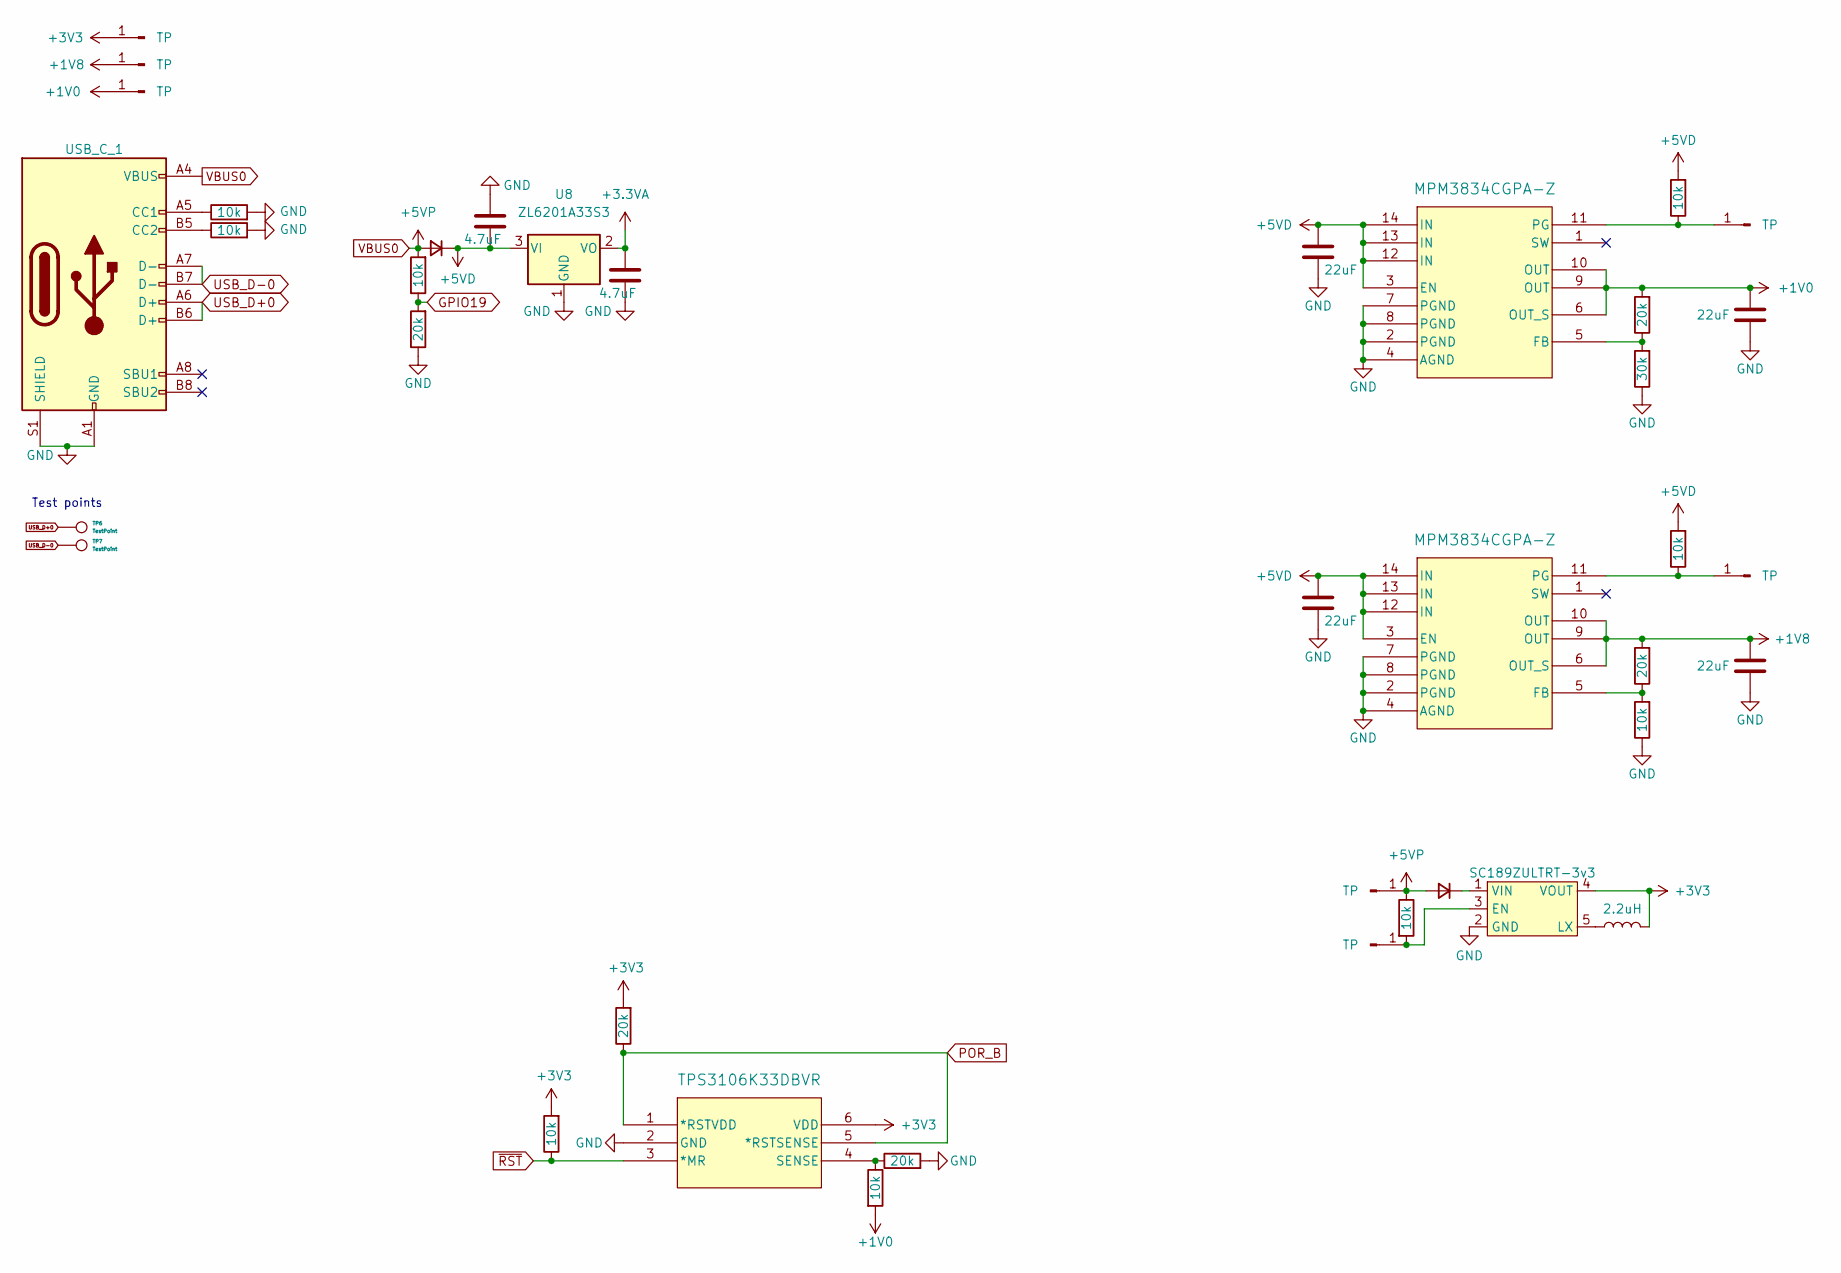
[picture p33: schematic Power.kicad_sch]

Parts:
C5, C8, C10, C11: 22uF; C_0402_1005Metric
C36, C37: 4.7uF; C_0402_1005Metric
D3: SOD-523 General; D_SOD-523
D4: SOD-523 General; D_SMA
L1: 2.2uH; C_1812_4532Metric
R1, R3, R8, R10, R36: 20k; C_0402_1005Metric
R2: 30k; C_0402_1005Metric
R4, R5, R6, R7, R9, R33, R34, R35, R38: 10k; C_0402_1005Metric
TP1, TP2, TP3, TP4, TP5, TP10, TP11: TP; TestPoint_Pad_1.0x1.0mm
TP6, TP7: TestPoint; TestPoint_Pad_D1.5mm
U1, U2: MPM3834CGPA-Z; ECLGA-14_MPM3834C_MNP
U4: TPS3106K33DBVR; DBV6-L
U8: ZL6201A33S3; SOT-23
U11: SC189ZULTRT-3v3; SOT-23-5
USB_C_ESP1: USB_C_1; USB_C_Receptacle_GCT_USB4105-xx-A_16P_TopMnt_Horizontal

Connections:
+1V0: C11.2, R1.2, R9.2, TP5.1, U1.6 (OUT_S), U1.9 (OUT), U1.10 (OUT); also elsewhere on the board
+1V8: C5.2, R3.2, TP4.1, U2.6 (OUT_S), U2.9 (OUT), U2.10 (OUT); also elsewhere on the board
+3.3VA: C37.1, U8.2 (VO); also elsewhere on the board
+3V3: L1.2, R7.2, R10.2, TP3.1, U4.6 (VDD), U11.4 (VOUT); also elsewhere on the board
+5VD: C8.1, C10.1, C36.2, D4.1 (K), R4.2, R6.2, U1.3 (EN), U1.12 (IN), U1.13 (IN), U1.14 (IN), U2.3 (EN), U2.12 (IN), U2.13 (IN), U2.14 (IN), U8.3 (VI)
GND: C5.1, C8.2, C10.2, C11.1, C36.1, C37.2, R2.1, R5.1, R8.2, R33.2, R34.2, R36.1, U1.2 (PGND), U1.4 (AGND), U1.7 (PGND), U1.8 (PGND), U2.2 (PGND), U2.4 (AGND), U2.7 (PGND), U2.8 (PGND), U4.2 (GND), U8.1 (GND), U11.2 (GND), USB_C_ESP1.A1 (GND), USB_C_ESP1.A12 (GND), USB_C_ESP1.B1 (GND), USB_C_ESP1.B12 (GND), USB_C_ESP1.S1 (SHIELD); also elsewhere on the board
GPIO19: R35.1, R36.2; also elsewhere on the board
unnamed: D3.1 (K), U11.1 (VIN)
unnamed: R6.1, TP1.1, U2.11 (PG)
unnamed: R4.1, TP2.1, U1.11 (PG)
unnamed: R38.2, TP11.1, U11.3 (EN)
unnamed: R1.1, R2.2, U1.5 (FB)
unnamed: R3.1, R5.2, U2.5 (FB)
unnamed: R8.1, R9.1, U4.4 (SENSE)
unnamed: L1.1, U11.5 (LX)
unnamed: R33.1, USB_C_ESP1.A5 (CC1)
unnamed: R34.1, USB_C_ESP1.B5 (CC2)
POR_B: R10.1, U4.1 (*RSTVDD), U4.5 (*RSTSENSE); also elsewhere on the board
USB_D+0: TP6.1, USB_C_ESP1.A6 (D+), USB_C_ESP1.B6 (D+); also elsewhere on the board
USB_D-0: TP7.1, USB_C_ESP1.A7 (D-), USB_C_ESP1.B7 (D-); also elsewhere on the board
VBUS0: D3.2 (A), D4.2 (A), R35.2, R38.1, TP10.1, USB_C_ESP1.A4 (VBUS), USB_C_ESP1.A9 (VBUS), USB_C_ESP1.B4 (VBUS), USB_C_ESP1.B9 (VBUS); also elsewhere on the board
~RST: R7.1, U4.3 (*MR)

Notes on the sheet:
Test points

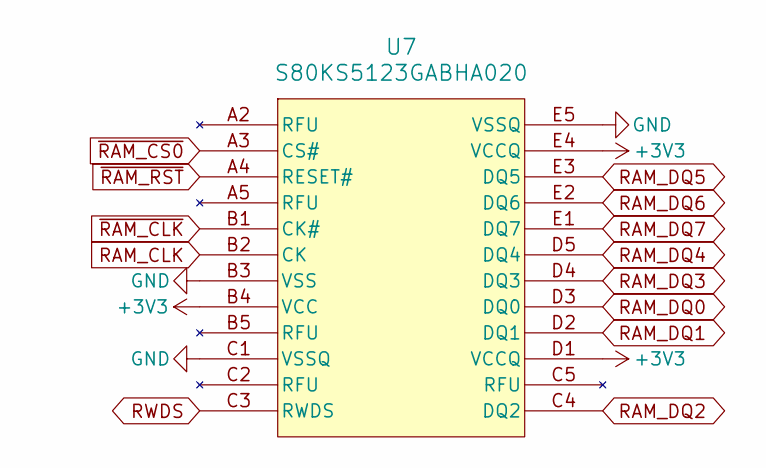
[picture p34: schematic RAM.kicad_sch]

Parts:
U7: S80KS5123GABHA020; PG-BGA-24-801

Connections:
+3V3: U7.B4 (VCC), U7.D1 (VCCQ), U7.E4 (VCCQ); also elsewhere on the board
GND: U7.B3 (VSS), U7.C1 (VSSQ), U7.E5 (VSSQ); also elsewhere on the board
RAM_CLK: U7.B2 (CK); also elsewhere on the board
RAM_DQ0: U7.D3 (DQ0); also elsewhere on the board
RAM_DQ1: U7.D2 (DQ1); also elsewhere on the board
RAM_DQ2: U7.C4 (DQ2); also elsewhere on the board
RAM_DQ3: U7.D4 (DQ3); also elsewhere on the board
RAM_DQ4: U7.D5 (DQ4); also elsewhere on the board
RAM_DQ5: U7.E3 (DQ5); also elsewhere on the board
RAM_DQ6: U7.E2 (DQ6); also elsewhere on the board
RAM_DQ7: U7.E1 (DQ7); also elsewhere on the board
RWDS: U7.C3 (RWDS); also elsewhere on the board
~RAM_CLK: U7.B1 (CK#); also elsewhere on the board
~RAM_CS0: U7.A3 (CS#); also elsewhere on the board
~RAM_RST: U7.A4 (RESET#); also elsewhere on the board


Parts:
U3: XC7Z010-1CLG225I; 225-LFBGA; MPN XC7Z010-1CLG225I

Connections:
AIO0N: U3.E13 (IO_L1N_T0_AD0N_35); also elsewhere on the board
AIO3N: U3.F14 (IO_L3N_T0_DQS_AD1N_35); also elsewhere on the board
AIO3P: U3.F13 (IO_L3P_T0_DQS_AD1P_35); also elsewhere on the board
AIO5N: U3.F15 (IO_L5N_T0_AD9N_35); also elsewhere on the board
AIO5P: U3.G15 (IO_L5P_T0_AD9P_35); also elsewhere on the board
AIO8N: U3.E12 (IO_L2N_T0_AD8N_35); also elsewhere on the board
GPIO16: U3.M9 (IO_L19P_T3_34); also elsewhere on the board
GPIO17: U3.H11 (IO_L6P_T0_34); also elsewhere on the board
IO1N: U3.H12 (IO_L1N_T0_34); also elsewhere on the board
IO2N: U3.H13 (IO_L2N_T0_34); also elsewhere on the board
IO3N: U3.H14 (IO_L3N_T0_DQS_34); also elsewhere on the board
IO3P: U3.G14 (IO_L3P_T0_DQS_PUDC_B_34)
IO4N: U3.K15 (IO_L4N_T0_34); also elsewhere on the board
IO4P: U3.J15 (IO_L4P_T0_34); also elsewhere on the board
IO5N: U3.J14 (IO_L5N_T0_34); also elsewhere on the board
IO5P: U3.J13 (IO_L5P_T0_34); also elsewhere on the board
IO10P: U3.K13 (IO_L10P_T1_34); also elsewhere on the board
IO11N: U3.K12 (IO_L11N_T1_SRCC_34); also elsewhere on the board
IO11P: U3.K11 (IO_L11P_T1_SRCC_34); also elsewhere on the board
IO12N: U3.M12 (IO_L12N_T1_MRCC_34); also elsewhere on the board
IO12P: U3.L12 (IO_L12P_T1_MRCC_34); also elsewhere on the board
IO13P: U3.N11 (IO_L13P_T2_MRCC_34); also elsewhere on the board
IO15N: U3.R15 (IO_L15N_T2_DQS_34); also elsewhere on the board
IO16N: U3.R11 (IO_L16N_T2_34); also elsewhere on the board
IO18N: U3.P14 (IO_L18N_T2_34); also elsewhere on the board
IO19N: U3.N9 (IO_L19N_T3_VREF_34); also elsewhere on the board
IO20N: U3.R8 (IO_L20N_T3_34); also elsewhere on the board
IO20P: U3.R7 (IO_L20P_T3_34); also elsewhere on the board
IO21N: U3.M11 (IO_L21N_T3_DQS_34); also elsewhere on the board
IO21P: U3.M10 (IO_L21P_T3_DQS_34); also elsewhere on the board
IO22N: U3.N8 (IO_L22N_T3_34); also elsewhere on the board
IO22P: U3.N7 (IO_L22P_T3_34); also elsewhere on the board
IO23N: U3.P9 (IO_L23N_T3_34); also elsewhere on the board
IO23P: U3.P8 (IO_L23P_T3_34); also elsewhere on the board
IO24N: U3.R10 (IO_L24N_T3_34); also elsewhere on the board
IO24P: U3.P10 (IO_L24P_T3_34); also elsewhere on the board
RAM_CLK: U3.N14 (IO_L7N_T1_34); also elsewhere on the board
RAM_DQ0: U3.P13 (IO_L18P_T2_34); also elsewhere on the board
RAM_DQ1: U3.R13 (IO_L17N_T2_34); also elsewhere on the board
RAM_DQ2: U3.M14 (IO_L9N_T1_DQS_34); also elsewhere on the board
RAM_DQ3: U3.N13 (IO_L7P_T1_34); also elsewhere on the board
RAM_DQ4: U3.L13 (IO_L10N_T1_34); also elsewhere on the board
RAM_DQ5: U3.N12 (IO_L13N_T2_MRCC_34); also elsewhere on the board
RAM_DQ6: U3.P11 (IO_L16P_T2_34); also elsewhere on the board
RAM_DQ7: U3.R12 (IO_L17P_T2_34); also elsewhere on the board
RWDS: U3.L15 (IO_L8P_T1_34); also elsewhere on the board
~RAM_CLK: U3.P15 (IO_L15P_T2_DQS_34); also elsewhere on the board
~RAM_CS0: U3.M15 (IO_L8N_T1_34); also elsewhere on the board
~RAM_RST: U3.L14 (IO_L9P_T1_DQS_34); also elsewhere on the board

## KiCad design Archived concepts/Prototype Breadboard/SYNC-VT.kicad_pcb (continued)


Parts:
C9, C12: 22uF; C_0402_1005Metric
C14, C15, C16, C17, C18, C20, C21, C22, C24, C25: 4.7uF; C_0402_1005Metric
D1: SML-P11UTT86; LED_0402_1005Metric
FB1, FB2: MPZ0603S121HT000; C_0201_0603Metric
J6: Conn_01x04_MountingPin; PinSocket_1x04_P2.54mm_Vertical
R11, R12, R13: 10k; C_0402_1005Metric
U3: XC7Z010-1CLG225I; 225-LFBGA; MPN XC7Z010-1CLG225I

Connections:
+1V0: C9.2, C20.1, C21.1, C22.1, U3.E10 (VCCINT), U3.F9 (VCCINT), U3.G6 (VCCPINT), U3.G10 (VCCINT), U3.H5 (VCCPINT), U3.J10 (VCCINT), U3.K5 (VCCPINT), U3.L10 (VCCINT); also elsewhere on the board
+1V8: C12.2, C14.1, C15.1, C16.1, C17.1, FB1.2, U3.B3 (VCCO_DDR_502), U3.E4 (VCCO_DDR_502), U3.E6 (VCCBATT_0), U3.F1 (VCCO_DDR_502), U3.F5 (VCCPLL), U3.H9 (VCCAUX), U3.J2 (VCCO_DDR_502), U3.J6 (VCCPAUX), U3.J8 (VCCAUX), U3.K9 (VCCAUX), U3.L6 (VCCPAUX), U3.M3 (VCCO_DDR_502), U3.R4 (VCCO_DDR_502); also elsewhere on the board
+3V3: C24.1, C25.1, D1.2 (A), R12.1, R13.2, U3.A6 (VCCO_MIO0_500), U3.B13 (VCCO_MIO1_501), U3.C10 (VCCO_MIO1_501), U3.D7 (VCCO_MIO0_500), U3.E14 (VCCO_MIO1_501), U3.F6 (CFGBVS_0), U3.F11 (VCCO_35), U3.G4 (RSVSVCC1), U3.H4 (RSVSVCC3), U3.H15 (VCCO_35), U3.J4 (RSVSVCC2), U3.J12 (VCCO_34), U3.K8 (VCCO_0), U3.M13 (VCCO_34), U3.N10 (VCCO_34), U3.P7 (VCCO_34), U3.R14 (VCCO_34); also elsewhere on the board
GND: C9.1, C12.1, C14.2, C15.2, C16.2, C17.2, C20.2, C21.2, C22.2, C24.2, C25.2, FB2.2, U3.A1 (GND), U3.A11 (GND), U3.B8 (GND), U3.C5 (GND), U3.C15 (GND), U3.D2 (GND), U3.D12 (GND), U3.E5 (GND), U3.E7 (GND), U3.E8 (RSVDGND), U3.E9 (GND), U3.F10 (GND), U3.G3 (GND), U3.G5 (GND), U3.G13 (GND), U3.H6 (GND), U3.H10 (GND), U3.J5 (GND), U3.J9 (GND), U3.K4 (GND), U3.K7 (GND), U3.K10 (GND), U3.K14 (GND), U3.L1 (GND), U3.L5 (GND), U3.L11 (GND), U3.M8 (GND), U3.N5 (GND), U3.N15 (GND), U3.P2 (GND), U3.P12 (GND), U3.R9 (GND); also elsewhere on the board
GNDA: C18.2, FB2.1, U3.F8 (GNDADC_0), U3.G8 (VREFN_0), U3.H7 (VREFP_0)
GPIO12: J6.2, U3.L9 (TMS_0); also elsewhere on the board
GPIO13: J6.3, U3.L8 (TDO_0); also elsewhere on the board
GPIO14: J6.4, U3.L7 (TDI_0); also elsewhere on the board
GPIO15: J6.1, U3.G9 (TCK_0); also elsewhere on the board
unnamed: D1.1 (K), R11.1
unnamed: R11.2, U3.M7 (DONE_0)
unnamed: R12.2, U3.D5 (INIT_B_0)
unnamed: R13.1, U3.K6 (PROGRAM_B_0)
VCCQ: C18.1, FB1.1, U3.F7 (VCCADC_0)


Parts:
C2, C3: 22pF; C_0402_1005Metric
C4, C6, C7, C28, C29, C30, C31, C32, C33, C34, C35, C38: 4.7uF; C_0402_1005Metric
FLASH1: W25Q16JVUXIQ; SON-8-1EP_3x2mm_P0.5mm_EP1.4x1.6mm
J1, J2: Button; SW_SPST_PTS810
J3, J7: Conn_01x30_MountingPin; PinHeader_1x30_P2.54mm_Vertical
J4, J5: Conn_01x25_MountingPin; PinHeader_1x25_P2.54mm_Vertical
J8: Conn_01x24_MountingPin; TE_2-1734839-4_1x24-1MP_P0.5mm_Horizontal
R32, R37: 10k; C_0402_1005Metric
TP8, TP9: TestPoint; TestPoint_Pad_D1.5mm
U9: RP2040; QFN-56-1EP_7x7mm_P0.4mm_EP3.2x3.2mm; LCSC C2040
U10: NanoS3
Y1: 3225-4P 12MHz; Crystal_SMD_3225-4Pin_3.2x2.5mm

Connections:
+1V1: C4.1, C6.1, C7.1, U9.23 (DVDD), U9.45 (VREG_VOUT), U9.50 (DVDD)
+1V2: J8.15
+2V8: J8.14, J8.21
+3.3VA: C28.1, C29.1, C30.1, C31.1, C32.1, C33.1, C34.1, C35.1, C38.1, FLASH1.8 (VCC), J3.3, J4.3, J5.3, J7.3, R37.1, U9.1 (IOVDD), U9.10 (IOVDD), U9.22 (IOVDD), U9.33 (IOVDD), U9.42 (IOVDD), U9.43 (ADC_AVDD), U9.44 (VREG_IN), U9.48 (USB_VDD), U9.49 (IOVDD); also elsewhere on the board
+3V3: U10.8 (3v3); also elsewhere on the board
/Peripheral/RUN: J1.1, U9.26 (RUN)
/Peripheral/SWCLK: TP8.1, U9.24 (SWCLK)
/Peripheral/SWD: TP9.1, U9.25 (SWD)
AIO0N: J8.7, U10.11 (IO18); also elsewhere on the board
AIO3N: J8.6, U10.12 (IO17); also elsewhere on the board
AIO3P: J8.5, U10.13 (IO16); also elsewhere on the board
AIO5N: J8.4, U10.14 (IO15); also elsewhere on the board
AIO5P: J8.3, U10.15 (IO14); also elsewhere on the board
AIO8N: J8.8, U10.10 (IO21); also elsewhere on the board
GND: C2.2, C3.2, C4.2, C6.2, C7.2, C28.2, C29.2, C30.2, C31.2, C32.2, C33.2, C34.2, C35.2, C38.2, FLASH1.4 (GND), FLASH1.9 (EP), J1.2, J2.2, J3.2, J3.15, J3.20, J3.25, J3.30, J4.2, J4.15, J4.20, J4.25, J5.2, J5.15, J5.20, J5.25, J7.2, J7.15, J7.20, J7.25, J7.30, J8.10, J8.23, J8.MP (MountPin), U9.19 (TESTEN), U9.57 (GND), U10.2 (GND), Y1.2, Y1.4; also elsewhere on the board
GPIO0: J3.4, J7.4, U9.2 (GPIO0)
GPIO1: J3.5, J7.5, U9.3 (GPIO1)
GPIO2: J3.6, J7.6, U9.4 (GPIO2)
GPIO3: J3.7, J7.7, U9.5 (GPIO3)
GPIO4: J3.8, J7.8, U9.6 (GPIO4)
GPIO5: J3.9, J7.9, U9.7 (GPIO5)
GPIO6: J3.10, J7.10, U9.8 (GPIO6)
GPIO7: J3.11, J7.11, U9.9 (GPIO7)
GPIO8: U9.11 (GPIO8)
GPIO9: U9.12 (GPIO9)
GPIO10: U9.13 (GPIO10)
GPIO11: U9.14 (GPIO11)
GPIO12: U9.15 (GPIO12); also elsewhere on the board
GPIO13: U9.16 (GPIO13); also elsewhere on the board
GPIO14: U9.17 (GPIO14); also elsewhere on the board
GPIO15: U9.18 (GPIO15); also elsewhere on the board
GPIO16: U9.27 (GPIO16); also elsewhere on the board
GPIO17: U9.28 (GPIO17); also elsewhere on the board
GPIO18: U9.29 (GPIO18)
GPIO19: U9.30 (GPIO19); also elsewhere on the board
GPIO20: U9.31 (GPIO20)
GPIO21: U9.32 (GPIO21)
GPIO22: J4.11, J5.11, U9.34 (GPIO22)
GPIO23: J4.10, J5.10, U9.35 (GPIO23)
GPIO24: J4.9, J5.9, U9.36 (GPIO24)
GPIO25: J4.8, J5.8, U9.37 (GPIO25)
GPIO26: J4.7, J5.7, U9.38 (GPIO26_ADC0)
GPIO27: J4.6, J5.6, U9.39 (GPIO27_ADC1)
GPIO28: J4.5, J5.5, U9.40 (GPIO28_ADC2)
GPIO29: J4.4, J5.4, U9.41 (GPIO29_ADC3)
IO1N: U10.7 (EN); also elsewhere on the board
IO2N: J8.17, U10.28 (IO8); also elsewhere on the board
IO3N: J8.16, U10.27 (IO9); also elsewhere on the board
IO4N: U10.3 (RESET); also elsewhere on the board
IO4P: J8.13, U10.26 (IO34); also elsewhere on the board
IO5N: J8.12, U10.25 (IO36); also elsewhere on the board
IO5P: J8.11, U10.24 (IO37); also elsewhere on the board
IO10P: J8.9, U10.23 (IO35); also elsewhere on the board
IO11N: J8.22, U10.31 (RX); also elsewhere on the board
IO11P: J8.20, U10.32 (TX); also elsewhere on the board
IO12N: J8.18, U10.29 (IO0); also elsewhere on the board
IO12P: J8.19, U10.30 (IO33); also elsewhere on the board
IO13P: J3.26, J7.26; also elsewhere on the board
IO15N: J3.28, J7.28; also elsewhere on the board
IO16N: J3.27, J7.27; also elsewhere on the board
IO18N: J3.29, J7.29; also elsewhere on the board
IO19N: J3.14, J7.14; also elsewhere on the board
IO20N: J3.19, J7.19; also elsewhere on the board
IO20P: J3.18, J7.18; also elsewhere on the board
IO21N: J3.13, J7.13; also elsewhere on the board
IO21P: J3.12, J7.12; also elsewhere on the board
IO22N: J3.17, J7.17; also elsewhere on the board
IO22P: J3.16, J7.16; also elsewhere on the board
IO23N: J3.22, J7.22; also elsewhere on the board
IO23P: J3.21, J7.21; also elsewhere on the board
IO24N: J3.24, J7.24; also elsewhere on the board
IO24P: J3.23, J7.23; also elsewhere on the board
MIO9: J4.13, J5.13; also elsewhere on the board
MIO10: J4.14, J5.14; also elsewhere on the board
MIO11: J4.19, J5.19; also elsewhere on the board
MIO13: J4.12, J5.12; also elsewhere on the board
MIO14: J4.18, J5.18; also elsewhere on the board
MIO35: J4.22, J5.22; also elsewhere on the board
MIO36: J4.21, J5.21; also elsewhere on the board
MIO37: J4.24, J5.24; also elsewhere on the board
MIO48: J4.16, J5.16; also elsewhere on the board
MIO52: J4.17, J5.17; also elsewhere on the board
MIO53: J4.23, J5.23; also elsewhere on the board
unnamed: J2.1, R32.2
unnamed: C2.1, U9.20 (XIN), Y1.1
unnamed: C3.1, U9.21 (XOUT), Y1.3
QSPI_SCLK: FLASH1.6 (CLK), U9.52 (QSPI_SCLK)
QSPI_SD0: FLASH1.5 (DI(IO0)), U9.53 (QSPI_SD0)
QSPI_SD1: FLASH1.2 (DO(IO1)), U9.55 (QSPI_SD1)
QSPI_SD2: FLASH1.3 (IO2), U9.54 (QSPI_SD2)
QSPI_SD3: FLASH1.7 (IO3), U9.51 (QSPI_SD3)
QSPI_SS: FLASH1.1 (~CS), R32.1, R37.2, U9.56 (QSPI_SS)
USB_D+0: U9.47 (USB_DP); also elsewhere on the board
USB_D-0: U9.46 (USB_DM); also elsewhere on the board
VBUS0: J3.1, J4.1, J5.1, J7.1, U10.4 (5V); also elsewhere on the board

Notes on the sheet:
Make sure C10 is close to pin 44 of RP2040
These decoupling capacitors are meant to be put close by each 3.3V pin of the RP2040
Make sure R3 and R4 are close to RP2040



Board: 6 copper layers, 84.0 x 20.9 mm, 115 parts (47 on the bottom side), 142 nets.

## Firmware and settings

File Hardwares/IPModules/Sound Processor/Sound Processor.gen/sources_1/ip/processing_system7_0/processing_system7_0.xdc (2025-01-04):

############################################################################
##
##  Xilinx, Inc. 2006            www.xilinx.com
############################################################################
##  File name :       ps7_constraints.xdc
##
##  Details :     Constraints file
##                    FPGA family:       zynq
##                    FPGA:              xc7z010clg225-3
##                    Device Size:        xc7z010
##                    Package:            clg225
##                    Speedgrade:         -3
##
##
############################################################################
############################################################################
############################################################################
# Clock constraints                                                        #
############################################################################
create_clock -name clk_fpga_0 -period "20" [get_pins "PS7_i/FCLKCLK[0]"]
set_input_jitter clk_fpga_0 0.6
#The clocks are asynchronous, user should constrain them appropriately.#


############################################################################
# I/O STANDARDS and Location Constraints                                   #
############################################################################

set_property iostandard "SSTL15_T_DCI" [get_ports "DDR_VRP"]
set_property PACKAGE_PIN "H3" [get_ports "DDR_VRP"]
set_property slew "FAST" [get_ports "DDR_VRP"]
set_property PIO_DIRECTION "BIDIR" [get_ports "DDR_VRP"]
set_property iostandard "SSTL15_T_DCI" [get_ports "DDR_VRN"]
set_property PACKAGE_PIN "J3" [get_ports "DDR_VRN"]
set_property slew "FAST" [get_ports "DDR_VRN"]
set_property PIO_DIRECTION "BIDIR" [get_ports "DDR_VRN"]
set_property iostandard "SSTL15" [get_ports "DDR_WEB"]
set_property PACKAGE_PIN "R3" [get_ports "DDR_WEB"]
set_property slew "SLOW" [get_ports "DDR_WEB"]
set_property PIO_DIRECTION "OUTPUT" [get_ports "DDR_WEB"]
set_property iostandard "SSTL15" [get_ports "DDR_RAS_n"]
set_property PACKAGE_PIN "R6" [get_ports "DDR_RAS_n"]
set_property slew "SLOW" [get_ports "DDR_RAS_n"]
set_property PIO_DIRECTION "OUTPUT" [get_ports "DDR_RAS_n"]
set_property iostandard "SSTL15" [get_ports "DDR_ODT"]
set_property PACKAGE_PIN "K3" [get_ports "DDR_ODT"]
set_property slew "SLOW" [get_ports "DDR_ODT"]
set_property PIO_DIRECTION "OUTPUT" [get_ports "DDR_ODT"]
set_property iostandard "SSTL15" [get_ports "DDR_DRSTB"]
set_property PACKAGE_PIN "L4" [get_ports "DDR_DRSTB"]
set_property slew "FAST" [get_ports "DDR_DRSTB"]
set_property PIO_DIRECTION "BIDIR" [get_ports "DDR_DRSTB"]
set_property iostandard "DIFF_SSTL15_T_DCI" [get_ports "DDR_DQS[1]"]
set_property PACKAGE_PIN "G2" [get_ports "DDR_DQS[1]"]
set_property slew "FAST" [get_ports "DDR_DQS[1]"]
set_property PIO_DIRECTION "BIDIR" [get_ports "DDR_DQS[1]"]
set_property iostandard "DIFF_SSTL15_T_DCI" [get_ports "DDR_DQS[0]"]
set_property PACKAGE_PIN "C2" [get_ports "DDR_DQS[0]"]
set_property slew "FAST" [get_ports "DDR_DQS[0]"]
set_property PIO_DIRECTION "BIDIR" [get_ports "DDR_DQS[0]"]
set_property iostandard "DIFF_SSTL15_T_DCI" [get_ports "DDR_DQS_n[1]"]
set_property PACKAGE_PIN "F2" [get_ports "DDR_DQS_n[1]"]
set_property slew "FAST" [get_ports "DDR_DQS_n[1]"]
set_property PIO_DIRECTION "BIDIR" [get_ports "DDR_DQS_n[1]"]
set_property iostandard "DIFF_SSTL15_T_DCI" [get_ports "DDR_DQS_n[0]"]
set_property PACKAGE_PIN "B2" [get_ports "DDR_DQS_n[0]"]
set_property slew "FAST" [get_ports "DDR_DQS_n[0]"]
set_property PIO_DIRECTION "BIDIR" [get_ports "DDR_DQS_n[0]"]
set_property iostandard "SSTL15_T_DCI" [get_ports "DDR_DQ[9]"]
set_property PACKAGE_PIN "D1" [get_ports "DDR_DQ[9]"]
set_property slew "FAST" [get_ports "DDR_DQ[9]"]
set_property PIO_DIRECTION "BIDIR" [get_ports "DDR_DQ[9]"]
set_property iostandard "SSTL15_T_DCI" [get_ports "DDR_DQ[8]"]
set_property PACKAGE_PIN "E1" [get_ports "DDR_DQ[8]"]
set_property slew "FAST" [get_ports "DDR_DQ[8]"]
set_property PIO_DIRECTION "BIDIR" [get_ports "DDR_DQ[8]"]
set_property iostandard "SSTL15_T_DCI" [get_ports "DDR_DQ[7]"]
set_property PACKAGE_PIN "A3" [get_ports "DDR_DQ[7]"]
set_property slew "FAST" [get_ports "DDR_DQ[7]"]
set_property PIO_DIRECTION "BIDIR" [get_ports "DDR_DQ[7]"]
set_property iostandard "SSTL15_T_DCI" [get_ports "DDR_DQ[6]"]
set_property PACKAGE_PIN "C3" [get_ports "DDR_DQ[6]"]
set_property slew "FAST" [get_ports "DDR_DQ[6]"]
set_property PIO_DIRECTION "BIDIR" [get_ports "DDR_DQ[6]"]
set_property iostandard "SSTL15_T_DCI" [get_ports "DDR_DQ[5]"]
set_property PACKAGE_PIN "A4" [get_ports "DDR_DQ[5]"]
set_property slew "FAST" [get_ports "DDR_DQ[5]"]
set_property PIO_DIRECTION "BIDIR" [get_ports "DDR_DQ[5]"]
set_property iostandard "SSTL15_T_DCI" [get_ports "DDR_DQ[4]"]
set_property PACKAGE_PIN "B4" [get_ports "DDR_DQ[4]"]
set_property slew "FAST" [get_ports "DDR_DQ[4]"]
set_property PIO_DIRECTION "BIDIR" [get_ports "DDR_DQ[4]"]
set_property iostandard "SSTL15_T_DCI" [get_ports "DDR_DQ[3]"]
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

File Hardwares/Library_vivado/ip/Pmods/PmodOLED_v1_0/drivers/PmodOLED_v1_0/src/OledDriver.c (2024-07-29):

/************************************************************************/
/*                                                                      */
/*  OLED_Driver.c   -- Graphics Driver Library for OLED Display         */
/*                                                                      */
/************************************************************************/
/*  Author:     Gene Apperson                                           */
/*  Copyright 2011, Digilent Inc.                                       */
/************************************************************************/
/*
  This library is free software; you can redistribute it and/or
  modify it under the terms of the GNU Lesser General Public
  License as published by the Free Software Foundation; either
  version 2.1 of the License, or (at your option) any later version.

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
  You should have received a copy of the GNU Lesser General Public
  License along with this library; if not, write to the Free Software
  Foundation, Inc., 51 Franklin St, Fifth Floor, Boston, MA  02110-1301  USA
*/
/************************************************************************/
/*  Module Description:                                                 */
/*                                                                      */
/*  This is part of the device driver software for the OLED bit mapped  */
/*  display on the Digilent Basic I/O Shield. This module contains the  */
/*  initialization functions and basic display control functions.       */
/*                                                                      */
/************************************************************************/
/*  Revision History:                                                   */
/*                                                                      */
/*  04/29/2011(GeneA): Created                                          */
/*  08/03/2011(GeneA): added functions to shut down the display and to  */
/*      turn the display on and off.                                    */
/*  06/20/2016(ArtVVB): edited for PmodOLED IP                          */
/*                                                                      */
/*  12/15/2016(jPeyron) edited for better use for OnboardOLED in        */
/*                      as well as inverting the white and black        */
/*  10/31/2017(ArtVVB): 2016.4 Maintenance, replaced OLED_Delay with    */
/*                      usleep                                          */
/*  08/09/2023(MihaiR): edited the init and term functions so they      */
/*                      have the proper instructions for startup and    */
/*                      shut down while minimizing backpowering, some   */
/*                      of the functions had minor changes such as      */
/*                      changing the order in which                     */
/*                      their instructions were called                  */
/************************************************************************/


/* ------------------------------------------------------------ */
/*              Include File Definitions                        */
/* ------------------------------------------------------------ */

#include "PmodOLED.h"
#include "ChrFont0.c"
#include "FillPat.c"
#include "sleep.h"

/* ------------------------------------------------------------ */
/*              Local Symbol Definitions                        */
/* ------------------------------------------------------------ */

#define cmdOledDisplayOn       0xAF
#define cmdOledDisplayOff      0xAE
#define cmdOledSegRemap        0xA1 //map column 127 to SEG0
#define cmdOledComDir          0xC8 //scan from COM[N-1] to COM0
#define cmdOledComConfig       0xDA //set COM hardware configuration
#define DispContrast1          0x81
#define DispContrast2          0x0F
#define SetSegRemap            0xA0
#define SetScanDirection       0xC0
#define SetLowerColumnAddress  0xDA
#define LowerColumnAddress     0x02

/* Setting pins based on DSPI_SS pin plus offset to get to lower 4 pins
** on pmod connector
*/
#define DataCmd     0x1
#define Reset       0x2
#define VbatCtrl    0x4
#define VddCtrl     0x8

/* ------------------------------------------------------------ */
/*              Local Variables                                 */
/* ------------------------------------------------------------ */

/* This array is the offscreen frame buffer used for rendering.
** It isn't possible to read back frome the OLED display device,
** so display data is rendered into this offscreen buffer and then
** copied to the display.
*/
extern const u8 rgbFillPat[];

/* ------------------------------------------------------------ */
/*              Forward Declarations                            */
/* ------------------------------------------------------------ */

void    OLED_HostInit   (PmodOLED *InstancePtr, u32 GPIO_Address, u32 SPI_Address);
void    OLED_HostTerm   (PmodOLED *InstancePtr);
void    OLED_DevInit    (PmodOLED *InstancePtr,u8 orientation, u8 invert);
void    OLED_DevTerm    (PmodOLED *InstancePtr);
void    OLED_DvrInit    (PmodOLED *InstancePtr);

void    OLED_PutBuffer  (PmodOLED *InstancePtr, int cb, uint8_t *rgbTx);
//uint8_t   Spi2PutByte     (uint8_t bVal);

/* ------------------------------------------------------------ */
/*              Procedure Definitions                           */
/* ------------------------------------------------------------ */
/***    OLED_Init
**
**  Parameters:
**      InstancePtr - pointer to SPI handler and OLED data
**
**  Return Value:
**      none
**
**  Errors:
**      none
**
**  Description:
**      Initialize the OLED display subsystem.
*/

void OLED_Init(PmodOLED *InstancePtr, u32 GPIO_Address, u32 SPI_Address, u8 orientation, u8 invert)
{

    /* Init the memory variables used to control access to the
    ** display.
    */
    OLED_DvrInit(InstancePtr);
    
    /* Init the PIC32 peripherals used to talk to the display.
    */
    OLED_HostInit(InstancePtr, GPIO_Address, SPI_Address);

    /* Init the OLED display hardware.
    */
    OLED_DevInit(InstancePtr, orientation, invert);

    /* Clear the display.
    */
    OLED_Clear(InstancePtr);

}

/* ------------------------------------------------------------ */
/***    OLED_Term
**
**  Parameters:
**      InstancePtr - pointer to SPI handler and OLED data
**
**  Return Value:
**      none
**
**  Errors:
**      none
**
**  Description:
**      Shut down the OLED display.
*/

void OLED_Term(PmodOLED *InstancePtr)
{

    /* Shut down the OLED display hardware.
    */
    OLED_DevTerm(InstancePtr);

    /* Release the PIC32 peripherals being used.
    */
    OLED_HostTerm(InstancePtr);

}
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

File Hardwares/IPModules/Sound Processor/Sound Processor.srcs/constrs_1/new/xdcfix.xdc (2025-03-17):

## This file is a general .xdc for the Nexys A7
## To use it in a project:
## - uncomment the lines corresponding to used pins
## - rename the used ports (in each line, after get_ports) according to the top level signal names in the project

## Clock signal
set_property -dict { PACKAGE_PIN E3    IOSTANDARD LVCMOS33 } [get_ports { clk }]; #IO_L12P_T1_MRCC_35 Sch=clk100mhz
create_clock -add -name sys_clk_pin -period 10.00 -waveform {0 5} [get_ports {clk}];


##Switches

set_property -dict { PACKAGE_PIN J15   IOSTANDARD LVCMOS33 } [get_ports { reset }]; #IO_L24N_T3_RS0_15 Sch=sw[0]
#set_property -dict { PACKAGE_PIN L16   IOSTANDARD LVCMOS33 } [get_ports { SW[1] }]; #IO_L3N_T0_DQS_EMCCLK_14 Sch=sw[1]
#set_property -dict { PACKAGE_PIN M13   IOSTANDARD LVCMOS33 } [get_ports { SW[2] }]; #IO_L6N_T0_D08_VREF_14 Sch=sw[2]
#set_property -dict { PACKAGE_PIN R15   IOSTANDARD LVCMOS33 } [get_ports { SW[3] }]; #IO_L13N_T2_MRCC_14 Sch=sw[3]
#set_property -dict { PACKAGE_PIN R17   IOSTANDARD LVCMOS33 } [get_ports { SW[4] }]; #IO_L12N_T1_MRCC_14 Sch=sw[4]
#set_property -dict { PACKAGE_PIN T18   IOSTANDARD LVCMOS33 } [get_ports { SW[5] }]; #IO_L7N_T1_D10_14 Sch=sw[5]
#set_property -dict { PACKAGE_PIN U18   IOSTANDARD LVCMOS33 } [get_ports { SW[6] }]; #IO_L17N_T2_A13_D29_14 Sch=sw[6]
#set_property -dict { PACKAGE_PIN R13   IOSTANDARD LVCMOS33 } [get_ports { SW[7] }]; #IO_L5N_T0_D07_14 Sch=sw[7]
#set_property -dict { PACKAGE_PIN T8    IOSTANDARD LVCMOS18 } [get_ports { SW[8] }]; #IO_L24N_T3_34 Sch=sw[8]
#set_property -dict { PACKAGE_PIN U8    IOSTANDARD LVCMOS18 } [get_ports { SW[9] }]; #IO_25_34 Sch=sw[9]
#set_property -dict { PACKAGE_PIN R16   IOSTANDARD LVCMOS33 } [get_ports { SW[10] }]; #IO_L15P_T2_DQS_RDWR_B_14 Sch=sw[10]
#set_property -dict { PACKAGE_PIN T13   IOSTANDARD LVCMOS33 } [get_ports { SW[11] }]; #IO_L23P_T3_A03_D19_14 Sch=sw[11]
#set_property -dict { PACKAGE_PIN H6    IOSTANDARD LVCMOS33 } [get_ports { SW[12] }]; #IO_L24P_T3_35 Sch=sw[12]
#set_property -dict { PACKAGE_PIN U12   IOSTANDARD LVCMOS33 } [get_ports { SW[13] }]; #IO_L20P_T3_A08_D24_14 Sch=sw[13]
#set_property -dict { PACKAGE_PIN U11   IOSTANDARD LVCMOS33 } [get_ports { SW[14] }]; #IO_L19N_T3_A09_D25_VREF_14 Sch=sw[14]
#set_property -dict { PACKAGE_PIN V10   IOSTANDARD LVCMOS33 } [get_ports { SW[15] }]; #IO_L21P_T3_DQS_14 Sch=sw[15]


## LEDs

#set_property -dict { PACKAGE_PIN H17   IOSTANDARD LVCMOS33 } [get_ports { mode1[0] }]; #IO_L18P_T2_A24_15 Sch=led[0]
#set_property -dict { PACKAGE_PIN K15   IOSTANDARD LVCMOS33 } [get_ports { mode1[1] }]; #IO_L24P_T3_RS1_15 Sch=led[1]
#set_property -dict { PACKAGE_PIN J13   IOSTANDARD LVCMOS33 } [get_ports { addr[2] }]; #IO_L17N_T2_A25_15 Sch=led[2]
#set_property -dict { PACKAGE_PIN N14   IOSTANDARD LVCMOS33 } [get_ports { addr[3] }]; #IO_L8P_T1_D11_14 Sch=led[3]
#set_property -dict { PACKAGE_PIN R18   IOSTANDARD LVCMOS33 } [get_ports { addr[4] }]; #IO_L7P_T1_D09_14 Sch=led[4]
#set_property -dict { PACKAGE_PIN V17   IOSTANDARD LVCMOS33 } [get_ports { addr[5] }]; #IO_L18N_T2_A11_D27_14 Sch=led[5]
#set_property -dict { PACKAGE_PIN U17   IOSTANDARD LVCMOS33 } [get_ports { addr[6] }]; #IO_L17P_T2_A14_D30_14 Sch=led[6]
#set_property -dict { PACKAGE_PIN U16   IOSTANDARD LVCMOS33 } [get_ports { addr[7] }]; #IO_L18P_T2_A12_D28_14 Sch=led[7]
#set_property -dict { PACKAGE_PIN V16   IOSTANDARD LVCMOS33 } [get_ports { addr[8] }]; #IO_L16N_T2_A15_D31_14 Sch=led[8]
#set_property -dict { PACKAGE_PIN T15   IOSTANDARD LVCMOS33 } [get_ports { addr[9] }]; #IO_L14N_T2_SRCC_14 Sch=led[9]
#set_property -dict { PACKAGE_PIN U14   IOSTANDARD LVCMOS33 } [get_ports { addr[10] }]; #IO_L22P_T3_A05_D21_14 Sch=led[10]
#set_property -dict { PACKAGE_PIN T16   IOSTANDARD LVCMOS33 } [get_ports { addr[11] }]; #IO_L15N_T2_DQS_DOUT_CSO_B_14 Sch=led[11]
#set_property -dict { PACKAGE_PIN V15   IOSTANDARD LVCMOS33 } [get_ports { addr[12] }]; #IO_L16P_T2_CSI_B_14 Sch=led[12]
#set_property -dict { PACKAGE_PIN V14   IOSTANDARD LVCMOS33 } [get_ports { addr[13] }]; #IO_L22N_T3_A04_D20_14 Sch=led[13]
#set_property -dict { PACKAGE_PIN V12   IOSTANDARD LVCMOS33 } [get_ports { addr[14] }]; #IO_L20N_T3_A07_D23_14 Sch=led[14]
#set_property -dict { PACKAGE_PIN V11   IOSTANDARD LVCMOS33 } [get_ports { addr[15] }]; #IO_L21N_T3_DQS_A06_D22_14 Sch=led[15]

#set_property -dict { PACKAGE_PIN R12   IOSTANDARD LVCMOS33 } [get_ports { debug }]; #IO_L5P_T0_D06_14 Sch=led16_b
#set_property -dict { PACKAGE_PIN M16   IOSTANDARD LVCMOS33 } [get_ports { sclk }]; #IO_L10P_T1_D14_14 Sch=led16_g
##set_property -dict { PACKAGE_PIN G14   IOSTANDARD LVCMOS33 } [get_ports { LED17_B }]; #IO_L15N_T2_DQS_ADV_B_15 Sch=led17_b
#set_property -dict { PACKAGE_PIN R11   IOSTANDARD LVCMOS33 } [get_ports { LED17_G }]; #IO_0_14 Sch=led17_g
#set_property -dict { PACKAGE_PIN N16   IOSTANDARD LVCMOS33 } [get_ports { LED17_R }]; #IO_L11N_T1_SRCC_14 Sch=led17_r


##7 segment display
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

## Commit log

2024-05-25 Add KiCad
    [Audio.kicad_sch, Audio.sch, DDR3.kicad_sch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]
2024-06-05 New updates
    new notes and folders
    [10029449-111RLF.step, 1140084168.step, 4-1734839-0.stp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]
2024-07-29 7/28 update
    Update various PCB and change the organization of the file
    [10029449-111RLF.step, 1140084168.step, 4-1734839-0.stp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]
2024-08-02 8/1 update
    [DFTBoard-BOTTOM.gbr, DFTBoard-B_Mask.gbr, DFTBoard-B_Paste.gbr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]
2024-09-14 Hardware and Vivado change
    change to hardware
    [cmake_lib_configs.txt]
2024-12-27 12/26 update
    Prototype board added
    [10029449-111RLF.step, 1140084168.step, 4-1734839-0.stp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]
2025-01-04 1/4 update
    update the breadboard version
    [473092651.stp, DBV0006A.stp, FPGA MIO.kicad_sch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]
2025-01-04 1/4 DDR3 test update
    add the ddr3 test file for kicad
    [473092651.stp, DBV0006A.stp, FPGA MIO.kicad_sch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]
2025-01-05 Added libraries to local project path and imported DDR3
    [FBGA96_8X14_MRN.step, FPGA MIO.kicad_sch, FPGA.kicad_sch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]
2025-01-05 group ddr pins by function in symbol
    group ddr pins by function in symbol
    [Power.kicad_sch, RAM.kicad_sch, SYNC-VT.kicad_pcb]
2025-01-05 Resistor Footprints
    - Fixed resistor footprints
    - Re-added 3D models
    - Routed 1.5V reg
    [FPGA MIO.kicad_sch, FPGA.kicad_sch, FPGApwr.kicad_sch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]
2025-03-17 3/16 update
    [10029449-111RLF.step, 1140084168.step, 4-1734839-0.stp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]
2025-05-31 5/31 update
    [10029449-111RLF.step, 1140084168.step, 4-1734839-0.stp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]

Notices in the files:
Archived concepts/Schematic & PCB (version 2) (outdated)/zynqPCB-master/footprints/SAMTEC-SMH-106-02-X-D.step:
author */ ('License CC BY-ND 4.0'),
